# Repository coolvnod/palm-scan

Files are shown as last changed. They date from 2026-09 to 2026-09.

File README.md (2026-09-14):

# palm-scan

**Open palm-vein scanning — hardware, firmware and our own recognition model.** Hold your hand over the sensor; it reads the vein pattern under your skin and identifies you. Access control (a door release) is the first demo application, not the point.

<p align="center">
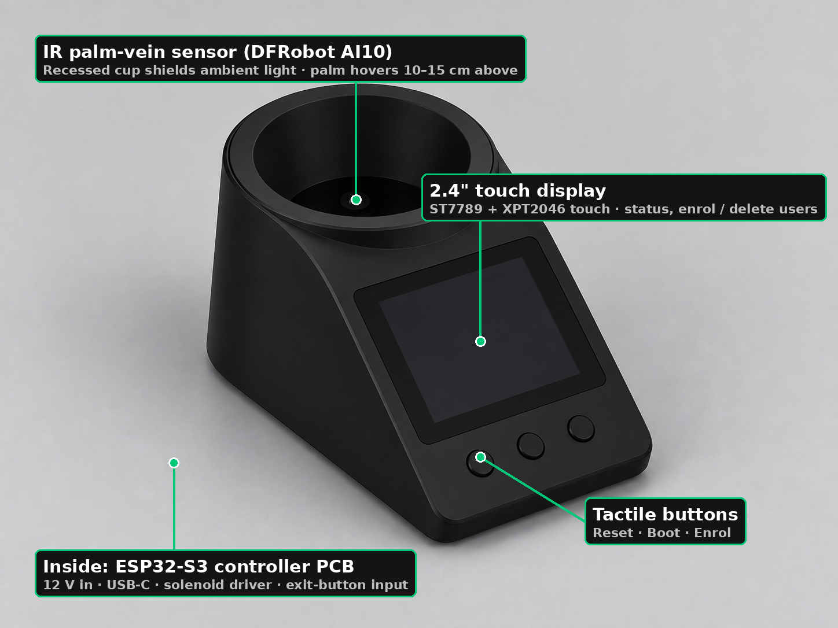
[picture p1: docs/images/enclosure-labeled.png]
palm-scan enclosure concept, labeled
  
</p>

No cards, no PINs, no fingerprints. Veins are *inside* the body — a photo of your hand, a silicone copy, or a lifted print does nothing. And the pattern only shows up when blood is flowing, so the scanner gets liveness detection for free. The goal is to understand and build the whole stack: NIR acquisition → preprocessing → feature extraction → matching — not just wire up a module.

| | |
|---|---|
| **Status** | Schematic **Rev 2.4** — reviewed twice, ERC clean, netlist verified. **PCB layout is next.** |
| **Controller** | ESP32-S3-WROOM-1 (N8R2), custom 2-layer PCB, 46 parts |
| **Sensor** | DFRobot AI10 (SEN0677) binocular palm-vein / face module, UART |
| **UI** | 2.4" 240×320 TFT + resistive touch, 2 panel LEDs, piezo buzzer |
| **Demo output** | 12 V fail-secure solenoid (door-release demo), MOSFET-driven, plus an exit button input |
| **Power** | 12 V 2 A adapter → polyfuse → reverse diode → TVS → 3.3 V + 5 V switching regulators |
| **Roadmap** | Firmware (ESP-IDF) → PCB → bring-up → **own CNN matcher** trained on NIR frames pulled from the sensor |

---

## How palm-vein recognition works

Blood carries haemoglobin. In the near-infrared window (**700–900 nm**) haemoglobin absorbs light much more strongly than the tissue around it. Shine NIR at a palm, and the veins show up as **dark shadows** on a camera that can see NIR — even though they're invisible to your eye. NIR penetrates only ~3.5 mm at 850 nm, which is exactly deep enough to reach the subcutaneous veins and no further.

<p align="center">
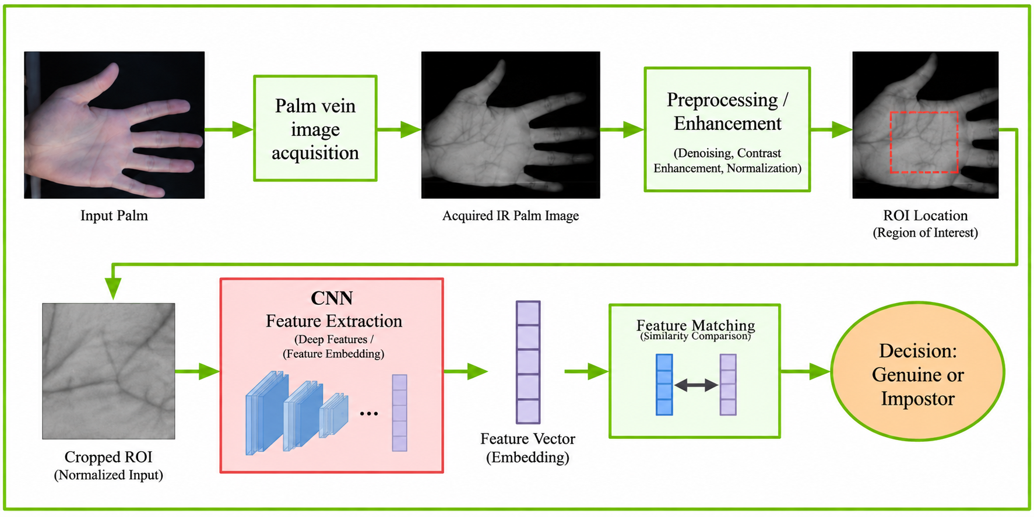
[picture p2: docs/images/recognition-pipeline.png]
Palm-vein recognition pipeline
  
</p>

Every palm-vein system, from a ₹3,000 module to a Fujitsu PalmSecure, runs the same four stages:

| Stage | What happens | In palm-scan |
|---|---|---|
| **1. Acquisition** | NIR LEDs illuminate the palm from the *same side* as the camera (reflection method — transmission needs LEDs bright enough to shine *through* your hand). | AI10 module: NIR LED array + NIR-sensitive camera, 240×320 output. |
| **2. Preprocessing / ROI** | Denoise, normalise contrast, then cut out a fixed **Region of Interest** — usually a square anchored on the finger-web valleys so the same patch of palm is compared every time, regardless of hand position. | Done inside the AI10 today. Our own ROI extraction is part of the CNN phase. |
| **3. Feature extraction** | Turn the ROI into a compact signature. Classical: Gabor filters, LBP, line/curvature detectors. Modern: a **CNN embedding** — a vector of a few hundred numbers. | AI10 built-in matcher now → own CNN embedding later. |
| **4. Matching** | Compare the signature with the enrolled templates. Hamming / cosine distance below a threshold → *genuine*, else *impostor*. Tuned on **EER** (equal error rate — where false accepts = false rejects). | Threshold set inside the AI10; `VERIFY` returns user ID + score. |

Why palm veins are a strong biometric — from Wu et al.'s 2019 review in *IET Biometrics*:

- **Uniqueness:** vein networks differ even between identical twins and between your own two hands.
- **Liveness:** no blood flow, no image. A severed or fake hand fails.
- **Robust:** dirt, cuts, wet or dry skin don't change what's *under* the skin.
- **Contactless:** nothing to touch, nothing to smudge.
- **Open problems** the paper flags — and that this project will run into: cheap acquisition hardware, ROI location without a hand guide, skin changes with age, and the fact that the best published deep-learning results are held back by tiny public datasets (CASIA ≈ 7,200 images, PolyU ≈ 6,000, VERA ≈ 2,200).

---

## System architecture

```mermaid
flowchart LR
    subgraph Field["Outside the box"]
        ADP["12 V 2 A adapter"]
        LOCK["12 V solenoid<br/>(door-release demo)"]
        EXIT["Exit button<br/>(inside room)"]
        PANEL["Panel LEDs<br/>green / red"]
    end

    subgraph PCB["palm-scan PCB (ESP32-S3)"]
        PWR["F1 polyfuse → D1 → D7 TVS<br/>+12V → R-78E 3.3 V / 5 V"]
        MCU["ESP32-S3-WROOM-1<br/>Wi-Fi · BLE · native USB"]
        DRV["Q1 AO3400A + D2 SS54<br/>lock driver + flyback"]
        USB["USB-C<br/>ESD + CC pull-downs"]
    end

    subgraph Modules["Plug-in modules"]
        AI10["AI10 palm-vein sensor<br/>UART 115200"]
        TFT["2.4-inch TFT + touch<br/>SPI"]
    end

    ADP --> PWR --> MCU
    PWR -- "+5V" --> AI10
    PWR -- "+12V" --> DRV --> LOCK
    AI10 <-- "UART1" --> MCU
    TFT <-- "FSPI" --> MCU
    MCU -- "IO4 LOCK_EN" --> DRV
    EXIT --> MCU
    MCU --> PANEL
    USB <--> MCU
```

**New here?** Read the [Wiring & Components Guide (PDF)](docs/palm-scan-wiring-guide.pdf) — every cable and part explained in plain words, with an A3 fold-out wiring diagram.

**Design decisions worth knowing** (full reasoning in [`docs/DESIGN_REVIEW.md`](docs/DESIGN_REVIEW.md)):

- **Solenoid is fed *after* the reverse-protection diode.** Rev 2.0 had it before — plugging the adapter in backwards would have shorted through the MOSFET's body diode. Caught in review.
- **Sensor runs on 5 V, not 12 V.** The AI10 accepts 5–12 V; at 12 V its internal regulator cooks. 5 V keeps it cool and makes the adapter's exact voltage irrelevant.
- **Display's SDO pin is left unconnected.** The ST7789 on these modules doesn't release MISO when deselected, so it fights the touch controller. Well-known trap; days lost by many.
- **Everything near the MCU is 3.3 V.** Display powered from +3V3, sensor UART assumed 3.3 V (measured before connection — see bring-up).
- **Fail-secure + watchdog.** If the demo output drives a door: power cut = locked, so the door must have a mechanical handle inside (fire-safety rule, not a preference). Firmware caps any release at 5 s with a hardware task watchdog — the solenoid is intermittent-duty and will burn if held on.

### GPIO map

| GPIO | Net | Role |
|---|---|---|
| IO4 | `LOCK_EN` | Solenoid driver gate (via 100 Ω, 10 k pull-down) |
| IO5 | `BUZZER` | Passive piezo |
| IO6 | `EXIT_BTN` | Exit button, RC-debounced |
| IO7 | `USB_DET` | VBUS sense, 100k/150k divider |
| IO8–IO14 | SPI + `TOUCH_IRQ` `TOUCH_CS` `TFT_CS` `TFT_DC` | Display and touch on FSPI (IOMUX pins) |
| IO17 / IO18 | `SEN_RX` / `SEN_TX` | UART1 to AI10 |
| IO19 / IO20 | `USB_D-` / `USB_D+` | Native USB |
| IO21 | `TFT_RST` | Display reset |
| IO1 / IO2 | `LED_OK` / `LED_DENY` | Panel LEDs |
| IO43 / IO44 | `TXD0` / `RXD0` | Debug UART header |
| IO0 | `BOOT` | Strapping — button only |
| IO3, IO45, IO46 | — | Strapping — deliberately unconnected |

---

## Repository layout

```
palm-scan/
├── README.md
├── docs/
│   ├── palm-scan-wiring-guide.pdf   Illustrated wiring & components guide (A3 fold-out) — start here
│   ├── wiring-guide/       Source for the guide (Python → SVG → PDF)
│   ├── COMPONENTS.md       BOM in three lists: fab-assembled / hand-soldered / off-board
│   ├── NETLIST.md          Plain-words net table — the source of truth the schematic is checked against
│   ├── POWER_BUDGET.md     Rail currents, derating, fuse/adapter analysis, trace widths
│   ├── DATASHEETS.md       Numbers extracted from every datasheet, with page refs
│   ├── DESIGN_REVIEW.md    Two review rounds (19 findings) and what changed because of each
│   ├── datasheets/         Source PDFs
│   └── images/
├── hardware/
│   └── kicad/              KiCad 9 project — 10 hierarchical sheets, generated from Python
│       ├── gen_schematic.py        Writes all .kicad_sch files from a parts/nets table
│       ├── check_netlist.py        Diffs KiCad's exported netlist against docs/NETLIST.md
│       ├── make_wiring_diagram.py  Off-board cable diagram (SVG/PDF)
│       ├── palm-scan.pdf           Schematic, all sheets
│       └── palm-scan-wiring.pdf    Cable diagram
├── firmware/               ESP-IDF application — not started
└── ml/                     CNN matcher — not started
```

**The schematic is code.** `gen_schematic.py` holds the parts and nets and emits the KiCad files; `check_netlist.py` then proves KiCad's own netlist export matches the human-readable `NETLIST.md` pin-for-pin (153/153). Change the table, rerun both, and the schematic, the docs and the verification stay in sync.

```bash
cd hardware/kicad
python3 gen_schematic.py                                   # regenerate sheets
kicad-cli sch erc  --output erc.txt        palm-scan.kicad_sch
kicad-cli sch export netlist --output palm-scan.net palm-scan.kicad_sch
kicad-cli sch export pdf --output palm-scan.pdf palm-scan.kicad_sch
python3 check_netlist.py                                   # must print "0 problems"
```

Requires KiCad ≥ 9.0 (`kicad-cli` on PATH) and Python 3.10+.

---

## Roadmap

| Phase | Deliverable | State |
|---|---|---|
| 1 | Schematic, BOM, power budget, two design reviews | ✅ Rev 2.4 |
| 2 | Firmware: AI10 UART driver, enrol/verify flow, TFT UI, output state machine + watchdog | ⬜ |
| 3 | PCB layout, DRC, Gerbers, order (JLCPCB assembly for the 32 SMD parts) | ⬜ |
| 4 | Bring-up: rail checks, sensor level check, first recognition on the bench | ⬜ |
| 5 | Enclosure (the render above is the concept; CAD to follow) | ⬜ |
| 6 | **Own CNN matcher** — see below | ⬜ |

Firmware comes before PCB on purpose: the sensor and display can be driven from an ESP32-S3 devkit on a breadboard today, so the protocol and UI get debugged while the board is being made, not after.

### Phase 6 — a CNN of our own

The AI10 does its matching on-chip and we don't get to see how. That's fine for a demo, but the point of this project is to build and understand the recognition itself. The plan:

1. **Harvest images.** The AI10's protocol has `MID_SNAP&UPLOAD_IMAGE` (0x71): it captures and streams a 240×320 JPEG over UART in 1 KB packets. So the sensor doubles as an NIR camera for dataset collection — no extra hardware.
2. **Build a dataset.** Our own small one (multiple sessions, both hands, varied height and angle — the paper's warning about tiny datasets applies), plus a public set (CASIA-MS-Palmprint or PolyU) for pre-training.
3. **ROI extraction.** Finger-valley keypoints → fixed square crop, following the classical method the review describes. This is where most of the real-world failures live.
4. **Train an embedding network.** Small CNN (MobileNet-class) trained with a metric loss (triplet / ArcFace) so genuine pairs land close and impostors far apart. Training runs on Kaggle GPUs, never on the laptop.
5. **Evaluate properly.** ROC curve, EER, FAR at fixed FRR — not "accuracy".
6. **Deploy.** Two options, decided by the numbers: quantised INT8 on the ESP32-S3 via ESP-DL (the S3 has vector instructions for exactly this), or on a small Linux SBC if the model won't fit. The AI10 stays as a reference matcher to benchmark against either way.

---

## Bring-up checklist (before first power-on)

Read [`docs/POWER_BUDGET.md`](docs/POWER_BUDGET.md) §7 first. Non-negotiable items:

- [ ] Adapter is **12 V regulated, ≥ 1.5 A** — 9 V will not run the regulators.
- [ ] Measure the AI10's green TX wire idle level **before** plugging it in — must be ≤ 3.6 V. If it reads 5 V, fit a divider; the ESP32 is not 5 V tolerant.
- [ ] Confirm the display module's pin order against its silkscreen (the manual gives names, not positions).
- [ ] Solenoid: confirm intermittent vs continuous duty on the listing; measure coil current — if > 0.8 A move F1 to a 3 A-hold part.
- [ ] Buzzer must be a **passive piezo**, not a magnetic one — the pin drives it directly.
- [ ] Use **J1 or J8** for power, never both.
- [ ] If wired to a door: it has a handle on the inside.

Tools that matter: a multimeter (not optional), `idf.py monitor`, and `kicad-cli` for regenerating outputs.

---

## References

- W. Wu, S. J. Elliott, S. Lin, S. Sun, Y. Tang, "Review of palm vein recognition," *IET Biometrics*, vol. 9, no. 1, pp. 1–10, 2020. doi:10.1049/iet-bmt.2019.0034
- DFRobot SEN0677 wiki — https://wiki.dfrobot.com/sen0677/ · protocol manual in [`docs/datasheets/`](docs/datasheets/)
- Espressif, *ESP32-S3-WROOM-1 Datasheet* v1.8 · ESP-DL — https://github.com/espressif/esp-dl
- RECOM R-78E series; Alpha & Omega AO3400A; Vishay SS34 — all in [`docs/datasheets/`](docs/datasheets/)

---

## Makers

- [Ashmita K Rao](https://github.com/ashmita1032-prog)
- [Adithya Satish](https://github.com/adithyasathish10)
- [Vinod Kumar](https://github.com/coolvnod)

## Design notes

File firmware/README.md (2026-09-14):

# firmware

ESP-IDF application for the palm-scan controller. Not started.

Planned modules, in build order:
1. `ai10/` — UART driver for the DFRobot AI10: frame codec (`EF AA id len data xor`), `RESET`, `GET_STATUS`, `VERIFY`, `ENROLL`, `DEL_USER`, `SNAP&UPLOAD_IMAGE`. Wait for `NOTE:READY` after power-up before sending anything.
2. `lock/` — solenoid state machine. Hard 5 s cap per unlock, task watchdog, `LOCK_EN` low on any fault or reset.
3. `ui/` — LVGL on the 2.4" TFT (ST7789/ILI9341 autodetect) + XPT2046 touch. Screens: idle, recognised, denied, enrol, user list.
4. `app/` — glue: exit button, panel LEDs, buzzer, USB detect, logging.

Develop on an ESP32-S3 devkit + breadboard first; the custom PCB is not required for any of this.

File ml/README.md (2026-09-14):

# ml

Own palm-vein matcher (CNN embedding). Not started — see README.md → Roadmap → Phase 6.

Planned layout:
- `capture/` — pull 240×320 NIR JPEGs from the AI10 over UART (`0x71`), tag by user/session/hand.
- `roi/` — finger-valley keypoints → normalised square crop.
- `train/` — Kaggle notebooks: MobileNet-class backbone, triplet/ArcFace loss, pre-train on CASIA/PolyU, fine-tune on our set.
- `eval/` — ROC, EER, FAR@FRR.
- `deploy/` — INT8 quantisation, ESP-DL export.

Training runs on Kaggle GPUs only.

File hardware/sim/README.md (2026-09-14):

# Circuit simulations (ngspice — the engine inside KiCad)

| File | What |
|---|---|
| `lock_driver.cir` | Solenoid driver: Q1 AO3400A (VDMOS model fitted to the datasheet) + D2 SS54 flyback + 12 V / 15 Ω / 60 mH coil, driven by a 3.3 V GPIO pulse. Two runs: with D2, and without D2 (Q1 avalanche modelled at 32 V). |
| `run_sim.py` | Runs the netlist through `libngspice` (or the `ngspice` CLI if installed), prints the key numbers, writes `lock_driver.png`. |

```bash
python3 run_sim.py
```

Results, Rev 2.4 values (2026-09-14): gate 3.26 V · coil 0.78 A, L/R 3.8 ms · Rds(on) 40 mΩ, 24 mW in Q1 ·
turn-off with D2 peaks 12.4 V (D2 carries 0.79 A) · without D2, Q1 avalanches at 32 V and absorbs 21 mJ per release.

Coil inductance is an assumption (60 mH); measure the real lock and update `LCOIL`.

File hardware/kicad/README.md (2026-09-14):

# kicad/ — palm-scan Rev 2 schematic

| File | What |
|---|---|
| `palm-scan.kicad_pro` / `.kicad_sch` | Root sheet. Open with `kicad palm-scan.kicad_pro` |
| `power_in`, `power_reg`, `mcu`, `reset_boot`, `usb`, `lock`, `display`, `exit`, `buzzer` `.kicad_sch` | Sub-sheets (pages 2–10), A4 |
| `palmscan.kicad_sym` + `sym-lib-table` | Project symbol library: stock KiCad symbols scaled 1.5× for readability. Footprints are unchanged. |
| `palm-scan.pdf` | Rendered schematic, 10 pages |
| `palm-scan.net` | KiCad's exported netlist |
| `erc.txt` | Last ERC report (0 errors, 0 warnings) |
| `gen_schematic.py` | Generator. The `PARTS` list is the netlist. |
| `check_netlist.py` | Diffs `palm-scan.net` against `../../docs/NETLIST.md` |

## Regenerate after a change

```
python3 gen_schematic.py
kicad-cli sch erc --output erc.txt palm-scan.kicad_sch
kicad-cli sch export netlist --format kicadsexpr --output palm-scan.net palm-scan.kicad_sch
python3 check_netlist.py
kicad-cli sch export pdf --output palm-scan.pdf palm-scan.kicad_sch
```

Nets are **global labels** — the same name on any page is the same wire.
Pages are defined in `PAGES`; a box that does not fit its page fails loudly.

Edit `PARTS` in the generator *and* the table in `../../docs/NETLIST.md` — the checker
exists precisely so the two can't drift apart silently.

## If you edit in the KiCad GUI instead

Fine — but then stop running the generator, it will overwrite your edits.
Move the wires around, keep the net names.

## One-sheet wiring diagram

`palm-scan-wiring.pdf` / `.svg` — every connection drawn as a wire, ESP32 in the middle.
Generated from `palm-scan.net` by `make_wiring_diagram.py` (needs `netlistsvg` from npm and
`cairosvg` from pip; `wiring_skin.svg` is the box/tag style). Not editable in KiCad — it is a
*picture* of the netlist and can never disagree with the schematic. Regenerate after any change:

```
kicad-cli sch export netlist --format kicadsexpr --output palm-scan.net palm-scan.kicad_sch
python3 make_wiring_diagram.py /path/to/node_modules/.bin/netlistsvg
```

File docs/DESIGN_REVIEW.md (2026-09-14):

# DESIGN_REVIEW.md — Rev 2 schematic, senior design review (2026-09-13)

> **Status: all 7 fixes applied → Rev 2.1.** ERC 0/0, netlist 131/131, scripted pass 2 clean. Layout notes below still apply.

Two passes: (1) block-by-block read as a reviewer, (2) scripted checks on KiCad's own
exported netlist (`../hardware/kicad/check_netlist.py` + ad-hoc checks). ERC 0/0. Netlist 125/125.

Severity: 🔴 will break hardware  🟠 will cause a bug you'll chase for days  🟡 should fix  🟢 fine

---

## 🔴 1. Plugging the adapter in backwards destroys Q1 and D2

**What happens.** D1 protects the "+12V" rail. But the lock is fed from `VIN_12V` — *before* D1.
Reverse the adapter and current flows: GND → Q1's body diode → LOCK_SW → D2 → VIN_12V.
That's a dead short across the adapter through two tiny parts. They die in under a second.

**Why it slipped in.** COMPONENTS.md wanted the lock's inrush kept away from C1. Good idea,
wrong place — it moved the lock outside the protection.

**Fix.** Feed the lock from `+12V` (after D1). D1 is rated 3 A; the lock's 2 A inrush is fine.
Change J3 pin 1 and D2 cathode from `VIN_12V` → `+12V`. Zero new parts.

**Also add a fuse.** F1, 2 A resettable polyfuse, in series right after J1. ₹5. Without it, any
short on the board (including this one) relies on the adapter's protection, which cheap adapters don't have.

## 🟠 2. Display and touch fight over MISO

`SPI_MISO` goes to both the ST7789 (J4 pin 9, SDO) and the XPT2046 touch (J4 pin 13, T_DO).
On these red display boards the ST7789's SDO does **not** release the line when its CS is high.
Result: touch reads garbage, or the screen stops updating after the first touch. Very well-known
problem with this exact module; people spend days on it.

**Fix.** Leave J4 pin 9 unconnected. The firmware never reads from the display. Touch keeps MISO.

## 🟠 3. Sensor is at the very top of its voltage range

AI10 spec: 5–12 V. We give it 12 V. Cheap "12 V" adapters give 12.5–13.5 V with light load.
The sensor's internal regulator then runs hot ("chip heating is normal" says the wiki — at 12 V it's hotter).

**Fix, recommended.** Make U3 a `R-78E5.0-1.0` (1 A, same footprint, same pins) and feed the sensor
from `+5V`. CN1 pin 4 → `+5V`. 5 V rail total ≈ 650 mA, inside 1 A. Sensor runs cool, and the
adapter's exact voltage stops mattering.

## 🟠 4. Solenoid can cook itself if firmware hangs with the lock open

Most 12 V solenoid locks are **intermittent duty** — energised for 10 s max, then they overheat.
If the ESP32 crashes with `LOCK_EN` high, the coil stays on until it burns.

**Fix.** Two layers:
- Firmware: hardware task watchdog (built into ESP-IDF) + a hard cap of 5 s on any unlock.
- Buy: a solenoid rated **continuous duty** if you ever need "hold open". Check the listing.

Also **fail-secure means power cut = door locked.** The door MUST be openable from inside by a
handle. That's a fire-safety rule, not a preference. Never fit this on a door without one.

## 🟡 5. No sign of life if the MCU doesn't boot

"The screen replaces the LEDs" — only after the MCU boots. First power-up with a dead 3.3 V rail
shows nothing at all. One LED + resistor on +3V3 (2 parts, ₹2) tells you the regulator works.

**Fix.** Add D4 (green 0603) + R7 (1 kΩ) from +3V3 to GND.

## 🟡 6. Exit-button wire has no surge protection

The exit button wire runs to the other side of the wall. It's an antenna for static and for
whatever the electrician ran next to it. R6/C11 debounce it; nothing limits current into IO6.

**Fix.** R8, 1 kΩ in series between J5 pin 1 and the IO6 net. Costs ₹1, saves the GPIO.

## 🟡 7. C9 is redundant

C9 (100 nF across RESET) is on the same net as C4 (1 µF, EN to GND). C4 already does the job.
**Fix.** Delete C9. −1 part.

## 🟢 Verified correct (both passes)

- D1 orientation, D2 orientation, Q1 low-side wiring, R2 gate pull-down.
- USB-C: CC1/CC2 5.1 kΩ, D+/D− on IO20/IO19, ESD array, VBUS isolated.
- EN: 10 kΩ + 1 µF per Espressif. BOOT on IO0. Strapping pins IO3/45/46 floating.
- UART crossing: ESP TX → sensor RX (yellow), ESP RX → sensor TX (green). 3.3 V logic both sides.
- 3.3 V rail: 110 µF total, under RECOM's 220 µF limit. C3 on the module's 3V3 pin.
- Every net has ≥2 connections; every GPIO net touches exactly one ESP32 pin.
- R-78E input 7–28 V; 12 V adapter fine. Regulators run cool.

## Things that only matter at PCB layout — write these down for Flux

1. **Antenna keep-out.** ESP32-S3-WROOM-1 antenna end must hang off the board edge, or sit over a
   15 mm no-copper zone on *all* layers. Ignore this and WiFi range drops to a metre.
2. **C3 within 5 mm of U1 pin 2.** Not "nearby". 5 mm.
3. **Lock current traces ≥ 1 mm wide** (J1 → F1 → D1 → J3 → Q1 → GND). 2 A inrush.
4. **Q1 source straight to J1 GND**, not through the ESP32's ground area. Lock return current
   through the MCU ground = resets when the lock fires.
5. **D3 within 5 mm of the USB connector**, on the D+/D− traces, before they go anywhere else.
6. **D1 on a big copper pour** — it's the only part that gets warm.
7. **Display ribbon under 10 cm** or drop SPI to 20 MHz. 40 MHz over a long ribbon = garbage pixels.
8. **PicoBlade CN1 near the board edge** the sensor cable comes from — cable is short.
9. **M3 holes in the corners**, 3.2 mm, with 6 mm keep-out.

## How this project can still fail after all the above (honest list)

| Failure | How likely | What stops it |
|---|---|---|
| Wrong adapter (9 V or 19 V laptop brick) | common | 9 V: sensor and regs OK. 19 V: C1 is 25 V, regs 28 V — survives. Label the socket. |
| Adapter dies at 2 am, door locked | certain, eventually | Inside handle. Non-negotiable. |
| Sensor doesn't recognise wet/cold hands | happens | Firmware fallback: exit button, and long-term a keypad. Hardware can't fix it. |
| Someone unplugs the sensor cable while powered | user error | PicoBlade tolerates hot-plug. Firmware must re-init the sensor when it comes back. |
| Water on the board | outdoor install | Enclosure IP rating. Conformal coat is ₹200. |
| Firmware bug opens the lock | code error | Upstream design: `loop()` is the only path that can unlock. Keep that. |
| Flash corrupted, USB boot dead | rare | J6 UART header. That's why it's there. |
| Solenoid rated wrong (AC, or 24 V) | ordering error | Buy 12 V DC, ≤1 A, continuous duty, and read the listing twice. |
| Board ordered before sim/bring-up plan | you | Bring-up order: power only → check rails → add MCU → USB flash → add display → add sensor → add lock last. |

---

## About Flux

Flux imports **KiCad part libraries only** — not schematics, not projects. There is no
"open the KiCad file in Flux". You would redraw all 34 parts in Flux by hand from NETLIST.md.

Options, ranked:
1. **PCB in KiCad.** Schematic is already here, ERC-clean, footprints assigned. One click to PCB.
   Zero rework. Best choice unless you specifically want Flux's autorouter/AI.
2. **Flux, redraw from NETLIST.md.** ~1–2 hours. Then you have two sources of truth and every
   change must be made twice. Only worth it if you want to learn Flux itself.

## Changes to apply, in one go

| # | Change | Parts |
|---|---|---|
| 1 | Lock + D2 cathode fed from `+12V` instead of `VIN_12V` | 0 |
| 1 | F1 2 A polyfuse after J1 | +1 |
| 2 | J4 pin 9 (display SDO) → no-connect | 0 |
| 3 | U3 → R-78E5.0-1.0; CN1 pin 4 → `+5V` | 0 |
| 5 | D4 LED + R7 1 kΩ on +3V3 | +2 |
| 6 | R8 1 kΩ series on exit button | +1 |
| 7 | Delete C9 | −1 |

Net: 34 → 37 parts.

---

## Appendix — checklist verification (2026-09-13, Rev 2.1)

| Item | Result | Evidence |
|---|---|---|
| D1 polarity | ✅ | KiCad netlist: D1 pin 1 (K) = `+12V`, pin 2 (A) = `VIN_FUSED`. Current flows adapter → F1 → A → K → board. |
| 2 A polyfuse vs solenoid | ✅ with a spec | Steady load ≈ 1.35 A (lock 1 A + regulators 0.35 A); inrush ≈ 2.4 A for < 100 ms. A 2 A-hold / 4 A-trip 1812 polyfuse (e.g. Littelfuse 1812L200/16) needs seconds at 2× to trip. Buy one rated ≥ 16 V. If the solenoid measures > 0.8 A, go to 3 A hold. |
| BOOT cap / pull-up | ✅ | IO0: S2 to GND + C10 100 nF; pull-up is the chip's internal strap pull-up (Espressif devkit does the same). EN RC (10 ms) is longer than IO0's RC (~4.5 ms), so IO0 is high before the strap is sampled. |
| ST7789 voltage | ✅ (module not in hand) | VCC = 5 V → module's on-board LDO → 3.3 V logic. ESP32 3.3 V SPI matches. Manual specifies 5 V VCC. **Physically confirm the LDO on the board before power-up**; if absent, VCC must move to +3V3. |
| Buzzer type & driver | ✅ after change | Must be a **passive piezo element** (capacitive load). R5 changed 100 Ω → 220 Ω: edge current 15 mA vs IOH 40 mA. A magnetic buzzer (coil) would need a transistor — don't buy one. |
| GPIO conflicts | ✅ | 18 GPIOs used, none twice. USB on IO19/20 only. FSPI on IO10–13 (IOMUX, fastest). Strapping IO0 = BOOT only; IO3/45/46 floating. JTAG IO39–42 free. UART0 IO43/44 only on J6. No ADC2 use (would conflict with Wi-Fi). N8R2 quad PSRAM uses no GPIO. |
| Power / ground / decoupling | ✅ | +3V3: C2 100 µF, C3 100 nF, C6 10 µF. +5V: C8 10 µF. +12V: C1 470 µF, C5, C7 10 µF. EN: C4 1 µF. U1 GND on pins 1, 40, 41 (EPAD). U2/U3 GND pin 2. VBUS: no cap needed (data-only). |
| MOSFET + flyback ratings | ✅ | AO3400A: 30 V ≥ 12.5 V clamped, 5.7 A ≥ 2 A inrush, VGS(th) max 1.45 V < 3.3 V drive, RDS(on) ≈ 40 mΩ → 40 mW. SS54: 40 V ≥ 12 V, 5 A ≥ 1 A, 150 A surge. R2 10 kΩ keeps gate low through reset. |
| USB-C CC / ESD | ✅ | CC1 → R3 5.1 kΩ → GND, CC2 → R4 5.1 kΩ → GND (sink, both orientations). D+ on A6+B6, D− on A7+B7. USBLC6-2SC6: pins 1/6 = I/O1 on D−, pins 3/4 = I/O2 on D+, pin 2 GND, pin 5 VBUS — matches the KiCad symbol's pin names. |
| **PCB fabrication-ready** | ❌ **No** | There is no PCB. The **schematic** is ready for layout. Fabrication-ready means Gerbers that pass DRC — that's the next project phase. |

---

## Response to the Flux review (2026-09-14) → Rev 2.4

Flux found 12 items. Verdict on each, with evidence:

| # | Flux finding | Verdict | What was done |
|---|---|---|---|
| 1 | AI10 UART level unconfirmed | **Valid — not in the wiki.** Evidence it is 3.3 V: DFRobot's own library lists FireBeetle-ESP32, ESP8266 and M0 (all 3.3 V-only, non-5 V-tolerant) as "works well" wired directly; the techiesms build drives a classic ESP32 directly. Net naming is from the *sensor's* view (SEN_RX = sensor RX ← ESP TX), checked in the netlist. | No change. **Bring-up step added:** before plugging CN1 into the board, power the sensor and measure its TX (green) wire — UART idle is HIGH, must read ≤ 3.6 V. |
| 2 | Display pinout/levels unconfirmed | **Partly valid.** Pin *order* is the standard 2.4" red-board order (manual lists names, not positions) — must be checked against the silkscreen when the module arrives. Level risk: real if any module output ran at 5 V. | **Display moved to 3.3 V** (J4 pins 1 and 8 → +3V3; module is rated 3.3–5 V per Robu). Now nothing near the MCU carries 5 V. Backlight slightly dimmer. 5 V rail is sensor-only. |
| 3 | C2 100 µF/16 V in 0805 unrealistic | **Correct, my mistake.** No such MLCC exists; 100 µF MLCC starts at 1210/6.3 V and halves under bias. | C2 → **100 µF 10 V SMD electrolytic/polymer, 6.3 × 5.4** (same part as C12). Still within RECOM's 220 µF limit (110 µF total). |
| 4 | R-78E 1.0 A footprint vs 0.5 A | **Checked — identical package.** Both datasheets: 11.6 × 8.5 × 10.4 mm, 2.54 mm pitch, 0.51 mm pins. Footprint drill 1.0 mm. | No change. |
| 5 | No VBUS sensing | **Valid for USB compliance**; harmless in practice. | Added **R11 100k / R12 150k divider → IO7 (`USB_DET`, 3.0 V)**. Firmware can show "USB connected" and hold off D+ pull-up when absent. |
| 6 | No gate series resistor | **Valid, cheap.** | Added **R13 100 Ω** IO4 → gate. R2 10k stays gate-to-source. |
| 7 | No TVS on 12 V | **Valid** — lock cable is an antenna, Q1 is only 30 V. | Added **D7 SMAJ15A** across +12V/GND (15 V standoff, ~24 V clamp). |
| 8 | F1 vs 2 A adapter | **Already analysed** in POWER_BUDGET §3: with a 2 A adapter F1 never trips on a short — the adapter self-protects; F1 guards against an oversized adapter. | Documented, no change. |
| 9 | C5/C7 10 µF 50 V in 0805 | **Correct, my mistake.** | C5/C7 → **1210 X7R**. Effective ~6 µF at 12 V bias; RECOM marks these caps optional and C1 470 µF is on the same rail. |
| 10 | J1/J8 paralleled, needs warning | **Valid.** | Text added on the schematic page: "Use J1 OR J8 — never both. Centre pin of J8 is +." Will go on silkscreen too. |
| 11 | USB shield straight to GND | **Acceptable for a prototype**; RC to chassis is an EMC-lab refinement. | Documented decision, no change. |
| 12 | Exit-button cable ESD | **Acceptable** — R8 1k + C11 100 nF + ESP32 internal clamps. | Documented. Layout rule: exit-button cable must not run alongside lock wiring. |

Procurement checks Flux listed (CN1 pitch, J4 pin-1 orientation, J8 footprint vs the bought DC-005, U2/U3 body, C2 exact part, F1 variant, piezo vs magnetic, USB-C MPN) are all already in COMPONENTS.md / POWER_BUDGET §7 as "verify against the physical part before ordering the PCB".

**Rev 2.4 verification:** ERC 0/0 across 10 sheets; NETLIST.md ↔ KiCad netlist 153/153 pins; 27 scripted end-to-end checks pass (see session log / `check_netlist.py`). 46 on-board parts, 38 nets.

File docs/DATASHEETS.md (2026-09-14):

# DATASHEETS.md — reference facts for the palm-scan Rev 2 schematic

Every number here was pulled from the manufacturer document (or the vendor
wiki) on 2026-09-13. Local copies live in `datasheets/`. When something is
from memory or a secondary source it is marked **(unverified)**.

---

## 1. Power parts

### U2 — RECOM R-78E3.3-1.0  (`datasheets/R-78E-1.0.pdf`)
- Input 7–28 V, output 3.3 V @ 1.0 A, efficiency 91 % at full load.
- Pins (SIP-3, 2.54 mm pitch): **1 = +Vin, 2 = GND, 3 = +Vout**. Same as a 7805.
- Quiescent 1.5 mA, switching at 570 kHz. No heat-sink needed.
- Input/output caps are *optional* per RECOM: 10 µF MLCC each. We fit them anyway.
- **Max capacitive load on the output: 220 µF.** Our C2 (100 µF) is inside that.
- Minimum load 2 % — the ESP32 alone is far above that.

### U3 — RECOM R-78E5.0-0.5  (`datasheets/R-78E-0.5.pdf`)
- Input 7–28 V, output 5 V @ 0.5 A, efficiency 92 %.
- Same pinout as U2. Same 10 µF in/out caps. Same 220 µF output limit.

### Q1 — AOS AO3400A, N-channel MOSFET  (`datasheets/AO3400A.pdf`)
- VDS 30 V, ID 5.7 A continuous (25 °C), 30 A pulsed. Package SOT-23.
- **RDS(on) < 48 mΩ at VGS = 2.5 V** → at our 3.3 V gate it is fully on.
- VGS(th) 0.65–1.45 V. Qg 6 nC — tiny, the GPIO can drive it directly.
- Pinout SOT-23: **1 = G, 2 = S, 3 = D** (standard).
- At 1 A lock current: P = 1² × 0.05 = 50 mW. Stays cold. ✅

### D1 — SS34 Schottky, reverse-polarity + reservoir isolation  (`datasheets/SS34.pdf`, Vishay)
- VRRM 40 V, IF 3 A, VF ≈ 0.5 V at 3 A.
- **Package: SMA (DO-214AC)** — the JLCPCB-stocked version (LCSC C8678). Vishay's PDF here is the SMC
  variant; electrical specs are the same, SMA is thermally a bit worse.
- Heat check (Rev 2.3): everything incl. the lock goes through D1 → 1.05 A for ≤ 5 s → 0.53 W bursts, 0.13 W idle.
  SMA ≈ 90 °C/W on a minimal pad → +12 °C idle; bursts are too short to matter. Give it a copper pour anyway.

### D2 — SS54 Schottky, lock flyback  **(secondary source — components101, Newark)**
- VRRM 40 V, IF 5 A, VF ≈ 0.55 V, surge 150 A, package SMC (DO-214AB).
- Any 40 V / ≥3 A Schottky works here. SS34 would also do; SS54 is just more margin.

### C1 / C2 / C3 — generic; only ratings matter
- C1 470 µF 25 V electrolytic on the 12 V input (after D1). Ripple-current rated, low ESR.
- C2 100 µF 16 V on 3.3 V (≤ 220 µF limit above). Ceramic or polymer, not a cheap electrolytic.
- C3 100 nF 0603 X7R at the module's 3V3 pin — Espressif requires this.
- **Added by the datasheets, not in COMPONENTS.md:** 4 × 10 µF MLCC (U2/U3 in+out) and
  1 × 1 µF on EN. See §2.

---

## 2. ESP32-S3-WROOM-1  (`datasheets/esp32-s3-wroom-1.pdf`, v1.8)

- 41 pins (40 + EPAD). 3V3 on pin 2, GND on 1 / 40 / EPAD. EN on pin 3.
- Supply: 3.0–3.6 V, **≥ 500 mA** recommended. Wi-Fi TX peaks ≈ 350–400 mA.
- GPIO drive: IOH 40 mA, IOL 28 mA per pin.
- **EN pin: Espressif requires R = 10 kΩ pull-up + C = 1 µF to GND** (RC delay so
  3V3 is stable before the chip releases reset). COMPONENTS.md had only the resistor. Add C4 = 1 µF.
- Do not leave EN floating. Reset button = EN to GND.

### Strapping pins — keep these free or know what you're doing
| GPIO | Controls | Default | Our use |
|---|---|---|---|
| 0  | boot mode | pull-up (normal boot) | BOOT button to GND (S2) — this is its intended use |
| 3  | JTAG source | — | **leave unconnected** |
| 45 | VDD_SPI voltage | pull-down (3.3 V) | **leave unconnected** — pulling high sets flash to 1.8 V and bricks boot |
| 46 | boot mode + ROM print | pull-down | **leave unconnected** |

### Pins we cannot use
- IO26–IO32 are internal (flash) and not on the module. IO35/36/37 are PSRAM on R8 modules.
- IO19 / IO20 = **USB D− / D+**. Reserved for J2.
- IO43 / IO44 = UART0 TX/RX (boot messages). Keep free for debugging, or reuse for the sensor? → **No**, ROM prints garbage on it at boot and the sensor would see it. Use UART1.

### Module pin numbers we will wire (module pin → GPIO)
- pin 4 IO4, 5 IO5, 6 IO6, 7 IO7, 8 IO15, 9 IO16, 10 IO17, 11 IO18, 12 IO8,
  13 IO19 (USB D−), 14 IO20 (USB D+), 15 IO3, 16 IO46, 17 IO9, 18 IO10, 19 IO11, 20 IO12,
  21 IO13, 22 IO14, 23 IO21, 24 IO47, 25 IO48, 26 IO45, 27 IO0, 28 IO35, 29 IO36, 30 IO37,
  31 IO38, 32 IO39, 33 IO40, 34 IO41, 35 IO42, 36 RXD0/IO44, 37 TXD0/IO43, 38 IO2, 39 IO1.

---

## 3. Display — SmartElex 2.4" ST7789V + XPT2046 resistive touch  (`datasheets/smartelex-2.4-touch.pdf`)

- 240 × 320, RGB565, SPI. Driver ST7789V. Touch controller XPT2046 (also SPI).
- 14-pin 2.54 mm header, in this order (this is the standard "red board" layout):

| Pin | Name | Goes to |
|---|---|---|
| 1 | VCC | 5 V (module has on-board 3.3 V LDO) |
| 2 | GND | GND |
| 3 | CS | ESP32 GPIO (TFT_CS) |
| 4 | RESET | ESP32 GPIO (TFT_RST) |
| 5 | DC | ESP32 GPIO (TFT_DC) |
| 6 | SDI (MOSI) | SPI MOSI |
| 7 | SCK | SPI SCK |
| 8 | LED | backlight, 5 V (or 3.3 V, dimmer) |
| 9 | SDO (MISO) | SPI MISO |
| 10 | T_CLK | SPI SCK (shared) |
| 11 | T_CS | ESP32 GPIO (TOUCH_CS) |
| 12 | T_DIN | SPI MOSI (shared) |
| 13 | T_DO | SPI MISO (shared) |
| 14 | T_IRQ | ESP32 GPIO, optional (manual says "not required") |

- Logic is 3.3 V; the on-board LDO makes 3.3 V from the 5 V VCC. ESP32 SPI drives it directly.
- **Correction to COMPONENTS.md:** the 5 V rail feeds VCC *and* LED, not "only the backlight".
- **Design option (decide in III):** these boards run fine with VCC = 3.3 V and LED = 3.3 V.
  That would delete U3 and its two caps (3 parts) and put ~100 mA more on U2's 1 A rail.
  Backlight is dimmer at 3.3 V. Keeping U3 for now; flagged.
- SPI: ST7789 tolerates 40–80 MHz; XPT2046 must be clocked ≤ 2.5 MHz — the firmware
  switches SPI speed per chip-select, hardware doesn't care.

---

## 4. Palm sensor — DFRobot AI10 (SEN0677)  (wiki.dfrobot.com/sen0677/ + `datasheets/SEN0677_AI10_protocol_manual_V1.0.pdf`)

- The PDF is the **software protocol manual only** (frame format, every command, flowcharts). It has no electrical data. Everything below is from the wiki.
- Supply **5–12 V**. Operating 320–330 mA @ 8 V. Standby 120–130 mA. Rev 2.4 feeds it from **+5V** (U3, 1 A).
- UART, **115200 baud**. Protocol: `EF AA CMD LenH LenL payload XOR`. On power-up the module sends `NOTE:READY` — firmware must wait for it before sending commands.
- UART logic level is **NOT documented anywhere**. Assumed 3.3 V because DFRobot's library lists 3.3 V-only boards (FireBeetle-ESP32/ESP8266/M0) as wired directly. **Bring-up rule: measure the green TX wire idle level before connecting CN1 — must be ≤ 3.6 V.** If it reads 5 V, add a 1k/2k divider on SEN_TX → U1RXD.
- UART connector, 4-pin 1.25 mm (PicoBlade-style), pinout:

| Pin | Colour | Function | Wire to |
|---|---|---|---|
| 1 | Black | GND | GND |
| 2 | Yellow | UART_RX (sensor listens) | ESP32 **TX** (U1TXD) |
| 3 | Green | UART_TX (sensor talks) | ESP32 **RX** (U1RXD) |
| 4 | Red | VCC 5–12 V | +5V (U3 output) |

- Crossed naming is the #1 wiring mistake here — sensor RX ← ESP TX. Label the schematic nets
  `SEN_RX` / `SEN_TX` from the *sensor's* point of view, like the upstream firmware does.
- Has a separate USB port (UVC camera) needing 5 V — we do not wire it. Wiki: "chip heating is normal".
- Recognition distance: palm 15 cm. Dimensions 57.8 × 20 × 10.12 mm.
- **(unverified)** Exact mating header part number. Molex 53047-0410 (PicoBlade 1.25 mm, 4-way,
  vertical THT) is the standard choice. Check the pitch on the physical sensor cable before ordering.

---

## 5. USB-C, ESD, connectors, switches

### J2 — USB-C receptacle, 16-pin USB 2.0 only
- Part: HRO TYPE-C-31-M-12 (JLCPCB C165948) or GCT USB4105-GF-A. **(unverified — confirm stock)**
- Wire: VBUS ×4 → 5 V_USB net; GND ×4 + shell → GND; D+ (A6 and B6 tied) → IO20; D− (A7, B7 tied) → IO19.
- CC1 → R3 5.1 kΩ → GND; CC2 → R4 5.1 kΩ → GND. This advertises "sink, default USB power".
- SBU1/SBU2 unconnected.
- USB VBUS must **not** feed the 3.3 V regulator (its minimum input is 7 V). Desk power over USB
  needs its own path — see design decision in III.

### D3 — ST USBLC6-2SC6, USB ESD array  **(pinout from memory — verify against the KiCad symbol)**
- SOT-23-6. Pin 1 = I/O1, 2 = GND, 3 = I/O2, 4 = I/O2, 5 = VBUS, 6 = I/O1.
- I/O1 pair and I/O2 pair are internally the same node — use one pin of each, or route through.
- Place within 5 mm of the connector, on the D+/D− traces.

### CN1 — Molex PicoBlade 53047-0410  (1.25 mm, 4-way, vertical THT)
- 1 A per contact, plenty for 330 mA. KiCad footprint exists in the standard library.

### J1 / J3 / J5 — screw terminals
- J1 (12 V in) and J3 (lock): **5.08 mm pitch** (KF301 / Phoenix MKDS type) — takes 18 AWG.
- J5 (exit button): 5.08 mm too, so one screwdriver fits all. Two wires, no polarity.

### J4 — 1×14 female header, 2.54 mm
- Standard. Display plugs in perpendicular or via a 14-way ribbon.

### S1 / S2 — tactile 3 × 4 × 2 mm side-actuated SMD
- Any 2-pin SMD tact. Add 100 nF across each for debounce (standard on Espressif devkits).

### BZ1 — passive piezo element
- Capacitive load, few mA at 2–4 kHz. Drives straight from a GPIO through a 100 Ω series R
  to blunt the edge current. Loud enough for a door; not loud enough for a hallway.
  If you want loud, that's a magnetic buzzer + transistor + flyback diode = 3 more parts.

---

## Part-count delta vs COMPONENTS.md

| Added | Why |
|---|---|
| C4 1 µF on EN | Espressif requirement |
| C5–C8 10 µF ×4 | RECOM in/out caps for U2, U3 |
| C9, C10 100 nF ×2 | button debounce |
| R5 100 Ω | buzzer series |

23 → 31 parts. All passives, all 0603/0805. Still one-fifth of the original board.

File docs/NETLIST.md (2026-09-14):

# NETLIST.md — plain-words wiring table, palm-scan Rev 2

Read this before opening the schematic. If the schematic and this table disagree, one of them is wrong.
Net names are exactly what appears on the schematic labels.

## Power rails

| Net | Comes from | Feeds |
|---|---|---|
| `VIN_12V` | J1 pin 1 (+) or J8 centre pin | F1 only |
| `VIN_FUSED` | F1 pin 2 | D1 anode only |
| `+12V` | D1 cathode | C1, U2 in, U3 in, C5, C7, **J3 pin 1 + D2 cathode (lock)** — everything is behind the fuse and D1 |
| `+5V` | U3 out | C8, C12, CN1 pin 4 (sensor VCC) — **sensor only** |
| `+3V3` | U2 out | C2, C3, C6, U1 pin 2 (3V3), R1, R6, R7, J6 pin 1, **J4 pins 1 + 8 (display VCC + backlight)** |
| `VBUS` | J2 VBUS (A4 A9 B4 B9) | D3 pin 5, R11 (VBUS-present divider). Never powers anything. |
| `USB_DET` | R11/R12 divider | IO7 — 3.0 V when a USB host is plugged in |
| `GND` | J1 pin 2 (−) | everything |

## GPIO map (ESP32-S3-WROOM-1, module pin in brackets)

| GPIO | Net | Direction | Why this pin |
|---|---|---|---|
| EN [3] | `EN` | in | R1 10k → +3V3, C4 1µF → GND, S1 → GND |
| IO0 [27] | `BOOT` | in | strapping: S2 → GND, C10 100nF → GND. Internal pull-up. |
| IO4 [4] | `LOCK_EN` | out | R13 100Ω → `LOCK_G` → Q1 gate; R2 10k pulls `LOCK_G` low. Not a strapping pin, high-Z at reset. |
| IO7 [7] | `USB_DET` | in | VBUS ÷ (100k/150k) = 3.0 V when a USB host is present |
| IO5 [5] | `BUZZER` | out | R5 100Ω → BZ1 |
| IO6 [6] | `EXIT_BTN` | in | R6 10k → +3V3, C11 100nF → GND, R8 1k → `EXIT_SW` → J5 → GND |
| IO8 [12] | `TOUCH_IRQ` | in | optional, XPT2046 pen-down |
| IO9 [17] | `TOUCH_CS` | out | |
| IO10 [18] | `TFT_CS` | out | FSPICS0 (IOMUX, fastest) |
| IO11 [19] | `SPI_MOSI` | out | FSPID |
| IO12 [20] | `SPI_SCK` | out | FSPICLK |
| IO13 [21] | `SPI_MISO` | in | FSPIQ |
| IO14 [22] | `TFT_DC` | out | |
| IO17 [10] | `SEN_RX` | out | U1TXD → sensor's RX (CN1 pin 2, yellow) |
| IO18 [11] | `SEN_TX` | in | U1RXD ← sensor's TX (CN1 pin 3, green) |
| IO19 [13] | `USB_D-` | bidir | native USB |
| IO20 [14] | `USB_D+` | bidir | native USB |
| IO21 [23] | `TFT_RST` | out | |
| IO1 [39] | `LED_OK` | out | R9 150Ω → J7 pin 2 → panel green LED: palm recognised |
| IO2 [38] | `LED_DENY` | out | R10 150Ω → J7 pin 3 → panel red LED: not a member |
| IO43 [37] | `TXD0` | out | J6 debug header pin 2 |
| IO44 [36] | `RXD0` | in | J6 debug header pin 3 |
| IO3, IO45, IO46 | — | — | **strapping — left unconnected on purpose** |
| everything else | — | — | unconnected (no-connect flags in schematic) |

## Component-by-component

| Ref | Value | Footprint | Pin → Net |
|---|---|---|---|
| U1 | ESP32-S3-WROOM-1-N8R2 | RF_Module:ESP32-S3-WROOM-1 | 1 GND, 2 +3V3, 3 EN, 4 LOCK_EN, 5 BUZZER, 6 EXIT_BTN, 7 USB_DET, 10 SEN_RX, 11 SEN_TX, 12 TOUCH_IRQ, 13 USB_D-, 14 USB_D+, 17 TOUCH_CS, 18 TFT_CS, 19 SPI_MOSI, 20 SPI_SCK, 21 SPI_MISO, 22 TFT_DC, 23 TFT_RST, 27 BOOT, 36 RXD0, 37 TXD0, 38 LED_DENY, 39 LED_OK, 40 GND, 41 GND |
| U2 | R-78E3.3-1.0 | Converter_DCDC_RECOM_R-78E-0.5_THT | 1 +12V, 2 GND, 3 +3V3 |
| U3 | R-78E5.0-1.0 | Converter_DCDC_RECOM_R-78E-0.5_THT | 1 +12V, 2 GND, 3 +5V |
| F1 | Bourns MF-MSMF200/16 (2 A hold, 16 V) | Fuse_1812_4532Metric | 1 VIN_12V, 2 VIN_FUSED — **not** the MSMF110 (1.1 A), it would trip on every unlock |
| C1 | 470µF 25V | CP_Radial_D8.0mm_P3.50mm | + +12V, − GND |
| C2 | 100µF 10V | CP_Elec_6.3x5.4 (SMD electrolytic or polymer) | +3V3, GND — 100 µF MLCC does not exist in 0805 |
| C3 | 100nF | C_0603 | +3V3, GND — within 5 mm of U1 pin 2 |
| C4 | 1µF | C_0603 | EN, GND |
| C5 | 10µF 50V X7R | C_1210 | +12V, GND — at U2 pin 1. 50 V 10 µF MLCC needs 1210 and still loses ~40 % at 12 V bias |
| C6 | 10µF | C_0805 | +3V3, GND — at U2 pin 3 |
| C7 | 10µF 50V X7R | C_1210 | +12V, GND — at U3 pin 1 |
| C8 | 10µF | C_0805 | +5V, GND — at U3 pin 3 |
| C10 | 100nF | C_0603 | BOOT, GND — across S2 |
| C11 | 100nF | C_0603 | EXIT_BTN, GND — across J5 |
| R1 | 10k | R_0603 | +3V3, EN |
| R2 | 10k | R_0603 | LOCK_G, GND — gate pulldown, **safety** |
| R13 | 100Ω | R_0603 | LOCK_EN, LOCK_G — gate series, damps the switching edge |
| R11 | 100k | R_0603 | VBUS, USB_DET |
| R12 | 150k | R_0603 | USB_DET, GND |
| R3 | 5.1k | R_0603 | CC1, GND |
| R4 | 5.1k | R_0603 | CC2, GND |
| R5 | 220Ω | R_0603 | BUZZER, BZ_DRV — limits piezo edge current to ~15 mA |
| R6 | 10k | R_0603 | +3V3, EXIT_BTN |
| R7 | 1k | R_0603 | +3V3, LED_A |
| R8 | 1k | R_0603 | EXIT_SW, EXIT_BTN — series, protects IO6 from the wall wire |
| R9 | 150Ω | R_0603 | LED_OK, LED_OK_A — ~8 mA into a 5 mm green LED |
| R10 | 150Ω | R_0603 | LED_DENY, LED_DENY_A |
| J7 | PANEL LEDS 1x3 | PinHeader_1x03_P2.54mm_Vertical | 1 GND, 2 LED_OK_A, 3 LED_DENY_A — 5 mm LEDs on wires in the case; long leg (anode) to pin 2/3, short leg to pin 1 |
| C12 | 100µF 10V | CP_Elec_6.3x5.4 | +5V, GND — right at CN1, feeds the sensor's start-up spike |
| Q1 | AO3400A | SOT-23 | 1 G LOCK_G, 2 S GND, 3 D LOCK_SW |
| D1 | SS34 (SMA) | D_SMA | A VIN_FUSED, K +12V |
| D2 | SS54 (SMA) | D_SMA | A LOCK_SW, K +12V — flyback across lock, **safety** |
| D7 | SMAJ15A TVS | D_SMA | +12V, GND — clamps line transients at ~24 V, below Q1's 30 V |
| D4 | YELLOW LED 0603 | LED_0603_1608Metric | K GND, A LED_A — 3.3 V power indicator |

| D3 | USBLC6-2SC6 | SOT-23-6 | 1 USB_D-, 2 GND, 3 USB_D+, 4 USB_D+, 5 VBUS, 6 USB_D- |
| S1 | RESET | SW_Push_1P1T_NO_CK_KMR2 | EN, GND |
| S2 | BOOT | SW_Push_1P1T_NO_CK_KMR2 | BOOT, GND |
| J1 | 12V IN | MKDS-1,5-2-5.08 | 1 VIN_12V, 2 GND |
| J8 | DC JACK 5.5×2.1 | BarrelJack_Horizontal | 1 VIN_12V, 2 GND — pin 1 is the centre (+), pin 2 the sleeve; in parallel with J1, use either |
| J2 | USB-C | USB_C_Receptacle_HRO_TYPE-C-31-M-12 | VBUS×4 VBUS, GND×4+shell GND, D+ ×2 USB_D+, D− ×2 USB_D-, CC1 CC1, CC2 CC2, SBU NC |
| J3 | LOCK | MKDS-1,5-2-5.08 | 1 +12V, 2 LOCK_SW |
| J4 | DISPLAY 1x14 | PinSocket_1x14_P2.54mm_Vertical | 1 +3V3, 2 GND, 3 TFT_CS, 4 TFT_RST, 5 TFT_DC, 6 SPI_MOSI, 7 SPI_SCK, 8 +3V3, 9 NC, 10 SPI_SCK, 11 TOUCH_CS, 12 SPI_MOSI, 13 SPI_MISO, 14 TOUCH_IRQ |
| J5 | EXIT BTN | MKDS-1,5-2-5.08 | 1 EXIT_SW, 2 GND |
| J6 | DEBUG 1x4 | PinHeader_1x04_P2.54mm_Vertical | 1 +3V3, 2 TXD0, 3 RXD0, 4 GND — optional, recovery path if USB boot breaks |
| CN1 | AI10 sensor | Molex_PicoBlade_53047-0410 | 1 GND, 2 SEN_RX, 3 SEN_TX, 4 +5V |
| BZ1 | piezo | Buzzer_12x9.5RM7.6 | 1 BZ_DRV, 2 GND |

Total: 46 on-board parts + 2 panel LEDs.
Rev 2.4 (after Flux review): display moved to 3.3 V (no 5 V logic near the MCU; 5 V rail now feeds the sensor only); C2 → SMD electrolytic; C5/C7 → 1210; +R13 gate series; +D7 TVS on +12V; +R11/R12 VBUS-present divider on IO7.
Rev 2.3: Rev 2.3: status LEDs moved off-board to J7 (5 mm LEDs on wires), R9/R10 150Ω, +C12 100µF at the sensor, F1 = MF-MSMF200/16.
Rev 2.2: +green "recognised" on IO1, +red "denied" on IO2; D4 power LED now yellow.
Rev 2.1 notes: Rev 2.1 (after DESIGN_REVIEW.md): +F1 fuse, +D4/R7 power LED, +R8 exit-button series R, −C9 (redundant);
lock and D2 moved behind D1; sensor moved to 5 V; display SDO left unconnected.

## How the lock circuit works (low-side switch)

```
  +12V  ──┬───────────── J3.1 (lock +)      (after F1 and D1)
          │
        D2 (K)                      lock coil
          │                            │
        D2 (A) ───── LOCK_SW ──────── J3.2 (lock −)
                          │
                       Q1 drain
   IO4 ── LOCK_EN ──R13 100Ω── LOCK_G ── Q1 gate
                                  │        Q1 source ── GND
                                 R2 10k
              │
             GND
```

- Q1 sits on the *ground side* of the lock ("low-side switch"). The gate only needs 3.3 V above
  ground, which the ESP32 gives directly. A high-side switch would need a gate 12 V above ground → extra parts.
- R2 holds the gate at 0 V while the ESP32 is still booting (GPIOs are high-impedance for ~50 ms at reset).
  Without it the gate floats, picks up noise, and the lock can chatter or open at every power-up.
- D2 is reverse-biased in normal operation. When Q1 switches off, the coil's collapsing field tries to
  keep current flowing; D2 gives it a path back into the coil instead of forcing Q1's drain to hundreds of volts.
- The lock is fed from `+12V`, *after* F1 and D1. Rev 2.0 had it before D1 to keep inrush off C1 —
  that put Q1's body diode and D2 straight across a reversed adapter. D1 is rated 3 A; the lock's
  2 A inrush through it is fine, and C1 actually helps supply it.

## What is deliberately NOT here
- No relay, no optocoupler — MOSFET + shared ground does it.
- Nothing on the unprotected side of D1 except the fuse. Reverse the adapter and nothing conducts.
- No USB power path — see DATASHEETS.md §5.
- No pull-ups on IO45/IO46/IO3 — floating is the correct default for strapping pins we don't use.

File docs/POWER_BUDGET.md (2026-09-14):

# POWER_BUDGET.md — palm-scan Rev 2.4

> **Rev 2.4 (2026-09-14, after Flux review):** display moved from +5V to **+3V3** → 3.3 V rail typ 250 mA / peak 620 mA of 1000 (38 % margin at peak);
> 5 V rail now sensor-only, typ 330 / worst 530 mA. D7 SMAJ15A TVS on +12V. C2 is now an SMD electrolytic (100 µF MLCC in 0805 does not exist);
> C5/C7 moved to 1210 (10 µF 50 V MLCC needs it; ~6 µF effective at 12 V bias, RECOM says input caps are optional anyway).
> R13 100 Ω gate series: adds 6 nC × … negligible; Q1 still fully on. R11/R12 VBUS divider draws 20 µA from the host.

> **Update 2026-09-13 (later):** solenoid confirmed from Robu listing — 12 V, **0.8 A**, 9.6 W, **intermittent duty**, 2.45 N (cabinet lock).
> Display confirmed 3.3–5 V input (on-board LDO). F1 specified as Bourns **MF-MSMF200/16** (the MSMF110 = 1.1 A hold is wrong).
> C12 100 µF added at CN1 for sensor inrush. Status LEDs moved to panel header J7, 150 Ω → ~8 mA each.
> Remaining UNKNOWN: sensor start-up inrush (mitigated by C12), display current (estimate), LED Vf (buy 5 mm red/green, ~2 V).

Every number is tagged with where it came from:
- **[DS]** = datasheet in `datasheets/` (or the DFRobot wiki for the sensor)
- **[CALC]** = calculated from [DS] numbers, formula shown
- **[EST]** = engineering estimate; the part has no datasheet number for this
- **UNKNOWN** = no source. Tells you which spec is needed.

Ambient assumed 25–45 °C (indoor wall, Bengaluru). Adapter assumed regulated switch-mode, 12 V ±5 %.

---

## 0. The picture

```
ADAPTER 12 V ──J1──F1(polyfuse)──D1(SS34)──┬── +12V ──┬── U2 R-78E3.3-1.0 ── +3V3 ── ESP32, LEDs, buzzer, pull-ups
                                           │          ├── U3 R-78E5.0-1.0 ── +5V  ── display, AI10 sensor
                                           │          └── J3 ── SOLENOID ── Q1 ── GND     (D2 flyback across solenoid)
                                           └── C1 470 µF
USB-C ── data only. VBUS goes nowhere.
```

---

## 1. Rail summary

| Rail | Source | Normal load | Worst steady | Peak (ms) | Source limit | Margin at worst |
|---|---|---|---|---|---|---|
| **+3V3** | U2, 1.0 A | 150 mA [CALC] | 200 mA | **520 mA** (Wi-Fi TX burst) | 1000 mA [DS] | 48 % at peak ✅ |
| **+5V** | U3, 1.0 A | 430 mA [CALC/EST] | **630 mA** | UNKNOWN (sensor inrush) | 1000 mA [DS] | 37 % steady ✅, inrush ⚠️ |
| **+12V** (electronics) | D1 | 250 mA [CALC] | 460 mA | — | 3 A [DS] | ✅ |
| **+12V** (incl. solenoid, ≤5 s) | D1 | 1.05 A [CALC] | **1.5 A** | 1.5 A | 3 A [DS] | 50 % ✅ |
| **VIN_12V** (through F1) | adapter | 1.05 A | 1.5 A | 1.5 A | 2 A hold [EST] | 25 % ⚠️ see §3 |

---

## 2. Recommended power supply

| | Value | Why |
|---|---|---|
| Voltage | **12 V DC, regulated** | Solenoid is 12 V. U2 needs ≥ 7 V, U3 needs ≥ 8 V [DS] — so 9 V adapters are **out**. |
| Current | **2 A** (1.5 A minimum) | Worst steady 1.5 A, for 5 s. 2 A covers it. (3 A was first recommended so the 4 A-trip polyfuse could act before the adapter — but a 2 A SMPS adapter simply protects itself on a short, which is fine; F1 then guards against an oversized adapter.) A reused router / LED-strip adapter labelled 12 V ≥ 1.5 A works. |
| Wattage | 24 W | 12 V × 2 A. Actual draw: **3 W idle, ~13 W while unlocking** [CALC]. |
| Connector | 5.5 × 2.1 mm barrel → screw terminal J1 | Label the polarity on the enclosure. D1 saves the board if it's wrong, but nothing will work. |
| Tolerance | ±5 % → 11.4–12.6 V | After F1 (−0.1 V) and D1 (−0.5 V): **+12V rail = 10.8–12.0 V.** Solenoid sees this. Check its minimum pull-in voltage — UNKNOWN. |

### Battery backup, if you want it (not on this schematic)
- **3S Li-ion / LiFePO₄** (9.0–12.6 V) or **12 V SLA 7 Ah**. Both stay above U3's 8 V minimum. [DS]
- Drain at idle: ~0.25 A at 12 V = **6 Ah per day** [CALC]. A 7 Ah SLA gives ~1 day; a 3S 5 Ah pack ~20 h.
- Needs its own charger + protection board + a diode-OR with the adapter — that's another 6–8 parts, a separate design.
- Note the lock is fail-secure: with no battery, power cut = door locked, opened by the inside handle. The battery only buys palm access during an outage.

---

## 3. Component-by-component

Columns: V in = voltage the part actually sees · I norm = typical · I peak = worst/inrush · Rating = datasheet maximum · P = dissipation · Verdict.

### Protection and input

| Part | V in | I norm | I peak | Rating | P | Verdict |
|---|---|---|---|---|---|---|
| **J1** screw terminal MKDS 1,5 | 12.6 V | 1.05 A | 1.5 A | ~8 A / 160 V [EST — Phoenix MKDS 1,5 family; confirm exact part] | 0 | ✅ |
| **F1** polyfuse 2 A hold | 12.6 V | 1.05 A | 1.5 A (≤ 5 s) | UNKNOWN — **no part chosen yet** | ~0.1 W [EST, 0.05 Ω] | ⚠️ see below |
| **D1** SS34 | 12.5 V reverse max | 1.05 A | 1.5 A (5 s) / C1 charging spike ≪ 100 A IFSM | 3 A avg, 100 A surge, 40 V [DS] | 0.5 V × 1.05 = **0.53 W** during unlock, ~0.13 W idle [CALC] | ✅ RθJL 17 °C/W [DS] → +9 °C. Needs the copper pour called out in DESIGN_REVIEW.md |
| **C1** 470 µF 25 V | 12.0 V | ripple from lock steps | plug-in surge, limited by adapter | 25 V → 48 % derating [CALC] | negligible | ✅ Buy **105 °C low-ESR** |

**F1 — what to buy and the trap.** Spec: **1812 SMD polyfuse, 2.0 A hold, 4.0 A trip, ≥ 16 V** (e.g. Littelfuse 1812L200/16, Bourns MF-MSMF200/16). Two things the number "2 A" hides:
1. Hold current derates with temperature: ~1.6 A at 50 °C [EST, typical PTC curve]. Worst load 1.5 A only lasts 5 s, so no nuisance trips — **but measure your solenoid**. If it's over 0.9 A, go to 2.5 A hold.
2. Trip needs **4 A**. A 2 A adapter cannot supply 4 A — it sags or hiccups first, and F1 never trips. That's why §2 says 3 A adapter. With a 3 A adapter, a hard short pulls 3 A+, F1 heats and trips in tens of seconds; the adapter's own limit covers the first seconds. Acceptable.

### Regulators

| Part | V in | I out norm | I out peak | Rating | P | Verdict |
|---|---|---|---|---|---|---|
| **U2** R-78E3.3-1.0 | 10.8–12.0 V (needs 7–28) [DS] | 150 mA | 520 mA (Wi-Fi TX) | 1.0 A [DS] | P_out 0.5 W ÷ 0.85 eff [EST at 15 % load] → **0.09 W** loss; at peak 1.7 W ÷ 0.88 → 0.23 W | ✅ 48 % margin. Output cap 110 µF ≤ 220 µF limit [DS] |
| **U3** R-78E5.0-1.0 | 10.8–12.0 V (needs 8–28) [DS] | 430 mA | 630 mA steady, inrush UNKNOWN | 1.0 A, SCP continuous auto-recovery [DS] | 3.15 W ÷ 0.90 [DS 93 % full load] → **0.35 W** loss | ✅ steady. ⚠️ sensor inrush — see AI10 |
| U2 input current at 12 V | — | 50 mA | 165 mA | — | — | [CALC: P_in ÷ 12 V] |
| U3 input current at 12 V | — | 200 mA | 290 mA | — | — | [CALC] |

Both are switching regulators — 570 kHz [DS]. No heatsink, no derating needed under 60 °C ambient [DS].

### Brain

| Part | V in | I norm | I peak | Rating | P | Verdict |
|---|---|---|---|---|---|---|
| **U1** ESP32-S3-WROOM-1-N8R2 | 3.3 V (3.0–3.6 OK, 3.6 abs max) [DS] | 90 mA [DS: 240 MHz dual core, 66–92 mA] + ~15 mA PSRAM [EST] + Wi-Fi RX 95 mA [DS] → **~130 mA** typical when connected | **355 mA** RF TX burst (802.11b @ 20.5 dBm) [DS] on top of CPU → design to **500 mA** [DS Table 6-2 says supply ≥ 0.5 A] | Supply must deliver ≥ 500 mA [DS] | 3.3 V × 0.13 = 0.43 W avg, spread over the module | ✅ U2 gives 1 A |
| Light-sleep (if firmware uses it) | | 240 µA [DS] | | | | not needed for a wall-powered lock |
| GPIO source per pin | | | | 40 mA IOH / 28 mA IOL [DS] | | LEDs 4 mA, buzzer 15 mA peak ✅ |

### Lock driver

| Part | V | I norm | I peak | Rating | P | Verdict |
|---|---|---|---|---|---|---|
| **Solenoid** (J3) | 10.8–12.0 V | **UNKNOWN** — spec says "under 1 A". Used 0.8 A below. | ~1.2× holding for the first 100 ms (cold coil) [EST]. **No 2 A "gulp"** — a DC solenoid's current ramps up L/R to V/R; it doesn't overshoot like a motor. COMPONENTS.md overstated it. | UNKNOWN — duty cycle rating (intermittent vs continuous) | 12 V × 0.8 A = **9.6 W in the coil** while energised | ⚠️ **Measure coil resistance: I = 12 V ÷ R.** Get the datasheet or listing: holding current, duty, min pull-in voltage, inductance. |
| **Q1** AO3400A | VDS 12.6 V max (12 V + D2's 0.55 V clamp) | 0.8 A | 1.0 A | 30 V, 5.7 A cont, 30 A pulsed, VGS ±12 V [DS] | 0.8² × 40 mΩ [DS, interpolated 2.5–4.5 V curve] = **26 mW** | ✅ +3 °C [DS RθJA 125 °C/W]. Gate 3.3 V vs VGS(th) max 1.45 V [DS] — fully on. |
| Q1 body diode (reverse-adapter case) | | 0 | 0 — D1 now blocks | 2 A [DS] | 0 | ✅ Rev 2.0 would have put 12 V across this. Fixed. |
| **D2** SS54 flyback | 12 V reverse | 0 (only conducts at turn-off) | 0.8–1 A decaying, ~ms | 40 V, 5 A, 150 A surge [secondary source — components101/Newark, **not** a manufacturer PDF] | ½·L·I² per unlock; L UNKNOWN (typ 10–50 mH → 3–25 mJ) — shared with coil resistance, diode gets a fraction of a mJ | ✅ 5× margin either way |
| **R2** 10 kΩ pull-down | 3.3 V | 0.33 mA | — | 0.1 W (0603) | 1 mW | ✅ |
| **J3** screw terminal | 12 V | 0.8 A | 1 A | ~8 A [EST] | 0 | ✅ |

### 5 V loads

| Part | V in | I norm | I peak | Rating | P | Verdict |
|---|---|---|---|---|---|---|
| **AI10 sensor** (CN1) | 5.0 V (spec 5–12 V) [DS wiki] | 320–330 mA **@ 8 V** [DS wiki]. At 5 V: if internal reg is linear → same 330 mA; if switching → 330 × 8/5 = **530 mA**. Used 530 (worst). | **UNKNOWN.** Cameras + AI SoCs commonly spike 1–2 A for a few ms at power-on. | UNKNOWN | ~2.6 W inside the sensor (wiki: "chip heating is normal") | ⚠️ **Need: DFRobot AI10 inrush / startup current, or measure with a scope + 0.1 Ω shunt.** Mitigation already possible: add **C12 100 µF on +5V at CN1** to feed the spike (U3's SCP would otherwise hiccup on a > 1 A spike). |
| Standby (auto-detect off) | | 120–130 mA @ 8 V [DS wiki] → ~200 mA at 5 V worst | | | | |
| **CN1** PicoBlade 53047 | 5 V | 530 mA | inrush UNKNOWN | 1.0 A per contact [EST — Molex PicoBlade family; confirm 53047-0410 sheet] | 0 | ✅ steady, ⚠️ inrush |
| **Display** SmartElex 2.4" ST7789 + XPT2046 (J4) | 5.0 V into on-board LDO [DS manual: VCC = 5 V] | **UNKNOWN in the manual.** [EST]: backlight 60–80 mA + ST7789 10 mA + XPT2046 1 mA + LDO 5 mA → **~100 mA** | ~120 mA (backlight cold) [EST] | UNKNOWN | 0.5 W, mostly backlight LEDs | ⚠️ Need: **module current spec, and confirm the on-board LDO exists**. Measure with a USB power meter — 2 minutes. |
| J4 pin 1 (VCC) + pin 8 (LED) | | ~20 mA / ~80 mA | | 3 A per pin (2.54 mm socket) [EST] | | ✅ |

### 3.3 V loads (besides ESP32)

| Part | V | I | Peak | Rating | P | Verdict |
|---|---|---|---|---|---|---|
| **D4** yellow power LED + R7 1 kΩ | 3.3 V | (3.3 − 2.0) ÷ 1k = **1.3 mA** [CALC, Vf UNKNOWN until part chosen — AlGaInP yellow ≈ 2.0 V] | — | 20 mA typ LED | 2.6 mW | ✅ dim but visible indoors |
| **D5** green + R9 330 Ω (IO1) | 3.3 V | (3.3 − 2.1) ÷ 330 = **3.6 mA** — **only if AlGaInP "yellow-green" (Vf ≈ 2.1 V)**. A true-green InGaN LED has Vf ≈ 3.0 V → 0.9 mA, nearly invisible. | — | 40 mA IOH [DS] | 5 mW | ⚠️ Vf UNKNOWN — buy Vf ≤ 2.2 V, or drop R9 to 100 Ω for InGaN |
| **D6** red + R10 330 Ω (IO2) | 3.3 V | (3.3 − 1.8) ÷ 330 = **4.5 mA** [CALC] | — | 40 mA IOH | 8 mW | ✅ |
| **BZ1** passive piezo + R5 220 Ω (IO5) | 3.3 V square wave, 2–4 kHz | avg ≈ 2·C·V·f = 2 × 20 nF × 3.3 × 4 kHz = **0.5 mA** [CALC, C UNKNOWN — typ 10–30 nF] | 3.3 ÷ 220 = **15 mA** at each edge, ns | 40 mA IOH [DS] | ~2 mW in R5 | ✅ **Only if it is a piezo.** Magnetic buzzer (16–42 Ω coil) → 100+ mA → GPIO damage. |
| R1, R6 pull-ups 10 kΩ | 3.3 V | 0.33 mA each, only while pressed | | | | ✅ |
| **J6** debug header | 3.3 V pin | 0 normally; a USB-UART dongle may *draw* ~10 mA if it's powered from J6 pin 1 | | | | ✅ don't power the board from J6 |

### USB

| Part | V | I | Rating | Verdict |
|---|---|---|---|---|
| **J2** USB-C 16-pin | VBUS 5 V present but **unused** | 0 A | 3 A VBUS [EST, HRO TYPE-C-31-M-12 family] | ✅ |
| **R3/R4** 5.1 kΩ CC | ≤ 5 V | source's Rp is 80–330 µA → 0.4–1.7 V on CC | 0.1 W | ✅ tells the host "sink, 5 V, ≤ 500 mA". We draw 0. |
| **D3** USBLC6-2SC6 | 5 V VBUS ref, 3.3 V data | ~µA leakage | 5.25 V working, ±15 kV ESD [from memory — **ST datasheet not fetched**, download timed out] | ✅ but mark as unverified |
| **U1** USB PHY | powered from 3.3 V internally | included in ESP32 figure | | ✅ |

---

## 4. Loss ledger (where the watts go, during an unlock)

| Where | W | Source |
|---|---|---|
| Solenoid coil | 9.6 | 12 V × 0.8 A [CALC] |
| AI10 sensor | 2.6 | 5 V × 0.53 A worst |
| Display | 0.5 | [EST] |
| ESP32 + LEDs + buzzer | 0.5 | 3.3 V × 0.15 A |
| D1 | 0.53 | 0.5 V × 1.05 A |
| U3 loss | 0.35 | 7 % of 3.15 W |
| U2 loss | 0.09 | |
| F1 | 0.1 | I²R, 0.05 Ω [EST] |
| Q1 | 0.03 | |
| **Total from adapter** | **~14 W → 1.2 A at 12 V** | vs 36 W available ✅ |
| Idle (door locked, sensor watching) | **~3 W → 0.25 A** | |

Nothing on the board dissipates more than 0.6 W. Nothing needs a heatsink. The two warm spots are **D1** (0.5 W, 5 s bursts) and **U3** (0.35 W continuous) — both handled by copper pours.

---

## 5. PCB traces and copper (2-layer, 1 oz / 35 µm)

IPC-2221 outer-layer rule of thumb, 10 °C rise [CALC]:

| Net | Current | Minimum width | **Use** |
|---|---|---|---|
| VIN_12V, VIN_FUSED, +12V trunk, J3, LOCK_SW, Q1 source → GND | 1.5 A | 0.7 mm | **1.5 mm**, or a pour |
| +12V to U2/U3 | 0.3 A | 0.2 mm | 0.6 mm |
| +5V trunk to CN1 | 0.63 A (+ inrush) | 0.35 mm | **1.0 mm** |
| +3V3 trunk | 0.52 A pk | 0.3 mm | 0.8 mm |
| GND | all of the above | — | **full bottom-layer pour**, stitched vias every 5 mm near Q1/D1/U2/U3 |
| Signals, LEDs, buzzer | ≤ 15 mA | 0.15 mm | 0.25 mm |
| USB D+/D− | — | — | 0.25 mm, **same length ±1 mm, 90 Ω diff** — or just keep them < 20 mm and parallel; USB 2.0 full-speed forgives a lot |

Vias: 0.3 mm drill / 0.6 mm pad carries ~1 A each. Lock path needs **≥ 2 vias** wherever it changes layer.

---

## 6. What could still burn or fail — ranked

| # | Risk | Likelihood | Consequence | Fix / what's needed |
|---|---|---|---|---|
| 1 | **Sensor inrush > 1 A trips U3's short-circuit protection → sensor reboots in a loop** | medium (unknown) | sensor never comes up, or comes up flaky | **UNKNOWN spec: AI10 startup current.** Measure it. Add C12 100 µF on +5V at CN1 regardless — ₹3. |
| 2 | **Solenoid is continuous-duty rated? min voltage?** | unknown | coil burns if firmware holds it; or won't pull in at 10.8 V | **UNKNOWN spec: solenoid datasheet** (R_coil, duty, pull-in V). Firmware 5 s cap + task watchdog. |
| 3 | 2 A adapter + 2 A polyfuse = fuse never trips on a short | certain | adapter hiccups/shuts down on its own — nothing burns. F1 still catches a wrong (oversized) adapter. | accepted; 2 A adapter is fine |
| 4 | Green LED is InGaN (Vf 3 V) → invisible | common ordering mistake | "green LED doesn't work" | buy Vf ≤ 2.2 V, or R9 = 100 Ω |
| 5 | Buzzer is magnetic, not piezo | common ordering mistake | IO5 damaged | listing must say **piezo, passive** |
| 6 | Display has no on-board LDO on this exact variant | low | 5 V into a 3.3 V controller → dead display | look for the SOT-223 regulator next to the header before power-up |
| 7 | D1 on a thin trace with no pour | layout error | D1 runs ~40 °C hot; survives, degrades | follow §5 |
| 8 | Cheap "12 V" adapter actually 13.5 V unloaded | common | everything still within ratings (C1 25 V, regs 28 V, Q1 30 V) | ✅ design tolerates it |
| 9 | ESP32 Wi-Fi burst while lock fires | normal operation | 0.52 A on 3.3 V + 1 A on 12 V simultaneously | ✅ separate regulators; U2 doesn't see the lock at all |

---

## 7. UNKNOWN list — get these before ordering

| Spec | Why it matters | Where to get it |
|---|---|---|
| **Solenoid**: coil resistance, holding current, duty cycle, min pull-in voltage, inductance | sizes F1, confirms Q1/D1 margins, firmware timing | seller listing / measure with a multimeter (R) |
| **AI10 sensor**: startup inrush, internal regulator type, current at 5 V input | U3 stability, C12 sizing | DFRobot support, or scope + 0.1 Ω shunt |
| **Display module**: total current at 5 V, on-board LDO present | U3 budget, safety of 5 V VCC | USB power meter + look at the board |
| **F1**: exact part | voltage rating, hold/trip, derating | choose 1812L200/16 or MF-MSMF200/16 and read its sheet |
| **LED Vf** (D4, D5, D6) | brightness, resistor values | pick parts on LCSC, read Vf @ 5 mA |
| **Piezo capacitance** | buzzer current (only matters if > 50 nF) | seller listing; usually 10–30 nF |
| **D2 SS54** manufacturer PDF | I used distributor summaries | Vishay/Diodes Inc SS54 PDF — any 40 V 3 A+ Schottky also works |
| **D3 USBLC6-2SC6** manufacturer PDF | pinout verified against the KiCad symbol, not the sheet | st.com (fetch timed out) |
| **CN1, J1/J3/J5, J2** exact current ratings | I used family-typical numbers | Molex 53047, Phoenix MKDS 1,5, HRO TYPE-C-31-M-12 sheets |
| **Adapter** regulation and unloaded voltage | +12V rail range | measure yours — 30 seconds with a multimeter |

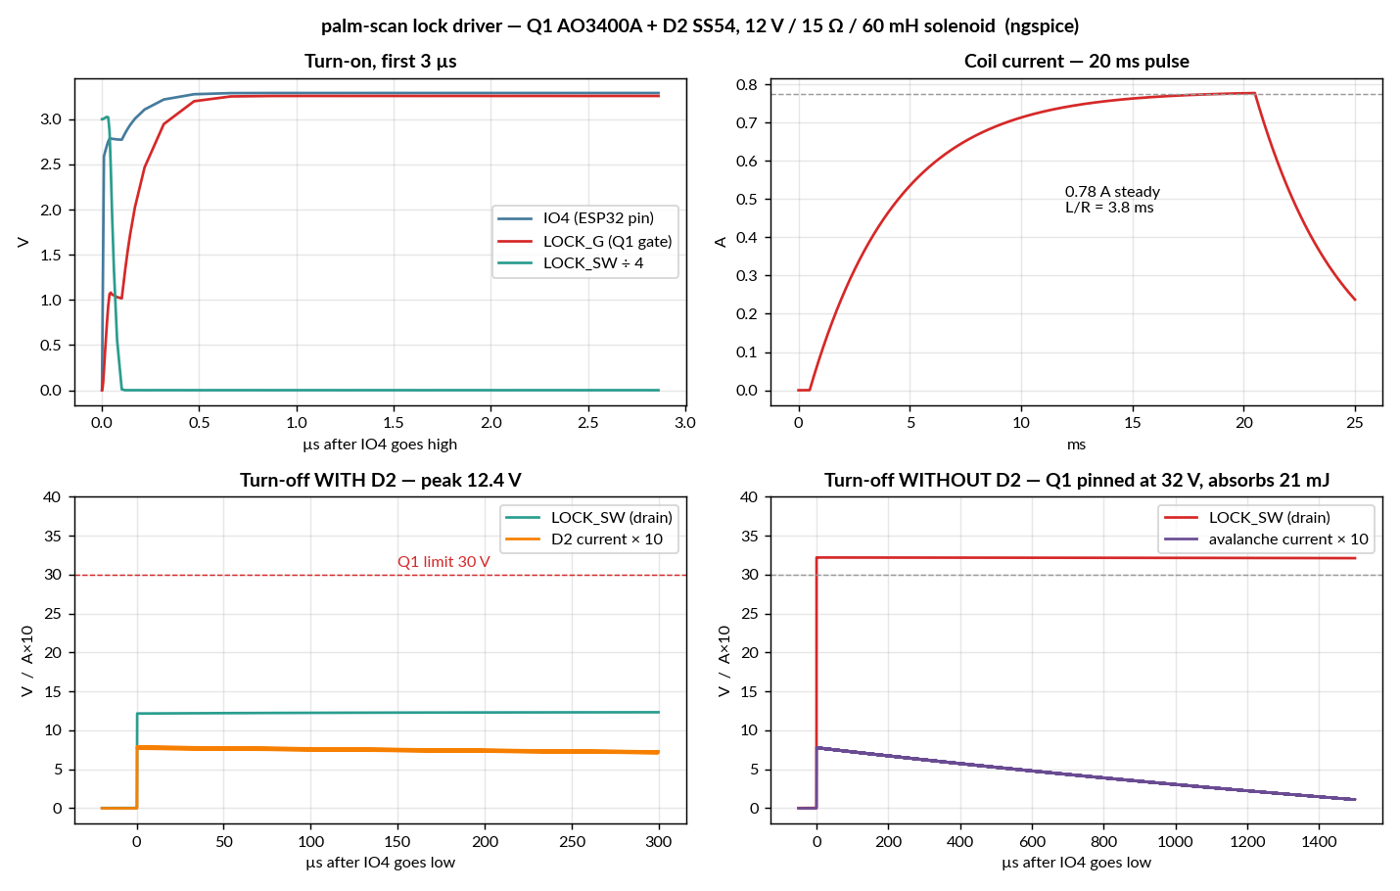
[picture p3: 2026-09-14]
hardware/sim/lock_driver.png

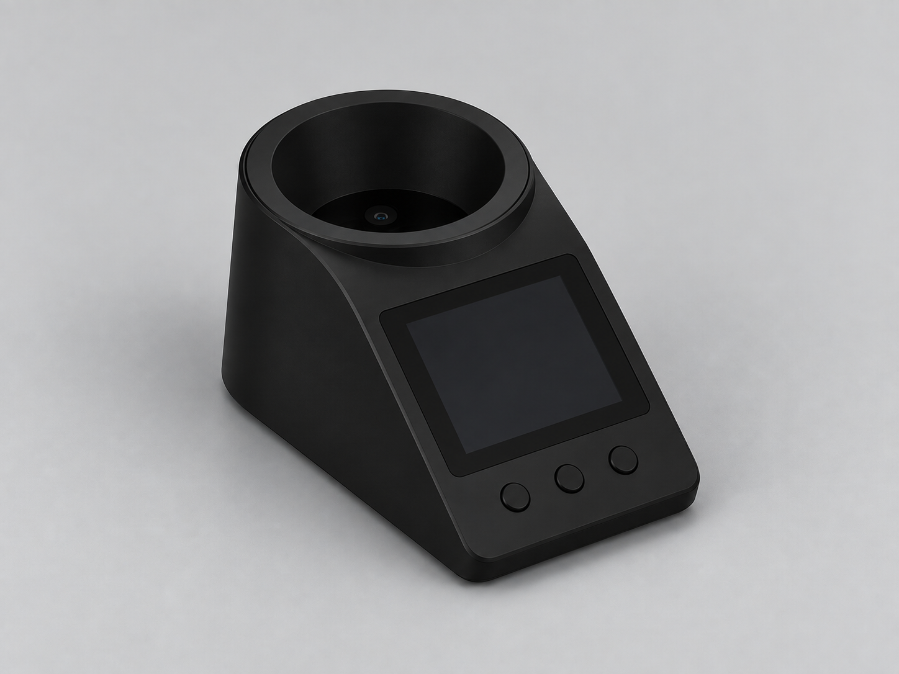
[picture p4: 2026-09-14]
docs/images/enclosure-render.png

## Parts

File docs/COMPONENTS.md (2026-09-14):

# Components — palm-scan Rev 2.4

**What we're building:** a box next to your door. You show your hand, the door opens.

This is the buying list. Wiring is in `NETLIST.md`, currents in `POWER_BUDGET.md`, the schematic in `../hardware/kicad/palm-scan.pdf`.
The old Rev 2 list (23 parts, no fuse, lock before the diode) is gone — it had a real fault, see `DESIGN_REVIEW.md`.

**Three lists:**
- **A — PCB maker assembles.** Small surface-mount parts. JLCPCB solders them for you. You never touch these.
- **B — You solder.** Through-hole parts with big legs. 10 minutes with an iron. (JLCPCB *can* do these too for extra money — see the note at the end.)
- **C — You buy, lives outside the board.** Sensor, screen, lock, adapter, case.

LCSC numbers marked ✅ are ones I'm confident of. Others say *search* — type the part name into jlcpcb.com/parts and pick the one marked "Basic" if there is one (no extra fee).

---

## A — PCB maker assembles (32 parts on the board)

| Ref | What | Value / part | Package | Qty | LCSC | Plain words |
|---|---|---|---|---|---|---|
| U1 | ESP32-S3-WROOM-1-N8R2 | Espressif module | module | 1 | *search "ESP32-S3-WROOM-1-N8R2"* | **The brain.** Wi-Fi and USB built in. |
| Q1 | MOSFET | AO3400A | SOT-23 | 1 | C20917 ✅ | **The strong arm** that switches the lock. |
| D1 | Schottky diode | SS34, 40 V 3 A | SMA | 1 | C8678 ✅ | Blocks a backwards adapter. |
| D2 | Schottky diode | SS54, 40 V 5 A | SMA | 1 | *search "SS54 SMA"* | Absorbs the lock's kick-back. **Safety.** |
| D3 | USB ESD protector | USBLC6-2SC6 | SOT-23-6 | 1 | C7519 ✅ | Takes static shocks from the USB plug. |
| D7 | TVS diode | SMAJ15A | SMA | 1 | *search "SMAJ15A"* | Swallows voltage spikes on the 12 V line (long lock cable). |
| D4 | LED, yellow | 0603 | 0603 | 1 | *search "0603 LED yellow"* | Power-on light (for you, not users). |
| F1 | Resettable fuse | Bourns MF-MSMF200/16 — 2 A hold, 16 V | 1812 | 1 | *search "MF-MSMF200/16"* — **not** MSMF110 | Self-resetting fuse. |
| R1 | Resistor | 10 kΩ | 0603 | 1 | basic | Keeps the brain awake (EN pull-up). |
| R2 | Resistor | 10 kΩ | 0603 | 1 | basic | Holds the lock OFF during boot. **Safety.** |
| R3, R4 | Resistor | 5.1 kΩ | 0603 | 2 | basic | Tells the laptop "I'm a USB device". |
| R5 | Resistor | 220 Ω | 0603 | 1 | basic | Buzzer current limit. |
| R6 | Resistor | 10 kΩ | 0603 | 1 | basic | Exit-button pull-up. |
| R7 | Resistor | 1 kΩ | 0603 | 1 | basic | Power LED current limit. |
| R8 | Resistor | 1 kΩ | 0603 | 1 | basic | Protects the exit-button pin from the wall wire. |
| R9, R10 | Resistor | 150 Ω | 0603 | 2 | basic | Green/red LED current limit. |
| R11 | Resistor | 100 kΩ | 0603 | 1 | basic | USB-plugged-in detector (top). |
| R12 | Resistor | 150 kΩ | 0603 | 1 | basic | USB-plugged-in detector (bottom). |
| R13 | Resistor | 100 Ω | 0603 | 1 | basic | MOSFET gate resistor, softens the switching edge. |
| C2 | Capacitor, electrolytic/polymer | 100 µF 10 V | SMD 6.3 × 5.4 | 1 | *search "100uF 10V SMD electrolytic 6.3x5.4"* (same as C12) | 3.3 V tank for Wi-Fi bursts. |
| C3 | Capacitor | 100 nF | 0603 | 1 | basic | Noise filter at the brain's power pin. |
| C4 | Capacitor | 1 µF | 0603 | 1 | basic | Clean reset at power-up (Espressif requirement). |
| C5, C7 | Capacitor | 10 µF 50 V X7R | **1210** | 2 | *search "10uF 50V 1210 X7R"* | Regulator input caps. 50 V MLCC only exists this big. |
| C6, C8 | Capacitor | 10 µF 16 V | 0805 | 2 | basic | Regulator output caps. |
| C10, C11 | Capacitor | 100 nF | 0603 | 2 | basic | Button debounce. |
| C12 | Capacitor, electrolytic | 100 µF 10 V | SMD 6.3 × 5.4 | 1 | *search "100uF 10V SMD electrolytic 6.3x5.4"* | Feeds the sensor's start-up gulp. |
| S1, S2 | Tactile switch | C&K KMR2 type, side-push | 4.2 × 2.8 SMD | 2 | *search "KMR2"* | RESET and BOOT buttons. |
| J2 | USB-C socket | HRO TYPE-C-31-M-12, 16-pin | SMD | 1 | C165948 ✅ | Plug your laptop in here. |

**Count: 32.** All SMD. Estimated JLCPCB assembly cost for this: setup ~₹700 + parts ~₹600 for 5 boards (the ESP32 module is most of it). Rough numbers — check the quote.

---

## B — You solder (14 parts on the board)

All through-hole, big pins, beginner-friendly. Buy from Robu / LCSC / local.

| Ref | What | Value / part | Qty | Plain words |
|---|---|---|---|---|
| U2 | 3.3 V regulator | RECOM R-78E3.3-1.0 (3 pins) | 1 | 12 V → 3.3 V for the brain. Runs cold. |
| U3 | 5 V regulator | RECOM R-78E5.0-1.0 (3 pins) | 1 | 12 V → 5 V for the sensor only. **Must be the 1.0 A version.** Same body as the 0.5 A part. |
| C1 | Capacitor, electrolytic | 470 µF 25 V, low-ESR 105 °C, 8 mm dia | 1 | **The big water tank** on 12 V. Long leg = +. |
| J1 | Screw terminal | 2-pin, 5.08 mm pitch (KF301 / Phoenix MKDS 1,5) | 1 | 12 V in, bare wires. Alternative to J8. |
| J8 | DC barrel jack | 5.5 × 2.1 mm, through-hole (DC-005) | 1 | 12 V in, the adapter's plug goes straight in. Centre pin = +. |
| J3 | Screw terminal | 2-pin, 5.08 mm | 1 | Lock wires. |
| J5 | Screw terminal | 2-pin, 5.08 mm | 1 | Exit button wires. |
| J4 | Female header | 1 × 14, 2.54 mm | 1 | Screen plugs in. |
| J6 | Male header | 1 × 4, 2.54 mm | 1 | Debug / recovery UART. Optional. |
| J7 | Male header | 1 × 3, 2.54 mm | 1 | Green + red panel LEDs plug in. |
| CN1 | PicoBlade socket | Molex 53047-0410, 4-pin 1.25 mm, vertical | 1 | Sensor cable plugs in. **Check the pitch on your sensor's cable first.** |
| BZ1 | Buzzer | **Passive piezo**, 12 mm, 7.6 mm pin pitch | 1 | Beeps. Must say *passive* and *piezo*. |

**Count: 14** (U2, U3, C1, J1, J3, J4, J5, J6, J7, J8, CN1, BZ1).

Budget alternatives, if the RECOM parts (~₹250 each) hurt: any "78xx-compatible switching regulator module" with the same 3-pin SIP footprint — e.g. **K7803-1000R3** (3.3 V, 1 A) and **K7805-1000R3** (5 V, 1 A), ~₹80 each. Same pins: 1 = in, 2 = GND, 3 = out. Check the input range covers 12 V (they do, 6.5–36 V).

---

## C — You buy, off the board

| Item | What | Have it? | Plain words |
|---|---|---|---|
| Palm sensor | DFRobot AI10 (SEN0677) | ✅ yes | The eye. Comes with its cable. |
| Screen | SmartElex 2.4" TFT 240×320, ST7789/ILI9341, resistive touch, 14-pin | found on Robu | Shows messages, tap to enrol. Runs on 3.3 V from our board. |
| Solenoid lock | Robu "DC 12V Cabinet Door Lock", 0.8 A, intermittent | found on Robu | The bolt. Cabinet-strength — fine for the prototype. |
| Power adapter | 12 V 2 A, 5.5 mm plug, **centre-positive** | found on Robu | Feeds everything. Plugs into J8. Check the label shows ⊕ on the centre. |
| Panel LEDs | 5 mm LED, green ×1, red ×1 | — | Face-of-the-box lights. Wired to J7. |
| Exit button | Any push button (momentary, normally-open) | — | Open from inside. Wired to J5. |
| Wires | Hookup wire, 22 AWG; LED wires can be thinner | — | Adapter, lock, button, LEDs. |
| Enclosure | 3D printed | — | Holes for screen, sensor, 2 LEDs, cable. |
| Standoffs + screws | M3, ×4 each | — | Board sits on 4 corner holes. |
| Iron + solder | — | ✅ presumably | For list B. |
| Multimeter | any ₹300 one | — | Not optional. Checks the adapter, the coil, the rails. |

---

## Totals

| | Count |
|---|---|
| A — assembled by JLCPCB | 32 |
| B — you solder | 14 |
| **On the board** | **46** |
| C — off-board | 11 items |

Rev 2.4 added D7, R11, R12, R13 after the Flux review. Old Rev 2 had 23 on-board parts. The extra 18 are: fuse, 4 regulator caps, EN cap, 2 debounce caps, sensor cap, 3 LED resistors + 1 LED, exit-button resistor, 2 headers, and a 3rd screw terminal. Every one has a reason in `DESIGN_REVIEW.md` or `POWER_BUDGET.md`.

---

## Do not skip these three

- **R2** — stops the door opening by itself when power comes back.
- **D2** — stops the lock killing Q1.
- **F1** — stops a wiring mistake burning the board.

About ₹15 together.

---

## Notes on ordering from JLCPCB

- Order **5 boards** (their minimum). Assemble **2** — that's the minimum assembly quantity, and you get spares.
- Choose **2-layer, 1.6 mm, HASL** — cheapest, fine for this.
- When uploading, they'll ask for three files from KiCad: **Gerbers**, **BOM (CSV)**, **CPL (placement CSV)**. We'll generate these at the end of PCB layout — not yet.
- **THT assembly:** JLCPCB can also solder list B for roughly ₹300–500 extra, but they must stock each part, and RECOM/Molex often aren't. Hand-soldering B is the safer bet the first time.
- **Parts they don't stock** show as "shortfall" in the quote. Anything from list A that's short: move it to list B and buy it yourself. The only awkward one would be the ESP32 module (it's SMD with an exposed pad) — if JLC has no stock, wait for stock rather than hand-soldering it.

---

## Choices we made, and why (unchanged from Rev 2, still true)

| Choice | What we picked | Why |
|---|---|---|
| Mains on the board? | **No** — external 12 V adapter | 230 V next to 3.3 V logic on a hobby board is a shock and fire risk. |
| Relay or MOSFET? | **MOSFET** | Shared ground, no isolation needed. Silent, no contacts to wear. 1 part instead of 8. |
| Which brain? | **ESP32-S3** | USB built in — no USB-serial chip. |
| Sensor voltage? | **5 V** (was 12 V) | 12 V is the very top of its range; cheap adapters overshoot. |
| USB power? | **Data only** | The regulators need ≥ 7 V. Desk work = plug the adapter too. |
| Screen backlight dimming? | No | 4 extra parts for nothing. |
| Status lights? | **Screen + 2 panel LEDs** | LEDs are readable from across the room; the screen isn't. |

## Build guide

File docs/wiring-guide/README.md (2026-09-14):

# Wiring & Components Guide — source

Generates `docs/palm-scan-wiring-guide.pdf`: an illustrated, plain-language guide to every
connection and every part on the Rev 2.4 board, with an A3 fold-out wiring diagram.

| File | What |
|---|---|
| `parts.py` | SVG drawing primitives + component illustrations (adapter, sensor, screen, solenoid, connectors, …) |
| `master.py` | The A3 fold-out master wiring diagram |
| `cards.py` | Per-connection illustrations, power tree, scan timeline, part icons |
| `build.py` | Writes the HTML (CSS + prose + inline SVG) and prints it to PDF, two passes for page numbers |

```bash
python3 build.py        # → ../palm-scan-wiring-guide.pdf
```

Needs Python 3.10+, poppler-utils (`pdfinfo`, `pdftotext`) and a Chromium binary — it looks in
`~/.cache/ms-playwright/chromium-*/` by default; set `CHROME=/path/to/chrome` otherwise.
Fonts used if installed: Lato (headings, diagrams), P052 (body), Ubuntu Mono (pin names).

Pin numbers, net names and part values come from `docs/NETLIST.md`; if the schematic changes,
update the tables in `cards.py` / `build.py` and rebuild. Board component *positions* in the
fold-out are illustrative until the PCB layout exists.

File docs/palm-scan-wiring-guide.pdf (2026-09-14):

P A L M - V E I N R E C O G N I T I O N · H A R D W A R E D O C U M E N TAT I O N

# palm-scan

# Wiring & Components Guide — every connection, explained for everyone

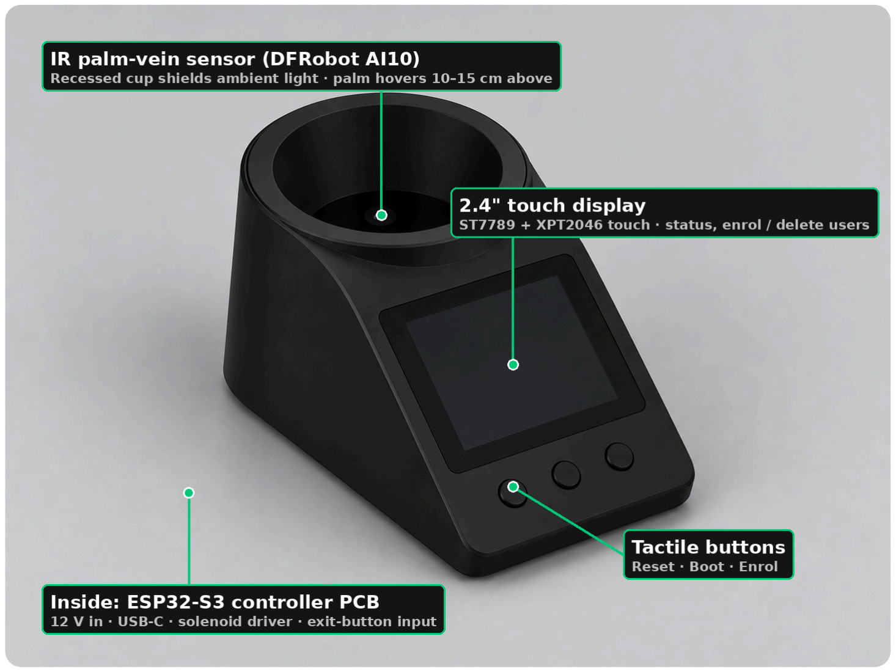
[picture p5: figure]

APPLIES TO
Controller board Rev 2.4 (schematic verified 14 Sep 2026)
DFRobot AI10 palm-vein sensor · 2.4″ TFT touch display
- 12 V solenoid

MAKERS
Ashmita K Rao · Adithya Satish · Vinod Kumar github.com/coolvnod/palm-scan

palm-scan · Wiring & Components Guide | Rev 2.4

# Contents

1 How to read this guide | 3
2 The system at a glance | 5
3 The complete wiring diagram (A3 fold-out) | 6
4 Connection by connection | 7
4.1 Power in — the wall adapter | 7
4.2 The palm-vein sensor | 8
4.3 The touch screen | 9
4.4 The solenoid bolt | 11
4.5 The exit button | 12
4.6 The front-panel lights | 13
4.7 USB-C — programming and logs | 14
4.8 The debug header (normally empty) | 15
5 Inside the board — the parts and what they do | 16
6 Where the power goes | 18
7 What happens during a scan | 19
8 Before you power it on | 20
A Appendix — pin tables | 21
B Appendix — glossary | 23

Section 3 is an A3 fold-out. If you print on A4, print that page at “fit to page” — or read it on a screen, where you can zoom.

# 1 How to read this guide

## This guide shows every wire and every part of the palm-scan controller, and says what each one is for — in ordinary words first, and in engineering terms for those who want

them.

You do not need to know electronics. Three things are enough: a wire carries either power or information; power has a + side and a − side; and every connector has numbered pins. Everything else is explained where it comes up.

The guide has three layers, marked like this:

IN PLAIN WORDS
Ordinary-language explanation. If you only read these, you can still wire the unit correctly.

FOR THE ENGINEER
Precise engineering detail — part numbers, voltages, currents, and the reasoning behind a choice. Skip freely.

BEFORE YOU CONNECT IT
Something to check or avoid before plugging in. These are the paragraphs that save hardware.

## Wire colours used in the drawings

Colours in this guide follow what you will actually see: the sensor cable comes with its wires already coloured by the maker, and the rest follow the usual convention of red for +, black for −.

Colour | Meaning | Where you will see it
red | 12 V power, the positive (+) side | adapter → board, board → lock
orange | 5 V power | regulator → sensor (inside the board)
yellow-gold | 3.3 V power | board → screen, debug header
black | ground — the shared return path, the “−” side | every cable has one
yellow | data: the board talking to the sensor | sensor cable
green | data: the sensor talking to the board | sensor cable
white | a switched line — the board turns it on or off | lock, exit button
purple | USB | laptop cable
grey | a sheath with several wires inside | sensor cable

## Ten words

Word | What it means here
Voltage (V) | How hard electricity is being pushed — like water pressure. 12 V pushes harder than 3.3 V. Every part has a voltage it expects; too much breaks it.
Current (A) | How much electricity is flowing — like litres per minute. The adapter can supply 2 A; the board never needs more than about 1.2 A.
Ground (GND, −) | The common “zero level” every voltage is measured against, and the path electricity takes back. Every cable carries one ground wire.
Rail | A shared supply line at one voltage. The board has three: +12 V, +5 V and +3.3 V.
Signal | A wire that carries information instead of power. Tiny currents, but the timing matters.
Pin | One metal contact in a connector. Pins are numbered; pin 1 is usually marked with a square, a dot or an arrow.
Polarity | Which way round. Power and LEDs have a + and a −; a button and the solenoid don’t care.
UART | A two-wire conversation: one wire for each direction, at an agreed speed. The sensor talks to the board this way.
SPI | A faster, four-wire conversation with a shared clock — used for the screen.
GPIO | A pin on the brain that the software can switch on or off, or read. The lock, buzzer, LEDs and button all sit on GPIOs.

# 2 The system at a glance

One small board is the brain. Eight things connect to it. That is the whole system.

The board is built around an ESP32-S3 — a microcontroller with Wi-Fi, Bluetooth and a USB port on a thumbnail-sized module. It does not do the palm recognition itself: the AI10 sensor is a small computer of its own that photographs the palm in near-infrared light and answers the question “who is this?”. The board asks that question, reads the answer, and then does the ordinary things: lights, a beep, a message on the screen, and — if the answer is a known person — power to the bolt for a few seconds.

Everything that plugs into the board is listed below with the number used for it throughout this guide. The numbers appear on the fold-out diagram in Section 3 and as the sub-section numbers in Section 4.

What | What it does | Where it connects
1 Wall adapter | Supplies all the power: 12 V, up to 2 A. | J8 (round plug) or J1 (bare wires)

2 Palm-vein sensor The eye. Shines near-infrared light, photographs the veins,

| decides who it is. | CN1 — 4-wire cable, supplied with the sensor
3 Touch screen | Shows what is happening; used to add or remove people. | J4 — plugs straight onto the board,

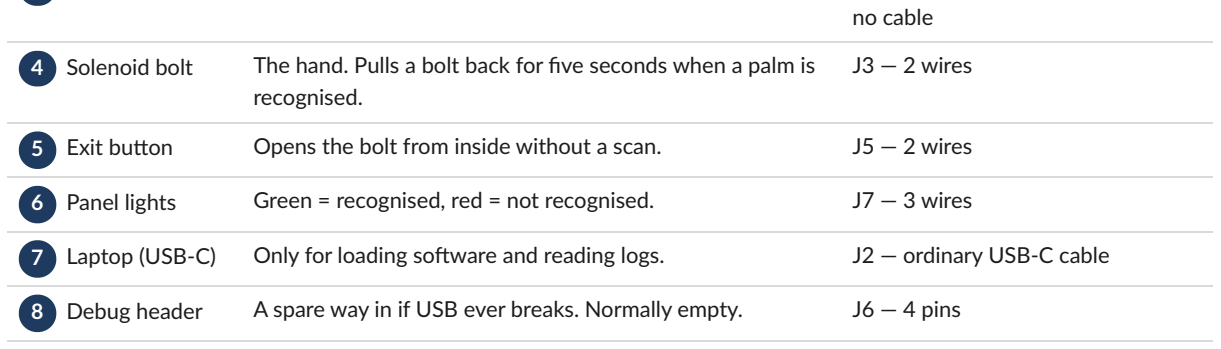
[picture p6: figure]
no cable; recognised.; J3 — 2 wires

4 Solenoid bolt | The hand. Pulls a bolt back for five seconds when a palm is
5 Exit button | Opens the bolt from inside without a scan. | J5 — 2 wires
6 Panel lights | Green = recognised, red = not recognised. | J7 — 3 wires
7 Laptop (USB-C) | Only for loading software and reading logs. | J2 — ordinary USB-C cable
8 Debug header | A spare way in if USB ever breaks. Normally empty. | J6 — 4 pins

Think of it as a small office: the brain (ESP32-S3) sits at the desk. The eye (sensor) reports who is at the door. The screen, lights and beeper talk to the person. The bolt is the only thing that moves. The adapter keeps the lights on. The USB port is the back door for the person who maintains it.

FOR THE ENGINEER
Recognition runs entirely inside the AI10 (DFRobot SEN0677): NIR illumination, binocular camera, on-module matching, template storage. The ESP32-S3 drives it over UART at 115 200 baud with a simple framed protocol ( EF AA · id · length · payload · XOR ). The board itself has 46 parts on 38 nets; its jobs are power conditioning (12 V in → 3.3 V and 5 V), a protected low-side MOSFET driver for the solenoid, an SPI display, USB for programming, and I/O for a button, two LEDs and a piezo. Full design record: docs/DESIGN_REVIEW.md .

# palm-scan

2

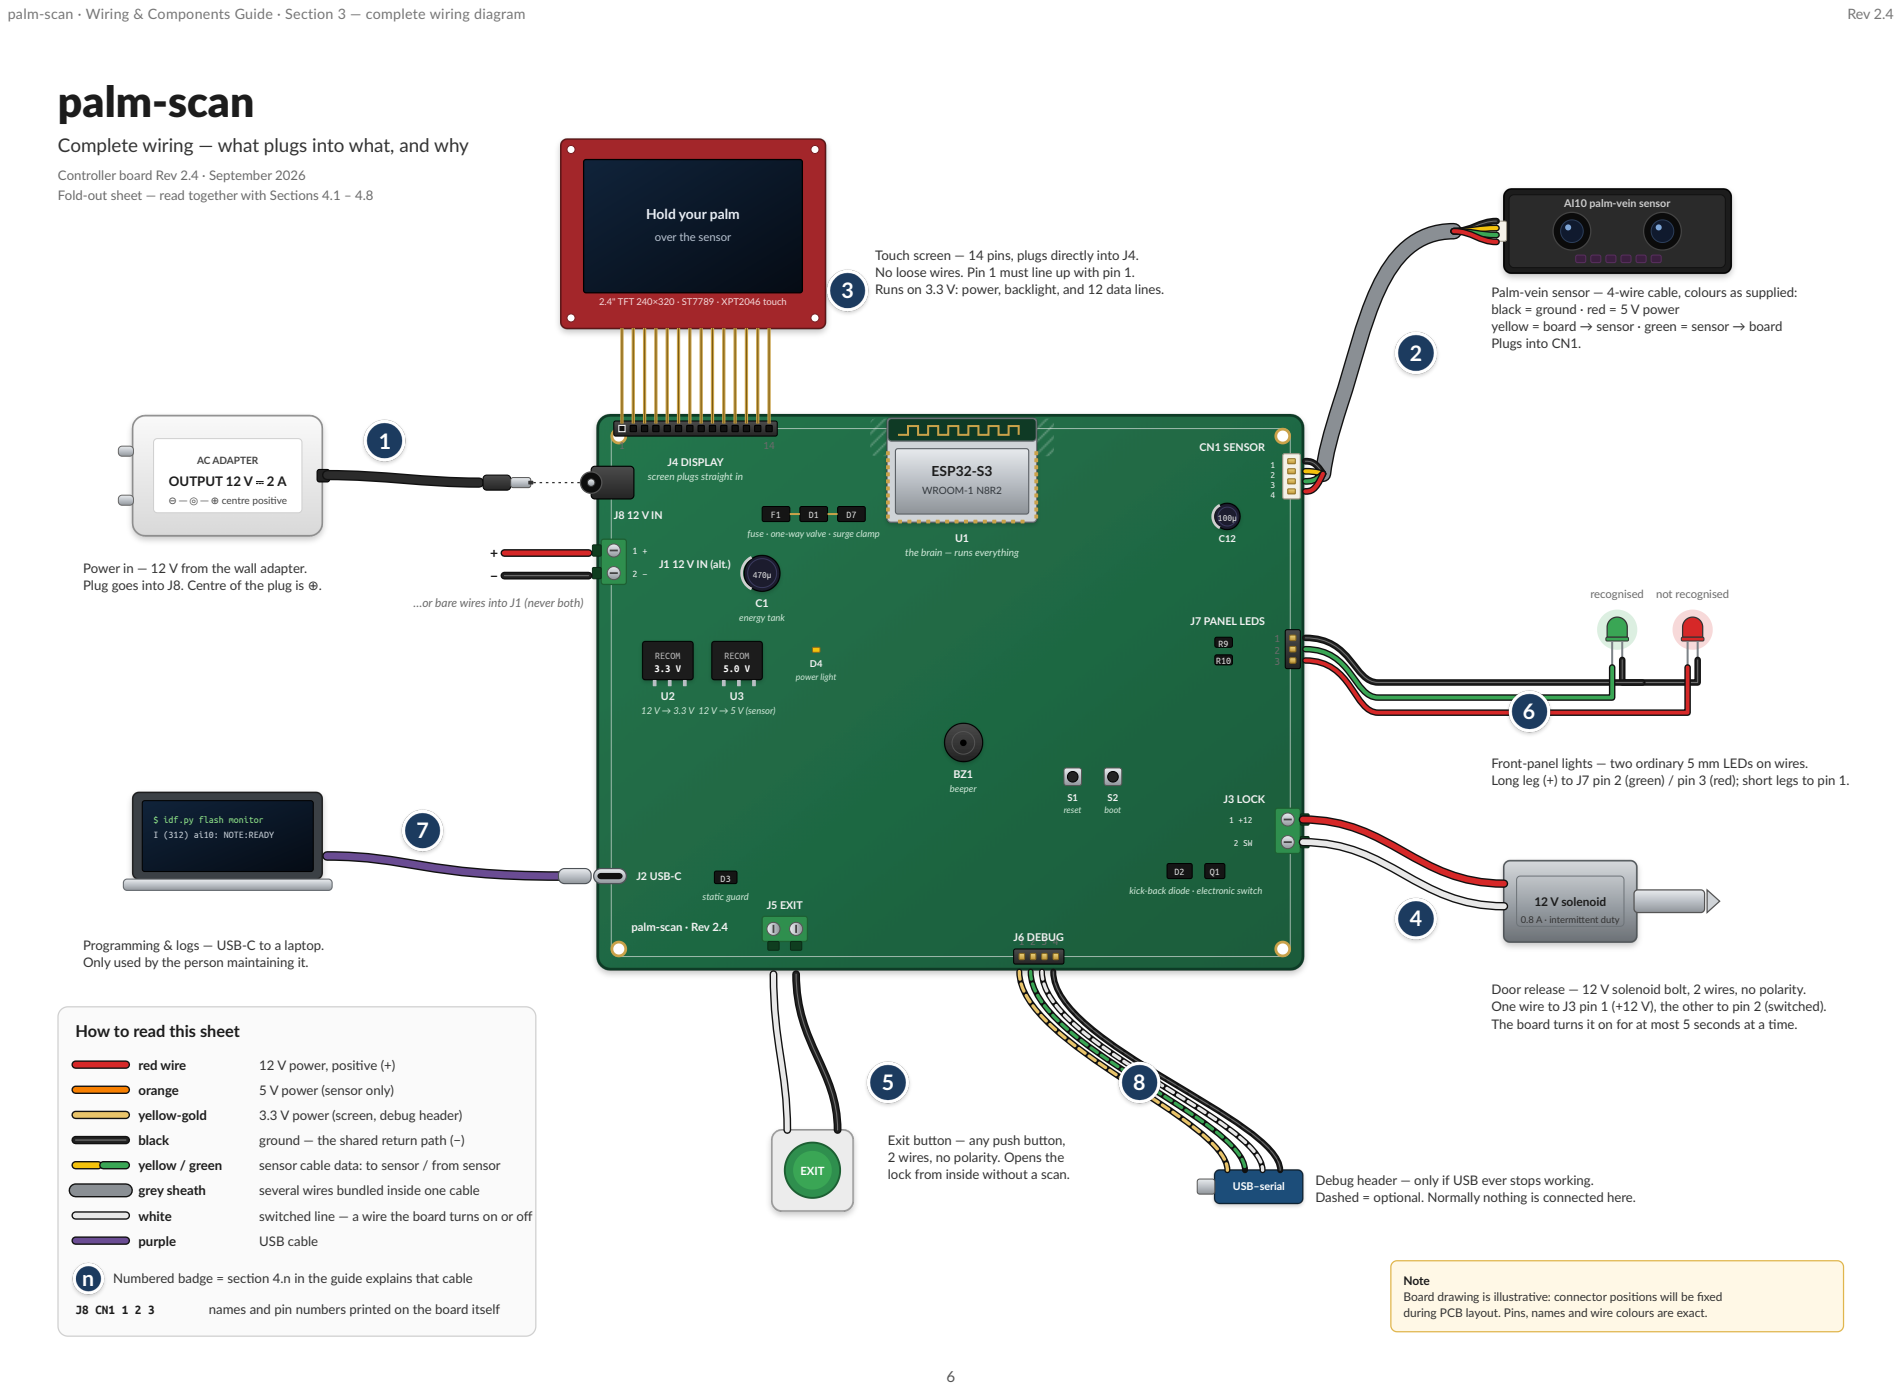
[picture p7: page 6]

Complete wiring — what plugs into what, and why

Controller board Rev 2.4 · September 2026
Fold-out sheet — read together with Sections 4.1 – 4.8

Touch screen — 14 pins, plugs directly into J4.
No loose wires. Pin 1 must line up with pin 1.
Runs on 3.3 V: power, backlight, and 12 data lines.

Palm-vein sensor — 4-wire cable, colours as supplied:
black = ground · red = 5 V power
yellow = board → sensor · green = sensor → board
Plugs into CN1.

J4 DISPLAY
screen plugs straight in

fuse · one-way valve · surge clamp

the brain — runs everything

Power in — 12 V from the wall adapter.
Plug goes into J8. Centre of the plug is ⊕.

…or bare wires into J1 (never both)

Front-panel lights — two ordinary 5 mm LEDs on wires.
Long leg (+) to J7 pin 2 (green) / pin 3 (red); short legs to pin 1.

$ idf.py flash monitor

kick-back diode · electronic switch

Programming & logs — USB-C to a laptop.
Only used by the person maintaining it.

Door release — 12 V solenoid bolt, 2 wires, no polarity.
One wire to J3 pin 1 (+12 V), the other to pin 2 (switched).
The board turns it on for at most 5 seconds at a time.

How to read this sheet

Exit button — any push button,
2 wires, no polarity. Opens the
lock from inside without a scan.

Debug header — only if USB ever stops working.
Dashed = optional. Normally nothing is connected here.

n Numbered badge = section 4.n in the guide explains that cable

Note
Board drawing is illustrative: connector positions will be fixed
during PCB layout. Pins, names and wire colours are exact.

# 4 Connection by connection

Each of the eight connections, one at a time: a drawing, the pin table, why it is wired that way, and what goes wrong if it isn’t. Net names ( this typeface ) are the schematic’s labels.

## 4.1 Power in — the wall adapter

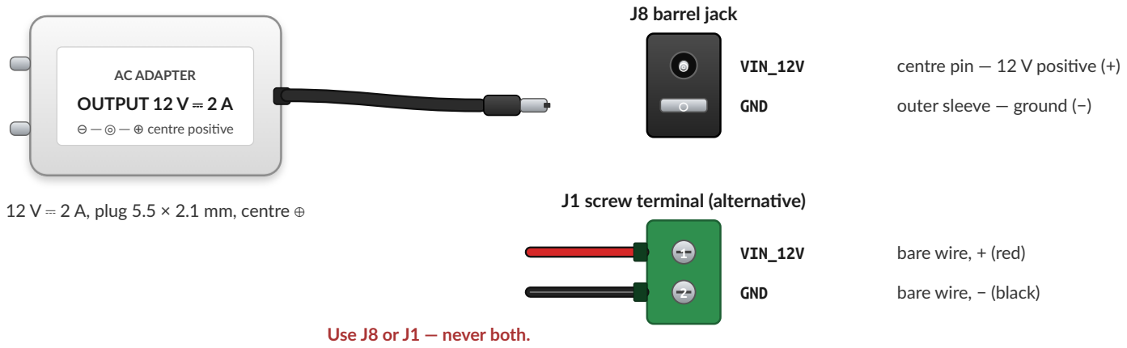
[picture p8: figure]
AC ADAPTER; OUTPUT 12 V ⎓ 2 A; ⊖ ─ ◎ ─ ⊕ centre positive; 12 V ⎓ 2 A, plug 5.5 × 2.1 mm, centre ⊕; J8 barrel jack; GND; outer sleeve — ground (−); J1 screw terminal (alternative); VIN_12V; bare wire, + (red); bare wire, − (black); Use J8 or J1 — never both.

◎ | VIN_12V | centre pin — 12 V positive (+)

Figure 4.1 — The adapter’s round plug goes into J8. The screw terminal J1 is an alternative for an adapter with bare wire ends, or a bench supply. They are wired in parallel on the board: use one or the other, never both.

Connector | Pin | Net | Plain words
J8 barrel jack | centre VIN_12V | 12 V, positive (+). The adapter must be centre-positive (⊕ symbol on its label).
J8 barrel jack | sleeve GND | ground (−)
J1 screw terminal | 1 | VIN_12V | 12 V, positive (+) — red wire

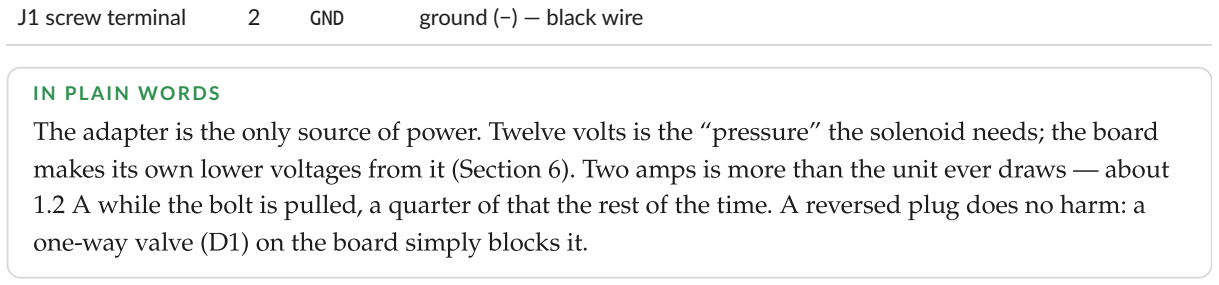
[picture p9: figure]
J1 screw terminal; GND; ground (−) — black wire; IN PLAIN WORDS

The adapter is the only source of power. Twelve volts is the “pressure” the solenoid needs; the board makes its own lower voltages from it (Section 6). Two amps is more than the unit ever draws — about 1.2 A while the bolt is pulled, a quarter of that the rest of the time. A reversed plug does no harm: a one-way valve (D1) on the board simply blocks it.

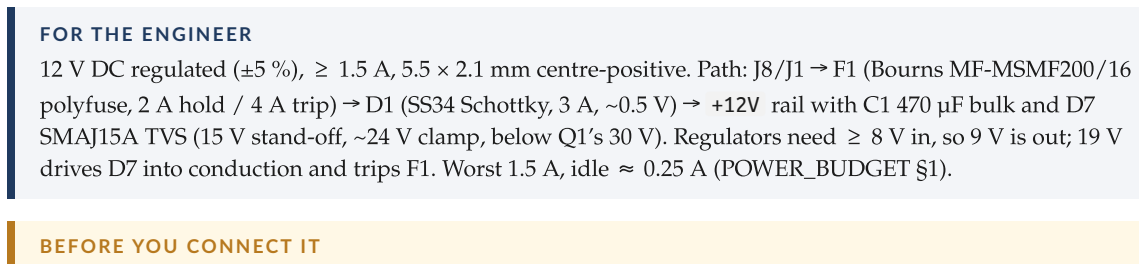
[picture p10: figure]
FOR THE ENGINEER; BEFORE YOU CONNECT IT

12 V DC regulated (±5 %), ≥ 1.5 A, 5.5 × 2.1 mm centre-positive. Path: J8/J1 → F1 (Bourns MF-MSMF200/16 polyfuse, 2 A hold / 4 A trip) → D1 (SS34 Schottky, 3 A, ~0.5 V) → +12V rail with C1 470 µF bulk and D7 SMAJ15A TVS (15 V stand-off, ~24 V clamp, below Q1’s 30 V). Regulators need ≥ 8 V in, so 9 V is out; 19 V drives D7 into conduction and trips F1. Worst 1.5 A, idle ≈ 0.25 A (POWER_BUDGET §1).

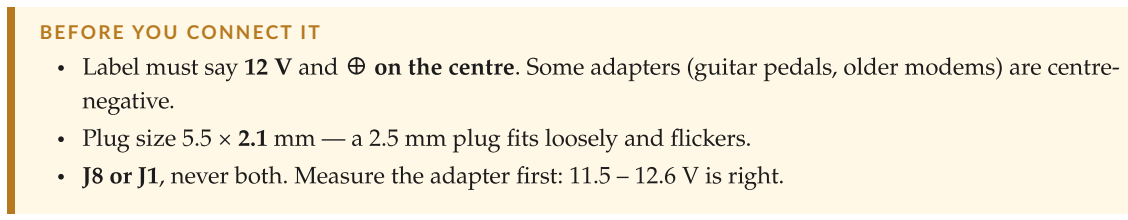
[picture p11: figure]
negative.

Label must say 12 V and ⊕ on the centre. Some adapters (guitar pedals, older modems) are centre-

Plug size 5.5 × 2.1 mm — a 2.5 mm plug fits loosely and flickers.
J8 or J1, never both. Measure the adapter first: 11.5 – 12.6 V is right.

## 4.2 The palm-vein sensor

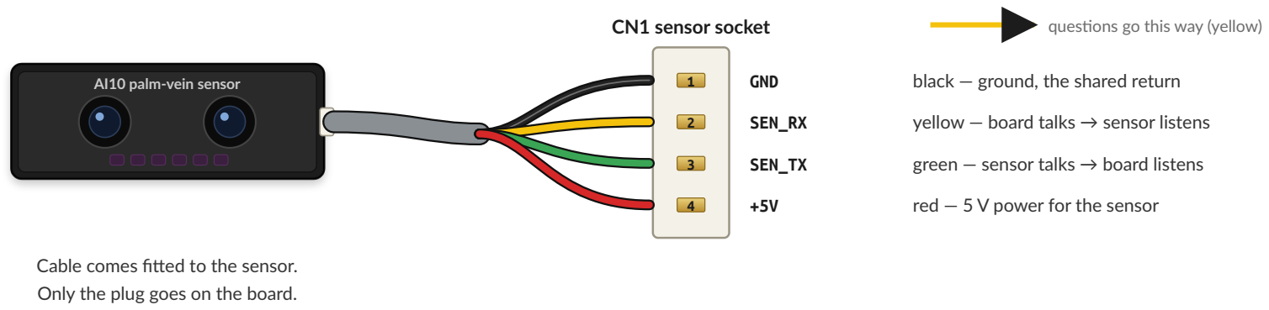
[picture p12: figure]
AI10 palm-vein sensor; CN1 sensor socket; GND; black — ground, the shared return; red — 5 V power for the sensor; questions go this way (yellow); Cable comes fitted to the sensor.; Only the plug goes on the board.

2 | SEN_RX | yellow — board talks → sensor listens
3 | SEN_TX | green — sensor talks → board listens

Figure 4.2 — The AI10 comes with its 4-wire cable already fitted. Only the small plug at the free end goes onto the board, into CN1. Yellow and green are the two directions of the conversation; red and black are power.

Pin

Wire
| colour | Net | Plain words
1 | black | GND | ground — the return path for both power and data

2
| yellow

SEN_RX the sensor’s listening wire: the board’s questions travel along it (“reset”, “who is this?”, “add
| | | this person”)
3 | green SEN_TX the sensor’s talking wire: its answers come back along it (“ready”, “user 3, score 92”, “nobody”)
4 | red | +5V | 5 V power for the sensor, made on the board

IN PLAIN WORDS
The sensor and the board talk the way two people talk on a phone: one wire carries each direction, and both must agree on a speed (here 115 200 “bits per second”, roughly eleven thousand letters a second). The maker names the wires from the sensor’s point of view — its RX (receive) wire is where the board’s messages arrive — so the yellow wire is SEN_RX even though it carries what the board sends. The cable does the crossing-over for you; you only plug it in.

FOR THE ENGINEER
UART1 on the ESP32-S3: IO17 (U1TXD) → CN1 pin 2, IO18 (U1RXD) ← CN1 pin 3. 115 200 8N1, fixed. The sensor is powered from the dedicated +5V rail (U3, R-78E5.0-1.0, 1 A) rather than 12 V: the AI10 accepts 5–12 V, but at 12 V its internal regulator runs hot. Measured draw 320–330 mA at 8 V; budgeted 530 mA worst case at 5 V. C12 (100 µF) sits right at CN1 to feed the unknown start-up spike. After power-up the module sends NOTE:READY ; firmware must wait for it before sending any command. Protocol reference: docs/datasheets/SEN0677_AI10_protocol_manual_V1.0.pdf .

BEFORE YOU CONNECT IT
The sensor’s data voltage is not documented. Before the plug ever touches the board: power the sensor on its own (red = 5 V, black = ground) and measure the green wire with a multimeter. Idle, it must read 3.3 V or less (never above 3.6 V). If it reads 5 V, stop — the board needs a small divider added on that wire.
Check the plug pitch: CN1 is a 1.25 mm PicoBlade socket. If the sensor’s plug is 1.5 mm or 2.0 mm, the socket on the board must be changed before ordering the PCB.
Pin 1 (black) is marked on the board. The plug only fits one way.

## 4.3 The touch screen

Hold your palm

over the sensor

2.4" TFT 240×320 · ST7789 · XPT2046 touch

J4 14-pin socket (screen’s pins go straight in)

1 | +3V3 | power for the screen
2 | GND | ground
3 | TFT_CS | “I’m talking to the screen”
4 | TFT_RST | reset the screen
5 | TFT_DC | command or picture data?
6 | SPI_MOSI | picture data → screen
7 | SPI_SCK | the clock (metronome)
8 | +3V3 | backlight power
9 | — | not connected (on purpose)
10 | SPI_SCK | the same clock, for touch
11 | TOUCH_CS | “I’m talking to the touch”
12 | SPI_MOSI | touch commands → touch chip
13 | SPI_MISO | touch position → board
14 | TOUCH_IRQ | “someone touched me”

Pin 1 on the screen must meet pin 1 on the board. The board’s pin 1 has a square pad.

Figure 4.3 — The screen module has a row of 14 pins that pushes straight into the socket J4 on the board’s top edge. Nothing to solder, no cable. Seven pins drive the picture; six drive the touch layer; pin 9 is deliberately left empty.

Pin | Screen label | Net | Plain words
1 | VCC | +3V3 | power for the screen
2 | GND | GND | ground
3 | CS | TFT_CS | “I’m talking to you, screen” — the board pulls this low to address the display
4 | RESET | TFT_RST | restarts the screen chip at power-up
5 | DC | TFT_DC | tells the screen whether the next byte is a command or picture data
6 | SDI (MOSI) | SPI_MOSI | picture data, board → screen
7 | SCK | SPI_SCK | the clock — a steady tick that keeps sender and receiver in step
8 | LED | +3V3 | backlight power
9 | SDO (MISO) | — | not connected, on purpose (see engineer’s note)
10 | T_CLK | SPI_SCK | the same clock, shared with the touch chip
11 | T_CS | TOUCH_CS | “I’m talking to you, touch chip”
12 | T_DIN | SPI_MOSI | commands, board → touch chip
13 | T_DO | SPI_MISO | the touch position, touch chip → board
14 | T_IRQ | TOUCH_IRQ | “someone is touching me” — lets the board react instantly

IN PLAIN WORDS
Where the sensor uses two wires, the screen uses a faster arrangement called SPI: a clock wire ticks, and on every tick one bit moves along the data wire. Two chips live on the screen module — one that draws pixels and one that senses your finger — and they share the clock and data wires like two people sharing one phone line. The two CS (“chip select”) wires are how the board says which of them it is addressing. Because the board only ever sends to the picture chip, that chip’s reply wire (pin 9) is left unconnected.

FOR THE ENGINEER
FSPI on IOMUX pins for full speed: IO12 SCK, IO11 MOSI, IO13 MISO, IO10 TFT_CS (FSPICS0), IO9
TOUCH_CS, IO14 DC, IO21 RST, IO8 TOUCH_IRQ. The whole module runs from +3V3 (VCC and LED) so no module output can exceed the ESP32’s 3.3 V I/O — Rev 2.4 moved it off 5 V for exactly that reason; the backlight is marginally dimmer. Pin 9 is unconnected because the ST7789’s SDO does not tri-state when CS is high on these red 2.4″ boards, so it would fight the XPT2046 on MISO — a well-known failure (touch reads garbage, or the display freezes after the first touch). The Robu listing says “ILI9341/ST7789”: firmware must probe and support both. TOUCH_IRQ is optional; polling works.

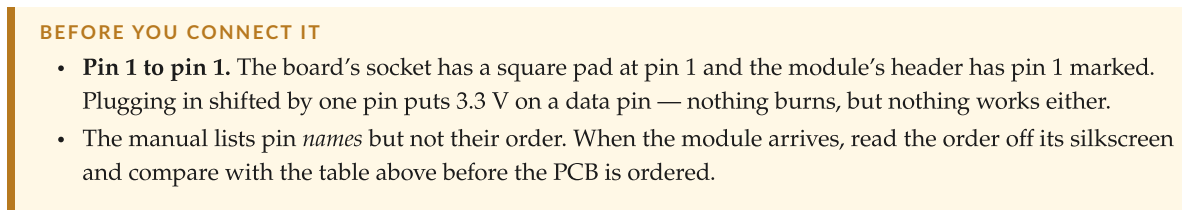
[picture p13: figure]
BEFORE YOU CONNECT IT

Pin 1 to pin 1. The board’s socket has a square pad at pin 1 and the module’s header has pin 1 marked. Plugging in shifted by one pin puts 3.3 V on a data pin — nothing burns, but nothing works either.
The manual lists pin names but not their order. When the module arrives, read the order off its silkscreen and compare with the table above before the PCB is ordered.

## 4.4 The solenoid bolt

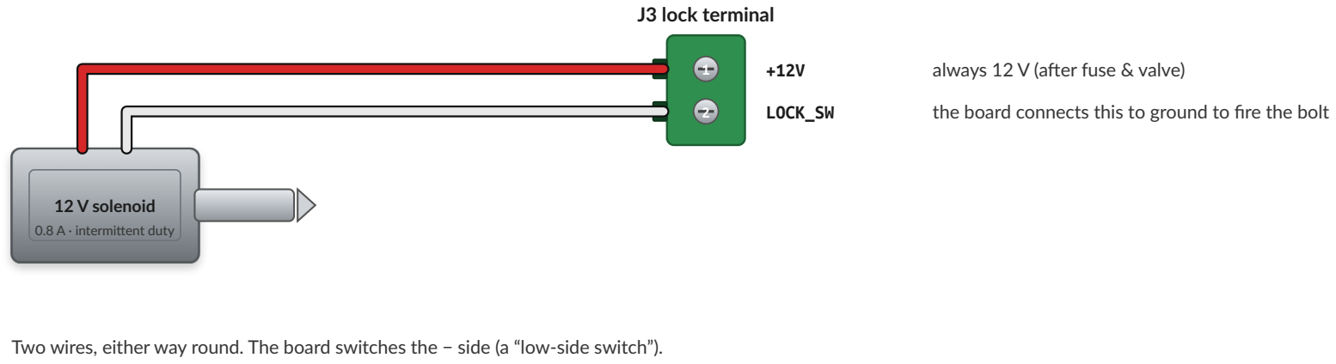
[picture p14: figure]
12 V solenoid; 0.8 A · intermittent duty; J3 lock terminal; always 12 V (after fuse & valve)

2 | LOCK_SW | the board connects this to ground to fire the bolt

Two wires, either way round. The board switches the − side (a “low-side switch”).

Figure 4.4 — Two wires from the solenoid into the screw terminal J3. There is no right or wrong way round for the solenoid itself: it is a coil, and the board switches its − side.

Pin | Net | Plain words
1 | +12V | always at 12 V — one end of the coil sits here permanently
2 | LOCK_SW | the switched end. The board connects it to ground for up to 5 s; current flows; the bolt pulls back

IN PLAIN WORDS
A solenoid is an electromagnet with a spring-loaded bolt inside. Give it 12 V and the magnet pulls the bolt in; take the power away and the spring pushes it out. The board does the “give it 12 V” with an electronic switch (a MOSFET, Q1) on the ground side of the coil, so the wiring is just two wires and a screw terminal. The board also makes sure the bolt is never held in for more than five seconds at a time — these cabinet solenoids overheat if left on.

FOR THE ENGINEER
Low-side switch: Q1 AO3400A (30 V, 5.7 A, RDS(on) ≈ 40 mΩ) gated from IO4 via R13 100 Ω, with R2 10 kΩ gate-to-source holding it off while the ESP32 boots (GPIOs float for ~50 ms at reset). D2 SS54 across the coil catches the inductive kick when Q1 opens. The coil is fed from +12V after F1 and D1 — Rev 2.0 fed it before D1, which put Q1’s body diode straight across a reversed adapter. Rated load: Robu 12 V cabinet lock, ~0.8 A, intermittent duty (max 10 s on). Firmware: hard 5 s cap per release plus the ESP-IDF task watchdog. Fail-secure: loss of power = bolt out = locked.

BEFORE YOU CONNECT IT
Buy a solenoid marked 12 V. Measure its current once with the multimeter: if it is above 0.8 A, tell whoever orders the PCB — the fuse must move up one size.
If this bolt ever secures a real door, the door must open from inside with a handle regardless of the electronics. That is a fire-safety rule, not a preference.
Keep this cable away from the exit-button cable and the sensor cable — the coil’s switching can upset them.

## 4.5 The exit button

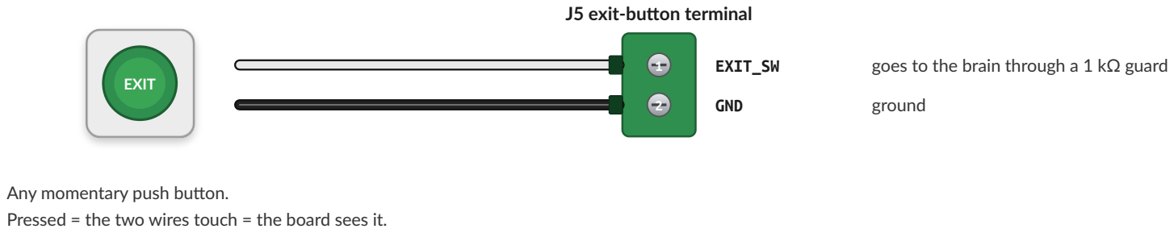
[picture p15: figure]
EXIT; J5 exit-button terminal; GND; ground; Any momentary push button.

1 | EXIT_SW | goes to the brain through a 1 kΩ guard

Pressed = the two wires touch = the board sees it.

Figure 4.5 — Any ordinary push button, two wires, into J5. Either way round.

Pin | Net | Plain words
1 | EXIT_SW | the sensing wire — normally held at 3.3 V by the board
2 | GND | ground

IN PLAIN WORDS
A button is the simplest input there is: two wires that touch when you press. The board keeps the sensing wire gently pulled up to 3.3 V; pressing the button connects it to ground, the voltage drops to zero, and the software sees “pressed”. Real buttons bounce — the contacts chatter for a few thousandths of a second — so the board smooths the wire with a small capacitor and the software double-checks before acting.

FOR THE ENGINEER
IO6 with R6 10 kΩ pull-up to +3V3 , C11 100 nF to ground (RC ≈ 1 ms debounce), and R8 1 kΩ in series between IO6 and the terminal to limit current from static or induced transients on a long wall wire; the ESP32’s internal clamp diodes do the rest. Normally-open momentary switch. Cable length is not critical (tens of metres is fine); route it away from the solenoid cable. On press the firmware runs the same 5 s release sequence as a recognised palm, without touching the sensor.

BEFORE YOU CONNECT IT
Use a momentary (push-and-release) button, not a latching one. A latching switch left “on” would hold the release request — the 5 s cap still protects the solenoid, but the door would re-release every time the software re-armed.

## 4.6 The front-panel lights

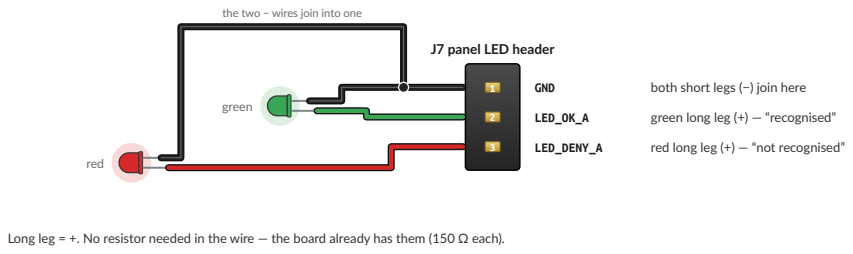
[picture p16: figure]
J7 panel LED header; GND; both short legs (−) join here; green; red; the two − wires join into one

2 | LED_OK_A | green long leg (+) — “recognised”
3 | LED_DENY_A | red long leg (+) — “not recognised”

Long leg = +. No resistor needed in the wire — the board already has them (150 Ω each).

Figure 4.6 — Two ordinary 5 mm LEDs on wires, into the 3-pin header J7. Both short legs share the ground pin; each long leg has its own pin.

Pin | Net | Plain words
1 | GND | ground — both LEDs’ short legs join here
2 | LED_OK_A | green LED’s long leg: lights when a palm is recognised
3 | LED_DENY_A | red LED’s long leg: lights when it isn’t

An LED only works one way round: the longer leg is the + side. The board already contains the small resistor each LED needs to limit its current, so the wires are just wires — no extra parts. The screen shows the same information in words; the lights exist so the result can be seen from across the room.

FOR THE ENGINEER
IO1 → R9 150 Ω → J7.2 (green), IO2 → R10 150 Ω → J7.3 (red); ~8 mA each with a 2 V LED from 3.3 V. Any 5 mm LED with Vf ≤ 2.4 V works; a blue or white LED (Vf ≈ 3 V) would be dim. Header is a plain 1×3 2.54 mm pin header; use a 3-way Dupont housing so it cannot be plugged in reversed. Pin 1 is square. The yellow LED D4 on the board itself is a separate 3.3 V “power present” indicator (R7 1 kΩ).

BEFORE YOU CONNECT IT
Long leg to pin 2 or 3, short leg to pin 1. Reversed, the LED simply stays dark — nothing is damaged, so if a light never comes on, this is the first thing to check.

## 4.7 USB-C — programming and logs

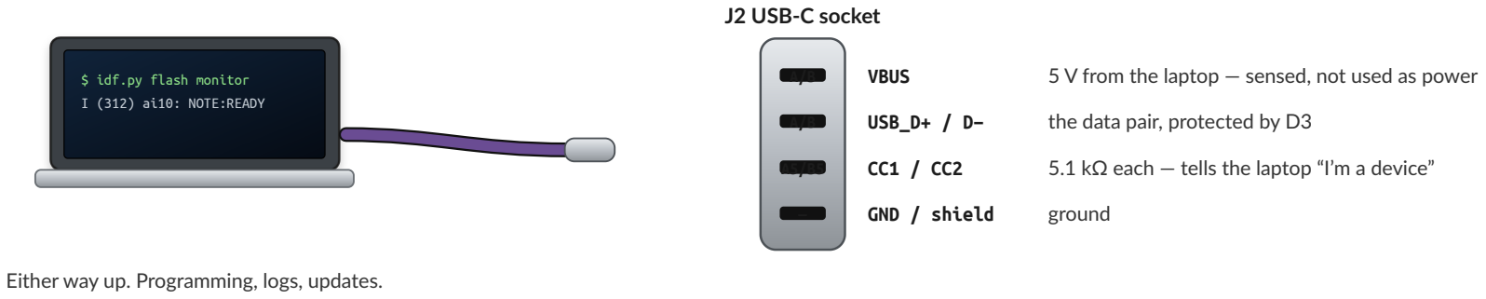
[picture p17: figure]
$ idf.py flash monitor I (312) ai10: NOTE:READY; J2 USB-C socket; GND / shield; ground

A/B | VBUS | 5 V from the laptop — sensed, not used as power
A/B | USB_D+ / D− | the data pair, protected by D3
A5/B5 | CC1 / CC2 | 5.1 kΩ each — tells the laptop “I’m a device”

Either way up. Programming, logs, updates.

Figure 4.7 — A standard USB-C cable to a laptop, into J2. Either way up. Used only by whoever maintains the unit.

USB-C pins | Net | Plain words
A4 A9 B4 B9 | VBUS | the laptop’s 5 V. The board only looks at it to know a cable is present; it never runs on it
A6 B6 / A7 B7 | USB_D+ / USB_D− the data pair, protected against static by D3
A5 / B5 | CC1 / CC2 | two small resistors that tell the laptop “I am a device, not a charger”

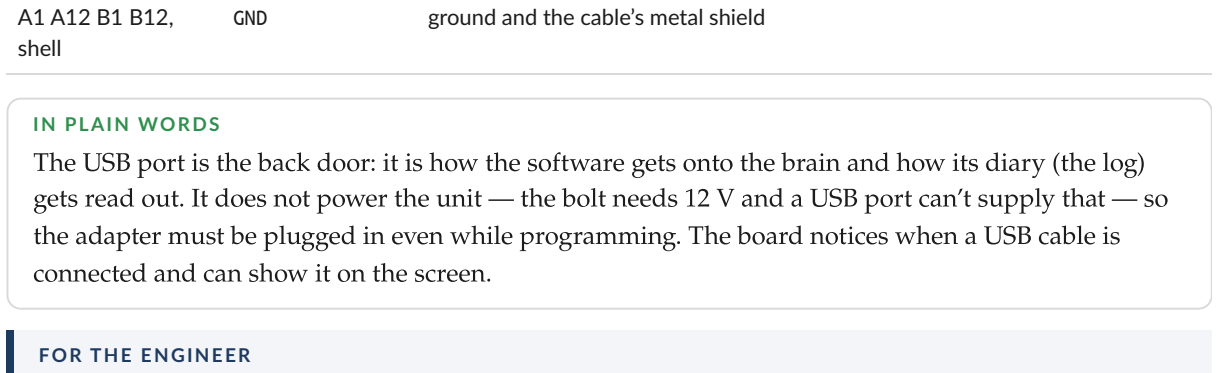
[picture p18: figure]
A1 A12 B1 B12, shell; GND; ground and the cable’s metal shield; IN PLAIN WORDS; FOR THE ENGINEER

The USB port is the back door: it is how the software gets onto the brain and how its diary (the log) gets read out. It does not power the unit — the bolt needs 12 V and a USB port can’t supply that — so the adapter must be plugged in even while programming. The board notices when a USB cable is connected and can show it on the screen.

ESP32-S3 native USB on IO19 (D−) / IO20 (D+) — no bridge chip; the S3 enumerates as a CDC serial port and supports DFU. D3 USBLC6-2SC6 ESD array across D+/D− with VBUS reference. R3/R4 5.1 kΩ CC pull-downs (UFP/sink) so the host applies VBUS in either orientation. No VBUS power path by design (no diode-OR, no 5 V → 3.3 V regulator from USB): 12 V is required for U2/U3 anyway. R11 100 kΩ / R12 150 kΩ divide VBUS to 3.0 V on IO7 ( USB_DET ) so firmware can hold off the D+ pull-up until a host is present. Shield is tied straight to GND (prototype-appropriate; an RC to chassis is an EMC refinement). Recovery if USB enumeration ever breaks: hold BOOT (S2), tap RESET (S1), or use J6.

BEFORE YOU CONNECT IT
Plug the 12 V adapter in first, then USB. With only USB connected nothing lights up — that is expected, not a fault.

## 4.8 The debug header (normally empty)

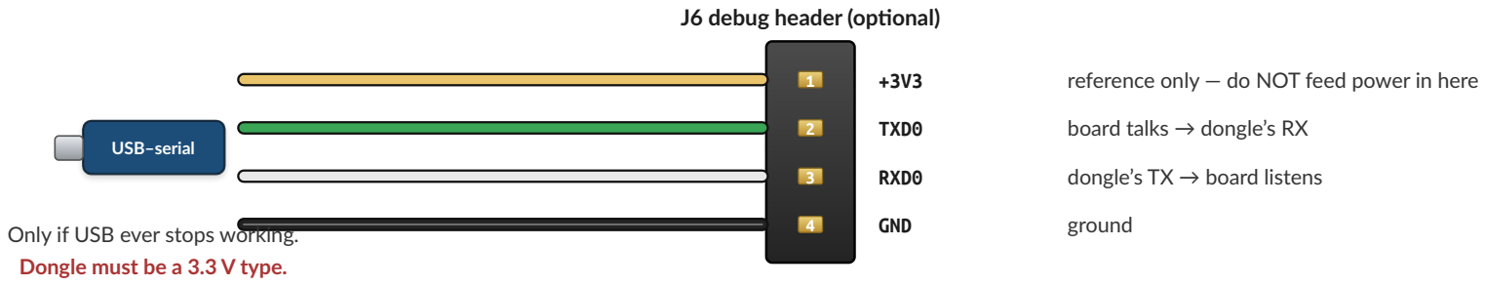
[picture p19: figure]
USB–serial; J6 debug header (optional); TXD0; board talks → dongle’s RX; RXD0; dongle’s TX → board listens; Dongle must be a 3.3 V type.

1 | +3V3 | reference only — do NOT feed power in here
4 | GND | ground Only if USB ever stops working.

Figure 4.8 — Four pins for a USB-to-serial dongle. A recovery path only; in normal life nothing is connected here.

Pin | Net | Plain words
1 | +3V3 | 3.3 V out of the board — a reference for the dongle, never a way to power the board
2 | TXD0 | board talks → connect to the dongle’s RX
3 | RXD0 | board listens ← connect to the dongle’s TX
4 | GND | ground

IN PLAIN WORDS
This is the same kind of two-wire conversation as the sensor cable, but between the brain and a laptop. It exists for one reason: if a software mistake ever leaves the USB port not responding, this header still works, because it is wired to the brain’s original console. Notice the crossing: the board’s “talk” pin goes to the dongle’s “listen” pin and vice-versa — the most common mistake in the world of serial cables.

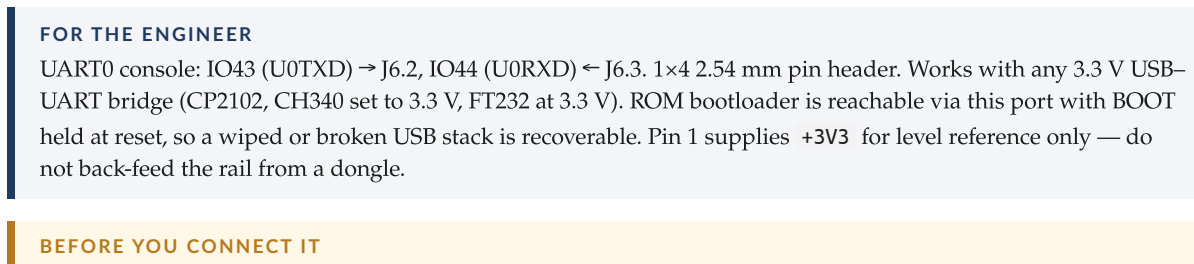
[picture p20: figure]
FOR THE ENGINEER; not back-feed the rail from a dongle.; BEFORE YOU CONNECT IT

UART0 console: IO43 (U0TXD) → J6.2, IO44 (U0RXD) ← J6.3. 1×4 2.54 mm pin header. Works with any 3.3 V USB– UART bridge (CP2102, CH340 set to 3.3 V, FT232 at 3.3 V). ROM bootloader is reachable via this port with BOOT held at reset, so a wiped or broken USB stack is recoverable. Pin 1 supplies +3V3 for level reference only — do

The dongle must be a 3.3 V type. A 5 V one can damage the brain’s pins. And never connect the dongle’s 5 V or 3.3 V output to pin 1 — pin 1 is an output.

# 5 Inside the board — the parts and what they do

## Forty-six parts sit on the board. Most of them exist to protect something, store a little energy, or keep a signal clean. Here is each one in ordinary words, with the engineering

detail beside it.

Parts are named as printed on the board: U chips and modules, D diodes and LEDs, C capacitors, R resistors, Q transistors, F fuses, J / CN connectors, S switches, BZ buzzer.

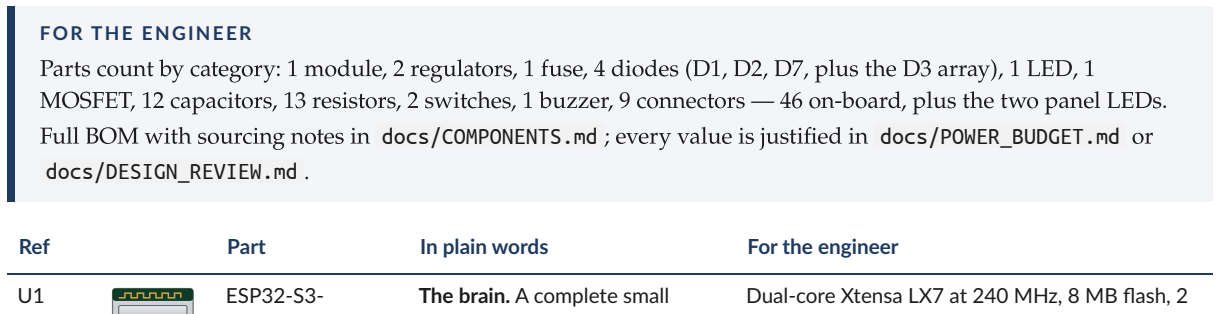
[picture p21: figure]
FOR THE ENGINEER; docs/DESIGN_REVIEW.md .; Ref; Part; In plain words; For the engineer; ESP32-S3-; The brain. A complete small

Parts count by category: 1 module, 2 regulators, 1 fuse, 4 diodes (D1, D2, D7, plus the D3 array), 1 LED, 1 MOSFET, 12 capacitors, 13 resistors, 2 switches, 1 buzzer, 9 connectors — 46 on-board, plus the two panel LEDs. Full BOM with sourcing notes in docs/COMPONENTS.md ; every value is justified in docs/POWER_BUDGET.md or

WROOM-1
(N8R2)

computer on one module, with Wi-Fi, Bluetooth and USB built in, plus its own antenna printed on the top edge.

Dual-core Xtensa LX7 at 240 MHz, 8 MB flash, 2 MB PSRAM, native USB. Antenna keep-out on the board edge; 3 GND pads incl. thermal pad. Strapping pins IO0/IO3/IO45/IO46 left free except IO0 (BOOT).

U2 | R-78E

RECOM R-78E3.3-
1.0

Pressure reducer, 12 → 3.3 V. Makes the gentle voltage the brain, screen and lights run on. Runs cool.

Switching regulator, 1 A, ~93 % efficient, 3-pin SIP, needs ≥ 7 V in. Loss ≈ 0.09 W. Drop-in alternative K7803-1000R3.

U3 | R-78E RECOM R-78E5.0-
| 1.0

Pressure reducer, 12 → 5 V. Feeds only the sensor.

Switching regulator, 1 A. Must be the 1.0 A part (same body as 0.5 A). ≈ 0.35 W loss at worst load; copper pour suffices.

F1 | Polyfuse 2 A hold / 16 V

Automatic circuit breaker. If something shorts, it goes high-resistance and cuts the current; when it cools, it resets itself.

Bourns MF-MSMF200/16, 1812. 4 A trip. Guards against an oversized adapter; with a 2 A SMPS adapter the adapter’s own limit acts first.

D1 | SS34 Schottky diode

One-way valve. Lets power in only if the adapter is the right way round. Backwards, nothing flows and nothing breaks.

3 A, 40 V, ~0.5 V forward drop (≈ 0.5 W during a 5 s release). Everything on the board sits behind it.

D7 | SMAJ15A TVS | Surge clamp. Swallows short voltage spikes — from the lock cable acting as an antenna, or a noisy adapter — before they reach anything delicate.

15 V stand-off, ~24 V clamp, 400 W peak. Protects Q1 (30 V) and the regulators.

C1

470µ

470 µF 25 V
electrolytic

The big tank. Stores a little energy so that when the bolt suddenly draws current, the voltage doesn’t sag.

Low-ESR 105 °C, 8 mm radial. Also absorbs the switching ripple from U2/U3. C5/C7 10 µF at the regulator inputs.

C2,
C12

100µ

100 µF 10 V, ×2 Smaller tanks at the 3.3 V output and right at the sensor socket, for the sensor’s start-up gulp.

SMD electrolytic/polymer 6.3 × 5.4 mm (a 100 µF MLCC in 0805 does not exist). Within RECOM’s 220 µF output-capacitance limit.

Ref | Part | In plain words | For the engineer
C3, C6, C8, C4, C10, C11 | 100 nF … 10 µF ceramics | Tiny tanks placed right next to each chip’s power pin, so fast demands are met locally. | C3 100 nF at U1 pin 2 (≤ 5 mm), C6/C8 10 µF at regulator outputs, C4 1 µF on EN (10 ms reset RC with R1), C10/C11 100 nF button debounce.
Q1 | AO3400A N- MOSFET

Electronic switch for the bolt — like a relay with no moving parts. The brain nudges it with 3.3 V; it switches the full 12 V current.

SOT-23, 30 V, 5.7 A, RDS(on) ≈ 40 mΩ, VGS(th) ≤ 1.45 V. Low-side. R13 100 Ω gate series, R2 10 kΩ gate pull-down.

D2 | SS54 Schottky diode

Kick-back catcher. When the switch opens, the coil tries to keep current flowing; this diode gives it a safe path instead of a damaging spike.

5 A, 40 V, across J3 (cathode to +12V). Flyback / freewheeling diode.

R2

103

10 kΩ | Safety resistor that holds the switch firmly off while the brain is waking up, so the bolt can never twitch at power-on.

Gate-to-source pull-down; GPIOs are high-impedance for ~50 ms after reset.

D3 | USBLC6-2SC6 | Static guard on the USB data wires. Your finger on the plug can carry thousands of volts of static;

Ultra-low-capacitance ESD array, SOT-23-6, on D+/D− with VBUS reference.

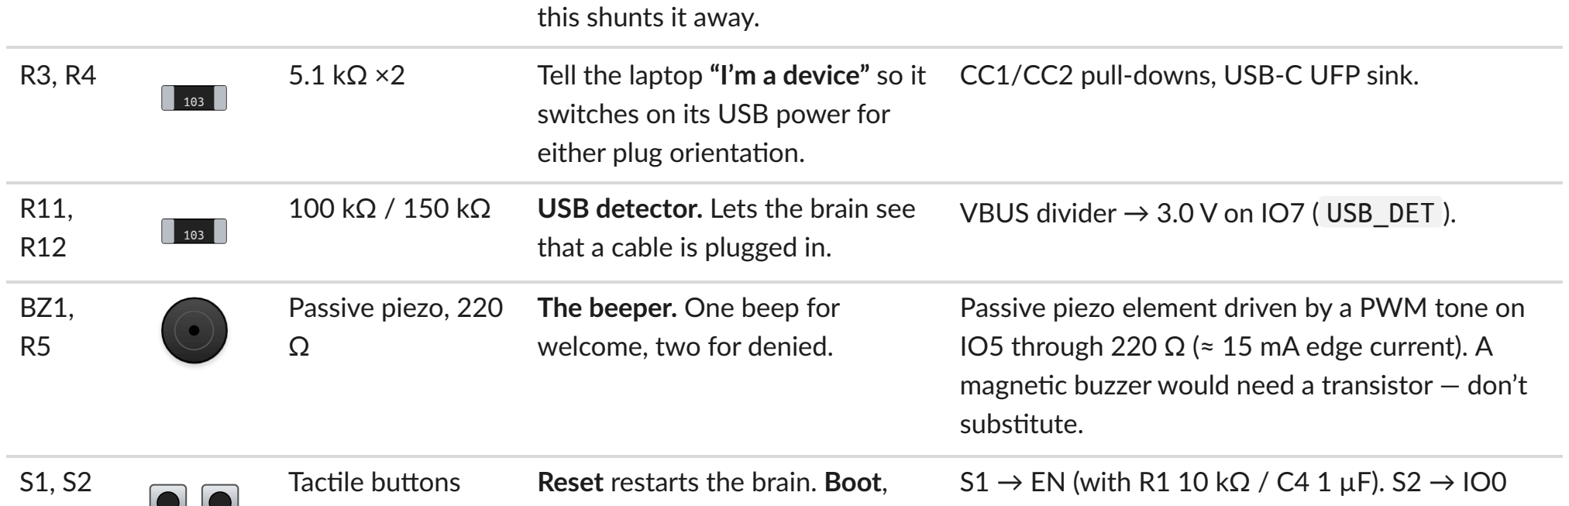
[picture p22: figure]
this shunts it away.; switches on its USB power for either plug orientation.; CC1/CC2 pull-downs, USB-C UFP sink.; that a cable is plugged in.; Passive piezo, 220 Ω; The beeper. One beep for welcome, two for denied.; substitute.; Tactile buttons; Reset restarts the brain. Boot,

5.1 kΩ ×2 | Tell the laptop “I’m a device” so it
100 kΩ / 150 kΩ | USB detector. Lets the brain see
VBUS divider → 3.0 V on IO7 ( USB_DET ).

Passive piezo element driven by a PWM tone on IO5 through 220 Ω (≈ 15 mA edge current). A magnetic buzzer would need a transistor — don’t

held while pressing Reset, puts it into programming mode. Both only for the maintainer.

S1 → EN (with R1 10 kΩ / C4 1 µF). S2 → IO0 strapping with C10 100 nF; internal pull-up.

D4, R7 | Yellow LED, 1 kΩ | Power light on the board itself: proves the 3.3 V supply is alive even before the screen wakes up.
0603 LED on +3V3 , ~1.3 mA.

R6, R8,
C11

103

10 kΩ, 1 kΩ, 100
nF

Make the exit button read cleanly and protect the brain from the long wire.

Pull-up, series guard, RC debounce on IO6 (Section 4.5).

R9,
R10

103

150 Ω ×2 | Current limiters for the two panel lights.

~8 mA each from 3.3 V GPIOs (Section 4.6).

# 6 Where the power goes

One 12 V supply comes in. Three voltages come out of it. Each part gets the voltage it was built for.

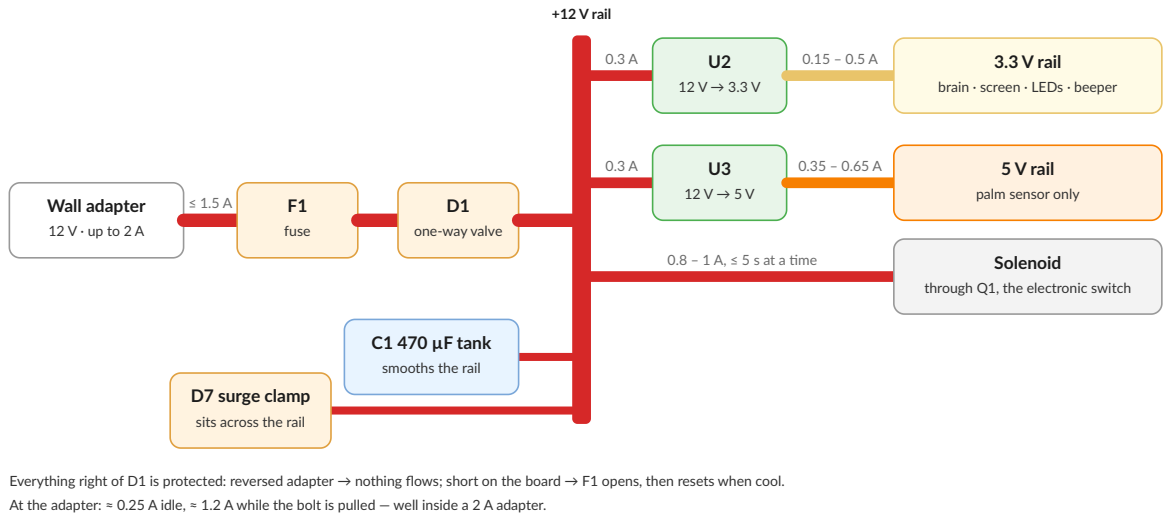
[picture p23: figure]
Wall adapter; fuse; one-way valve; +12 V rail; C1 470 µF tank; smooths the rail; D7 surge clamp; sits across the rail; 3.3 V rail; brain · screen · LEDs · beeper; 5 V rail; palm sensor only; 0.8 – 1 A, ≤ 5 s at a time; Solenoid; through Q1, the electronic switch

Everything right of D1 is protected: reversed adapter → nothing flows; short on the board → F1 opens, then resets when cool.

At the adapter: ≈ 0.25 A idle, ≈ 1.2 A while the bolt is pulled — well inside a 2 A adapter.
Figure 6.1 — The power tree. Left to right: adapter, fuse, one-way valve, then the +12 V rail. Two regulators step it down; the solenoid takes it straight. Widths are roughly proportional to current.

IN PLAIN WORDS
Think of the 12 V rail as the mains water pipe in a house. The fuse is a stopcock that shuts itself if a pipe bursts; the one-way valve stops water flowing back into the street. The big tank (C1) keeps the pressure steady when a tap opens suddenly — that tap is the solenoid, the thirstiest thing in the box. Two pressure reducers (U2, U3) feed the delicate things: the brain and screen at 3.3 V, the sensor at 5 V.
Rail | Made by | Feeds | Typical | Worst

+12V adapter via F1,
| D1 | U2, U3, solenoid (via Q1), C1, D7 | 0.25 A idle | 1.5 A for ≤ 5 s
+5V | U3 (1 A) | sensor only | 0.35 – 0.43 A
0.63 A + start-up
spike
+3V3 U2 (1 A) | brain, screen + backlight, panel LEDs, buzzer, pull-ups,
| | debug header
0.15 A | 0.52 A (Wi-Fi burst)
VBUS laptop | nothing — sensed only (R11/R12 → IO7) | 0 | 0

FOR THE ENGINEER
Worst-case dissipation: D1 0.53 W (5 s bursts), U3 0.35 W, U2 0.09 W, F1 0.1 W, Q1 0.03 W — copper pours suffice, no heatsinks. Trace widths (POWER_BUDGET §6): +12V trunk to J3 and +5V trunk to CN1 ≥ 1.0 mm at 1 oz, +12V to U2/U3 0.6 mm, signals 0.2–0.25 mm. A 3 A adapter is acceptable and lets F1 (4 A trip) act on a hard short before the adapter does. Unknowns: AI10 inrush (mitigated by C12), display current (est. 100 mA).

# 7 What happens during a scan

## From switching on to a door opening, in seven steps — and which wire each step travels

on.

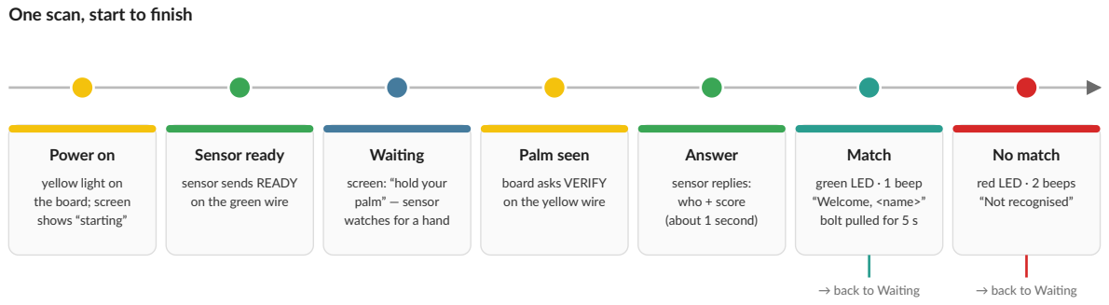
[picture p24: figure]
Power on; yellow light on the board; screen shows “starting”; Sensor ready; sensor sends READY on the green wire; Waiting; screen: “hold your palm” — sensor watches for a hand; Palm seen; board asks VERIFY on the yellow wire; Answer; sensor replies: who + score (about 1 second); Match; green LED · 1 beep “Welcome, <name>” bolt pulled for 5 s; No match; red LED · 2 beeps “Not recognised”; → back to Waiting; One scan, start to finish

Figure 7.1 — One scan. Yellow steps are messages from the board to the sensor (yellow wire); green steps are the sensor’s replies (green wire).

1. Power on. The adapter is plugged in. The yellow light on the board comes on within a fraction of a second (the 3.3 V rail is alive). The brain boots and shows “starting” on the screen. The sensor, on its own 5 V, boots too.
2. Sensor ready. A few seconds later the sensor sends a “ready” message down the green wire. Until it does, the board sends nothing — asking too early is ignored or answered with an error.
3. Waiting. The screen says “hold your palm over the sensor”. The sensor watches for a hand at the right distance; the board listens.
4. Palm seen. The board sends the “verify” command on the yellow wire. The sensor lights its infrared LEDs, photographs the veins, and compares the pattern with the people it has stored.
5. Answer. About a second later the reply arrives on the green wire: either a person number and a confidence score, or “nobody”.
6. Match. The board switches the green light on (J7 pin 2), beeps once (BZ1), shows “Welcome” on the screen, and switches Q1 on so 12 V flows through the bolt for five seconds. Then Q1 opens, D2 catches the coil’s kick, the spring pushes the bolt out, and everything returns to Waiting.
7. No match. Red light (J7 pin 3), two low beeps, “Not recognised”. Back to Waiting.

The exit button skips steps 3–5 entirely: pressing it produces the same five-second release. Adding a person is the same conversation with a different question — the screen guides the maintainer through it, and the sensor stores the new pattern in its own memory, not on the board.

FOR THE ENGINEER
Firmware skeleton: UART1 task (framing, XOR check, NOTE:READY gate) → event queue → application state machine (IDLE → VERIFY_PENDING → RELEASE(5 s) → IDLE) → outputs. The release timer is a hardware timer, and the ESP-IDF task watchdog is armed on the application task; a hung task resets the chip, and R2 guarantees Q1 is off through the reset. VERIFY (0x12) carries a timeout byte; NOTE messages report face/palm position while the module is searching, so the screen can say “a little higher”. Score threshold and template management stay inside the AI10.

# 8 Before you power it on

Ten minutes with a multimeter, in this order. Each line prevents a specific way of breaking something.

### BENCH, BEFORE ANYTHING IS PLUGGED INTO THE BOARD

### BOARD, EMPTY (NO MODULES, NO ADAPTER)

### FIRST POWER

### ALWAYS

IF SOMETHING IS WRONG
If anything smells hot, gets hot to the touch, or the yellow light flickers: unplug the adapter first, think second. The fuse resets itself once it cools, so a flickering light usually means a short somewhere downstream.

Adapter measures 11.5 – 12.6 V with nothing connected, and its label shows ⊕ on the centre pin. Sensor, powered on its own: the green wire idles at ≤ 3.6 V. If it reads 5 V, stop and ask for the divider.
Solenoid coil resistance is roughly 10 – 20 Ω (≈ 0.6 – 1.2 A at 12 V). An open circuit or under 5 Ω means a faulty unit.
Screen module’s pin order matches the table in Section 4.3, read off its silkscreen.
Buzzer says passive and piezo on the listing.

Resistance from +12V to GND is not a short (should climb as C1 charges through the meter).

No solder bridges across Q1, D3, or the regulator pins.

Adapter only — nothing else plugged in. The yellow light comes on. Measure: +12V ≈ 11.5 V (12 V minus D1), +5V = 4.9 – 5.1 V, +3V3 = 3.2 – 3.4 V.

Power off. Plug in the screen (pin 1 to pin 1). Power on: backlight lights.
Power off. Plug in the sensor. Power on: the sensor’s IR LEDs may glow faintly on a phone camera; the board reports “ready” in the log.
Power off. Connect the solenoid. Power on, press the exit button: bolt pulls for 5 s and releases.

One power source into the board at a time (J8 or J1).
USB is never the power source. 12 V first, USB second. A door secured by this bolt opens from inside by hand.

# A Appendix — pin tables

The complete reference for every connector, in one place. Net names are the schematic labels. Pin 1 is marked on the board.

J8 · DC jack 5.5 × 2.1 | Net
centre | VIN_12V
sleeve | GND
J1 · 12 V screw terminal | Net
1 | VIN_12V
2 | GND
J3 · lock terminal | Net
1 | +12V
2 | LOCK_SW
J5 · exit button | Net
1 | EXIT_SW
2 | GND
J7 · panel LEDs | Net
1 | GND
2 | LED_OK_A
3 | LED_DENY_A
| | J6 · debug UART | Net
| | 1 | +3V3
| | 2 | TXD0
| | 3 | RXD0
| | 4 | GND
CN1 · sensor (PicoBlade 1.25 mm) | Net
1 black | GND
2 yellow | SEN_RX
3 green | SEN_TX
4 red | +5V
J2 · USB-C | Net
A1 B1 A12 B12 | GND
A4 A9 B4 B9 | VBUS
A5 | CC1
B5 | CC2
A6 B6 | USB_D+
A7 B7 | USB_D−
| | A8 B8 | SBU — not connected
S1 (shell) | GND
J4 · display, 14-pin | Net | J4 · display, 14-pin | Net
1 VCC | +3V3 | 8 LED | +3V3
2 GND | GND | 9 SDO | — (NC)
3 CS | TFT_CS | 10 T_CLK | SPI_SCK
4 RESET | TFT_RST | 11 T_CS | TOUCH_CS
5 DC | TFT_DC | 12 T_DIN | SPI_MOSI
6 SDI | SPI_MOSI | 13 T_DO | SPI_MISO
7 SCK | SPI_SCK | 14 T_IRQ | TOUCH_IRQ

## ESP32-S3 pin use

GPIO | Net | Goes to
EN | EN | reset (S1, R1, C4)
IO0 | BOOT | boot strap (S2, C10)
IO1 | LED_OK | green panel LED → R9 → J7.2
IO2 | LED_DENY | red panel LED → R10 → J7.3
IO4 | LOCK_EN | solenoid switch → R13 → Q1 gate
IO5 | BUZZER | piezo → R5 → BZ1
IO6 | EXIT_BTN | exit button (R6, R8, C11) ← J5.1
IO7 | USB_DET | VBUS present (R11/R12)
IO8 | TOUCH_IRQ | J4.14
IO9 | TOUCH_CS | J4.11
IO10 | TFT_CS | J4.3
IO11 | SPI_MOSI | J4.6, J4.12
IO12 | SPI_SCK | J4.7, J4.10
IO13 | SPI_MISO | J4.13
IO14 | TFT_DC | J4.5
IO17 | SEN_RX | U1TXD → CN1.2 (yellow)
IO18 | SEN_TX | U1RXD ← CN1.3 (green)
IO19 | USB_D− | J2
IO20 | USB_D+ | J2
IO21 | TFT_RST | J4.4
IO43 | TXD0 | J6.2
IO44 | RXD0 | J6.3
IO3, IO45, IO46 | — | strapping pins, deliberately unconnected

# B Appendix — glossary

Term | Meaning
Capacitor | A tiny rechargeable tank for electricity. Big ones smooth the supply; small ones sit next to chips to answer sudden demands.
Debounce | Smoothing the chatter of a mechanical button so one press is read as one press.
Diode | A one-way valve for current. A Schottky diode is a low-loss kind; a TVS diode is one built to swallow spikes; an LED is one that lights up.
ESD | Electrostatic discharge — the spark from a finger. Thousands of volts, harmless to you, fatal to a chip.
Fail-secure | When power is lost, the lock stays locked. (The opposite, fail-safe, unlocks.)
Flyback diode | The diode across a coil that gives its stored energy somewhere safe to go when the coil is switched off.
Fuse (polyfuse) | A self-resetting fuse: it becomes a high resistance when too much current flows, then recovers when it cools.
MOSFET | An electronic switch. A small voltage on its gate lets a large current flow between its other two pins.
NIR | Near-infrared light, 700–900 nm — just beyond what the eye can see. Blood absorbs it; skin lets it through; that is why veins show up dark.
Pull-up / pull- down | A resistor that gives a wire a definite resting level (high or low) so it doesn’t float and pick up noise.
Regulator | A circuit that turns one voltage into another, steadily. Switching regulators do it efficiently and run cool.
Strapping pin | A pin the ESP32 reads at the instant of reset to decide how to start. Left alone unless you mean it.
Watchdog | A timer the software must keep resetting. If the software hangs, the timer expires and restarts the chip.

## References

palm-scan design documents: docs/NETLIST.md , docs/COMPONENTS.md , docs/POWER_BUDGET.md , docs/DATASHEETS.md , docs/DESIGN_REVIEW.md ; schematic hardware/kicad/palm-scan.pdf .

DFRobot, SEN0677 AI10 wiki and User Software Development Manual V1.0 (2025).
Espressif, ESP32-S3-WROOM-1 Datasheet v1.8.
RECOM, R-78E series datasheet; Alpha & Omega, AO3400A; Vishay, SS34; ST, USBLC6-2SC6.
W. Wu et al., “Review of palm vein recognition,” IET Biometrics 9(1), 2020.

Generated from the Rev 2.4 netlist by docs/wiring-guide/build.py . The board drawing in Section 3 is illustrative; connector positions are fixed during PCB layout. Makers: Ashmita K Rao, Adithya Satish, Vinod Kumar.

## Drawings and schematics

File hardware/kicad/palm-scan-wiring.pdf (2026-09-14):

# palm-scan Rev 2.4 - full wiring diagram

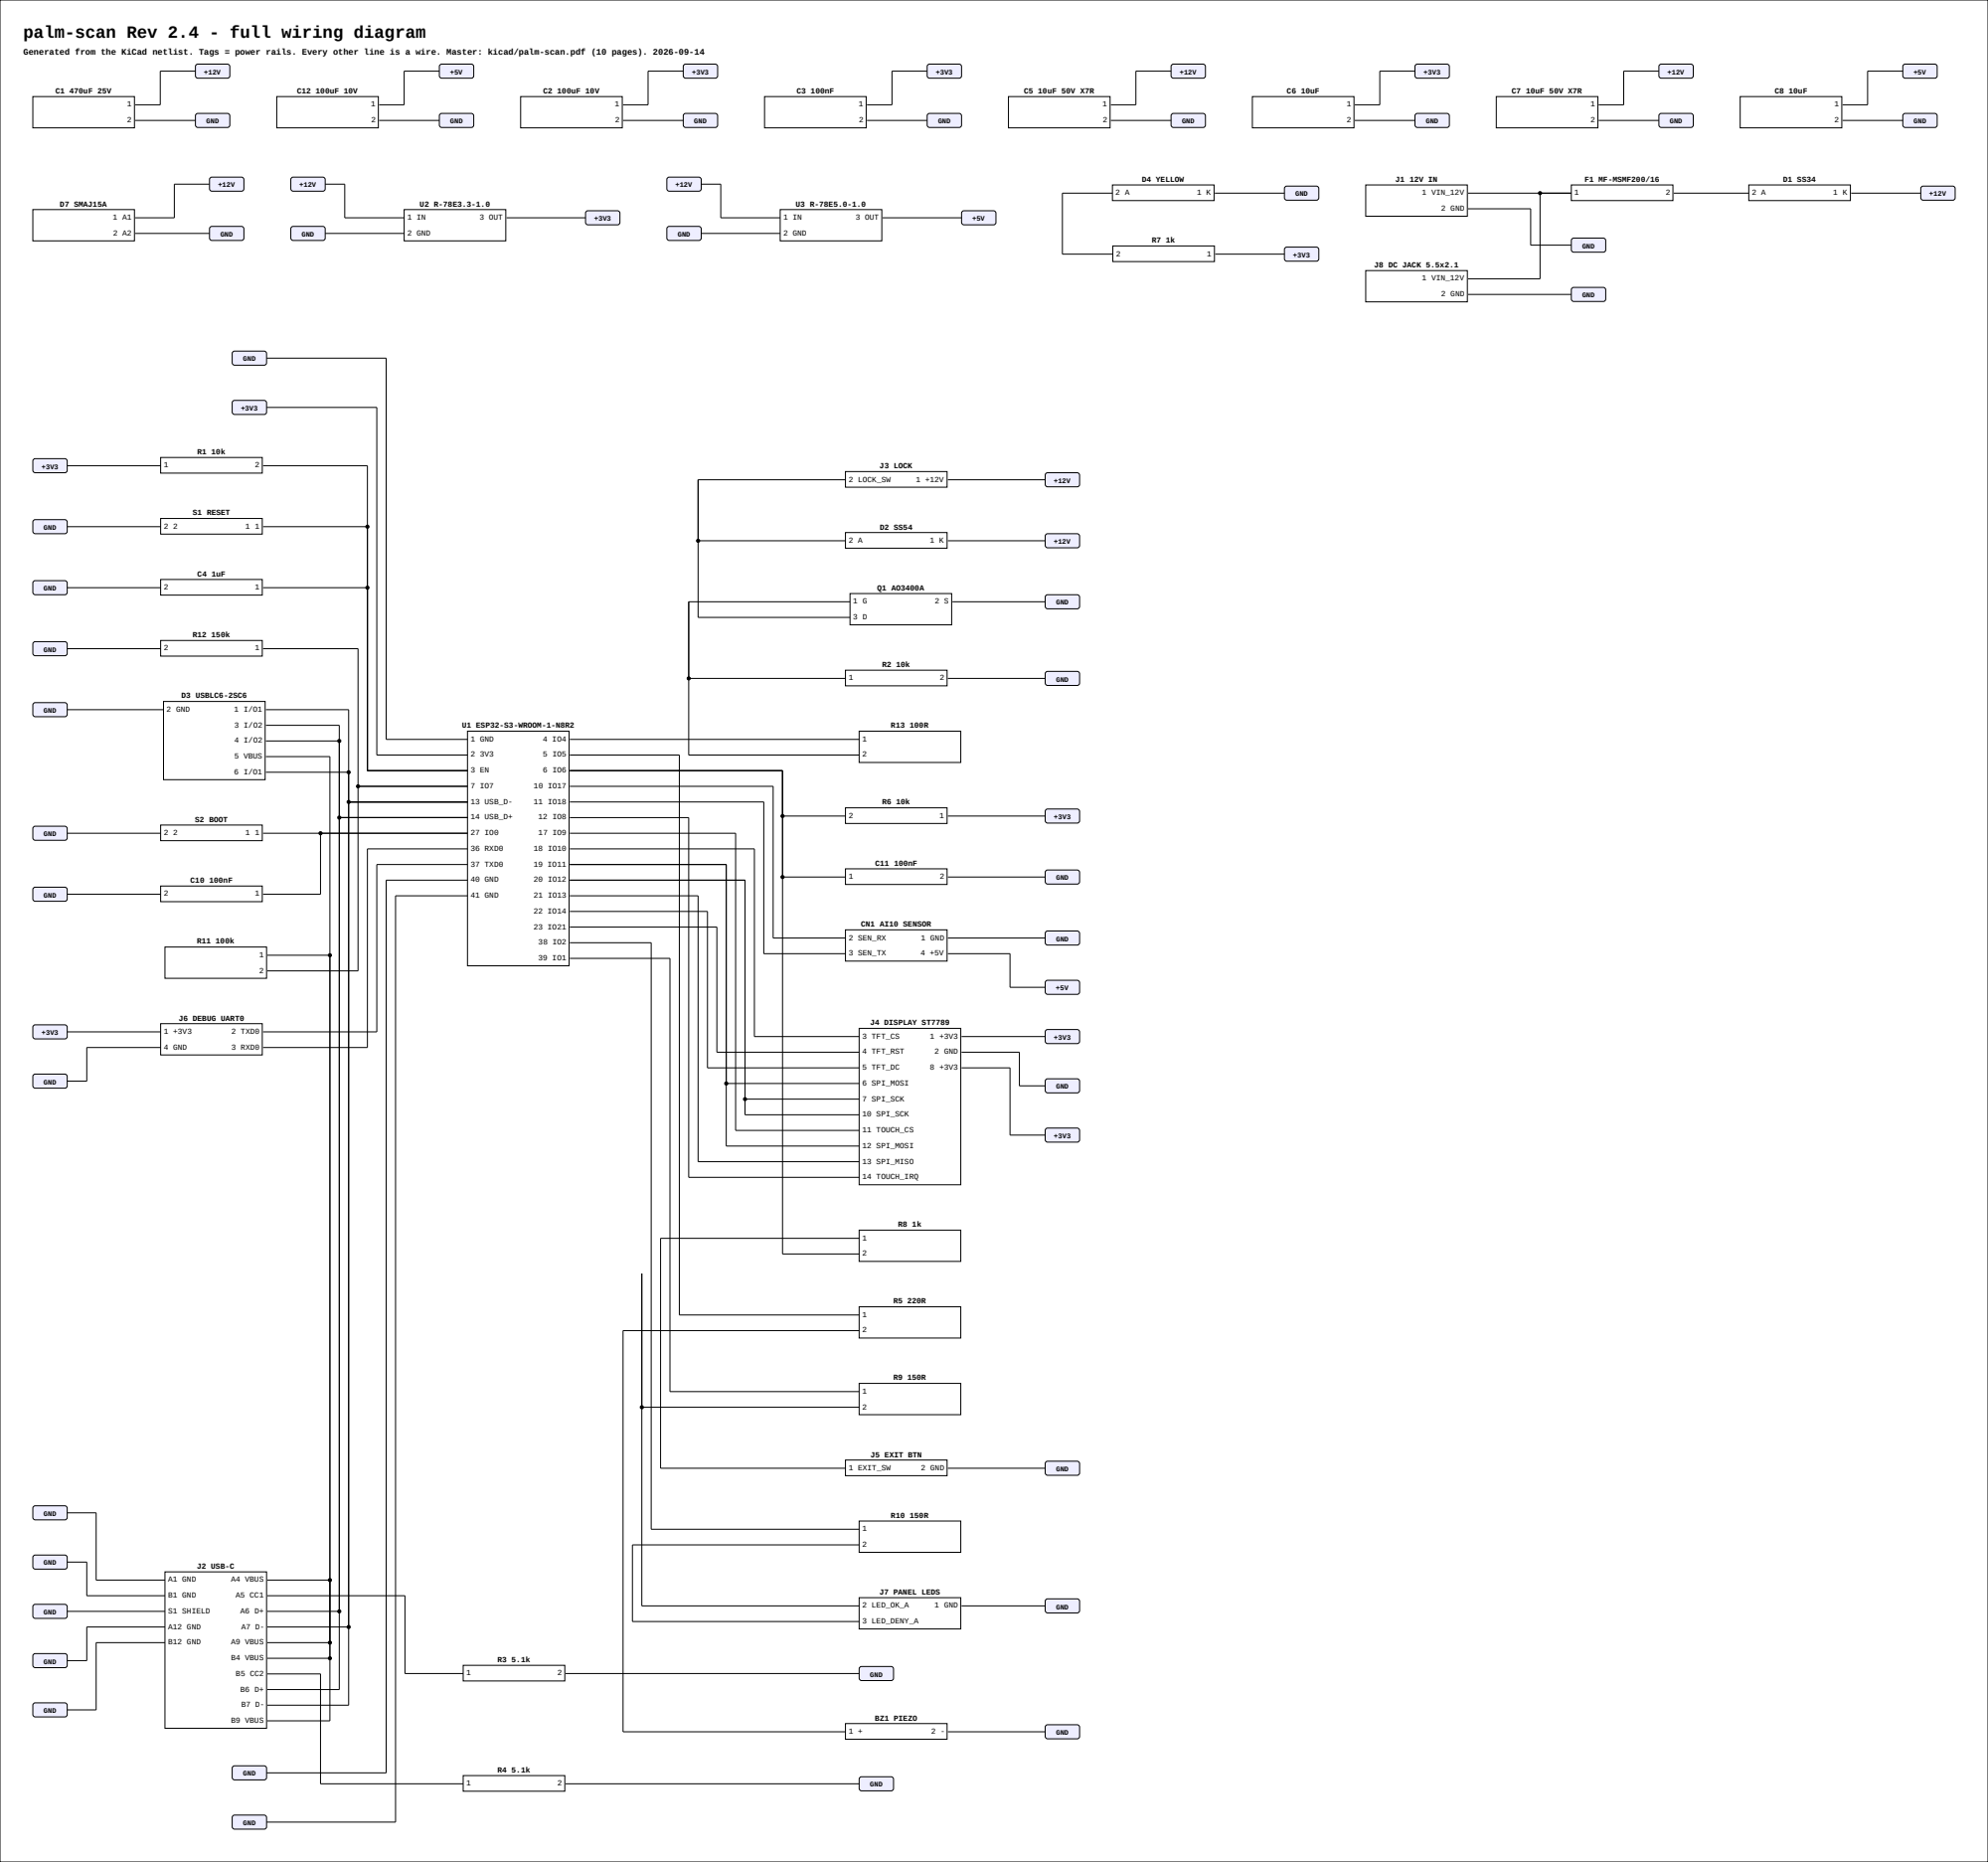
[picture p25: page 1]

Generated from the KiCad netlist. Tags = power rails. Every other line is a wire. Master: kicad/palm-scan.pdf (10 pages). 2026-09-14

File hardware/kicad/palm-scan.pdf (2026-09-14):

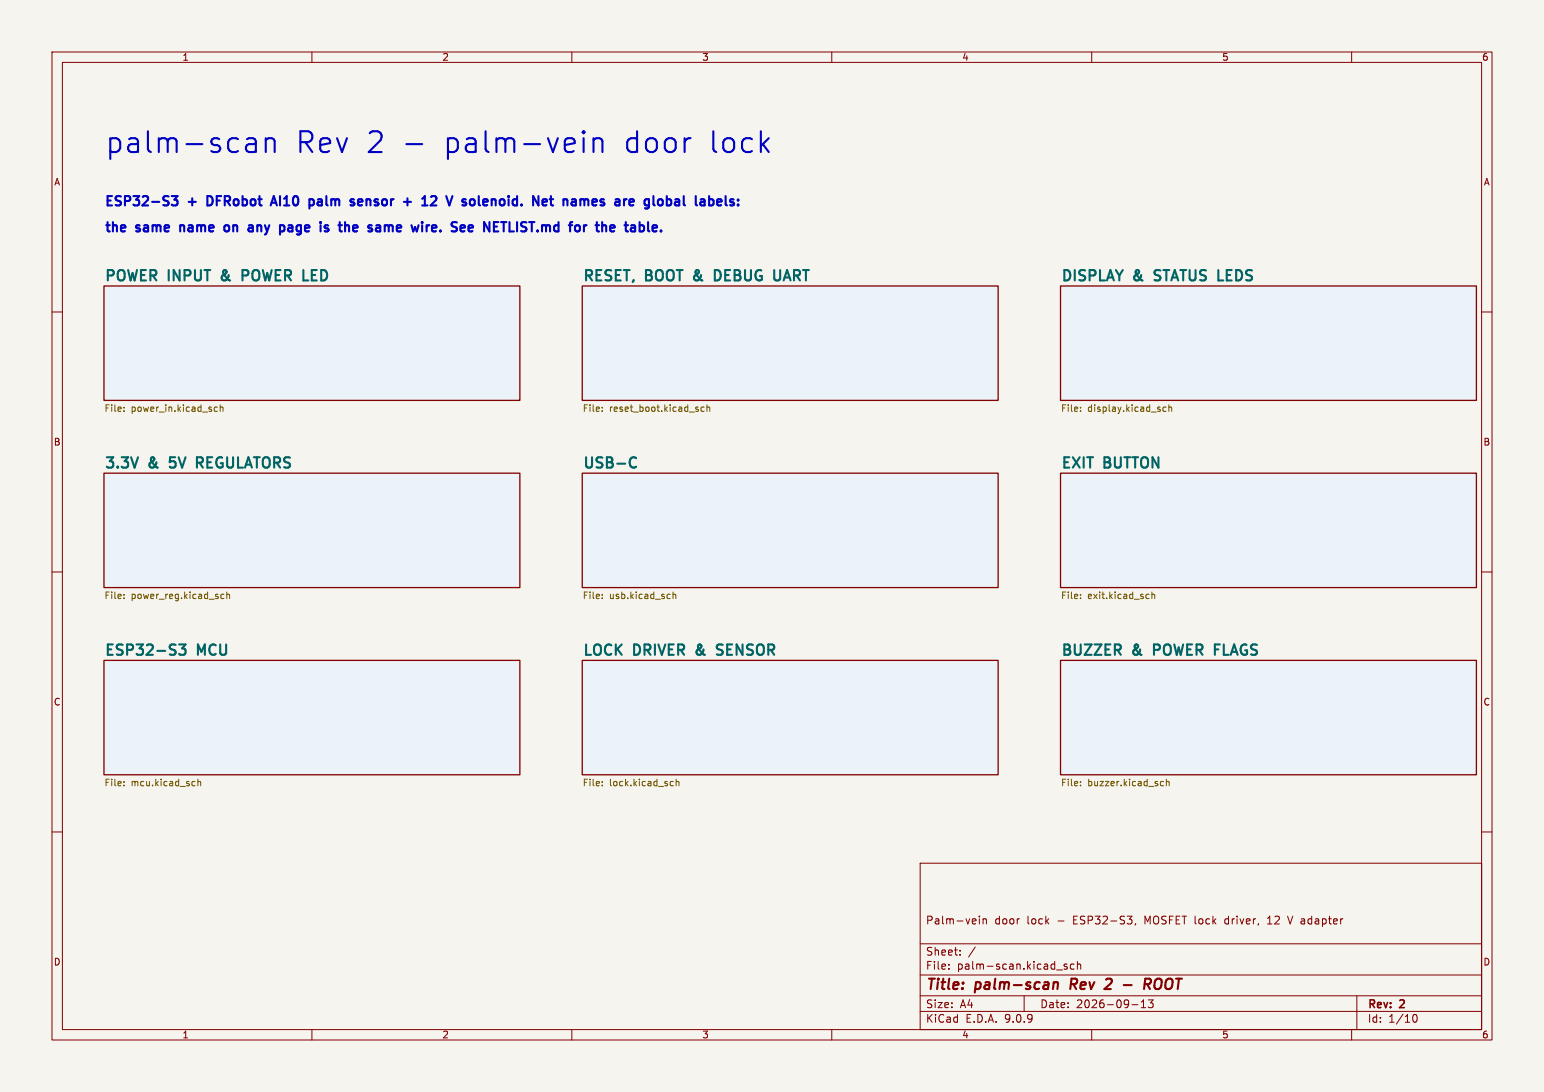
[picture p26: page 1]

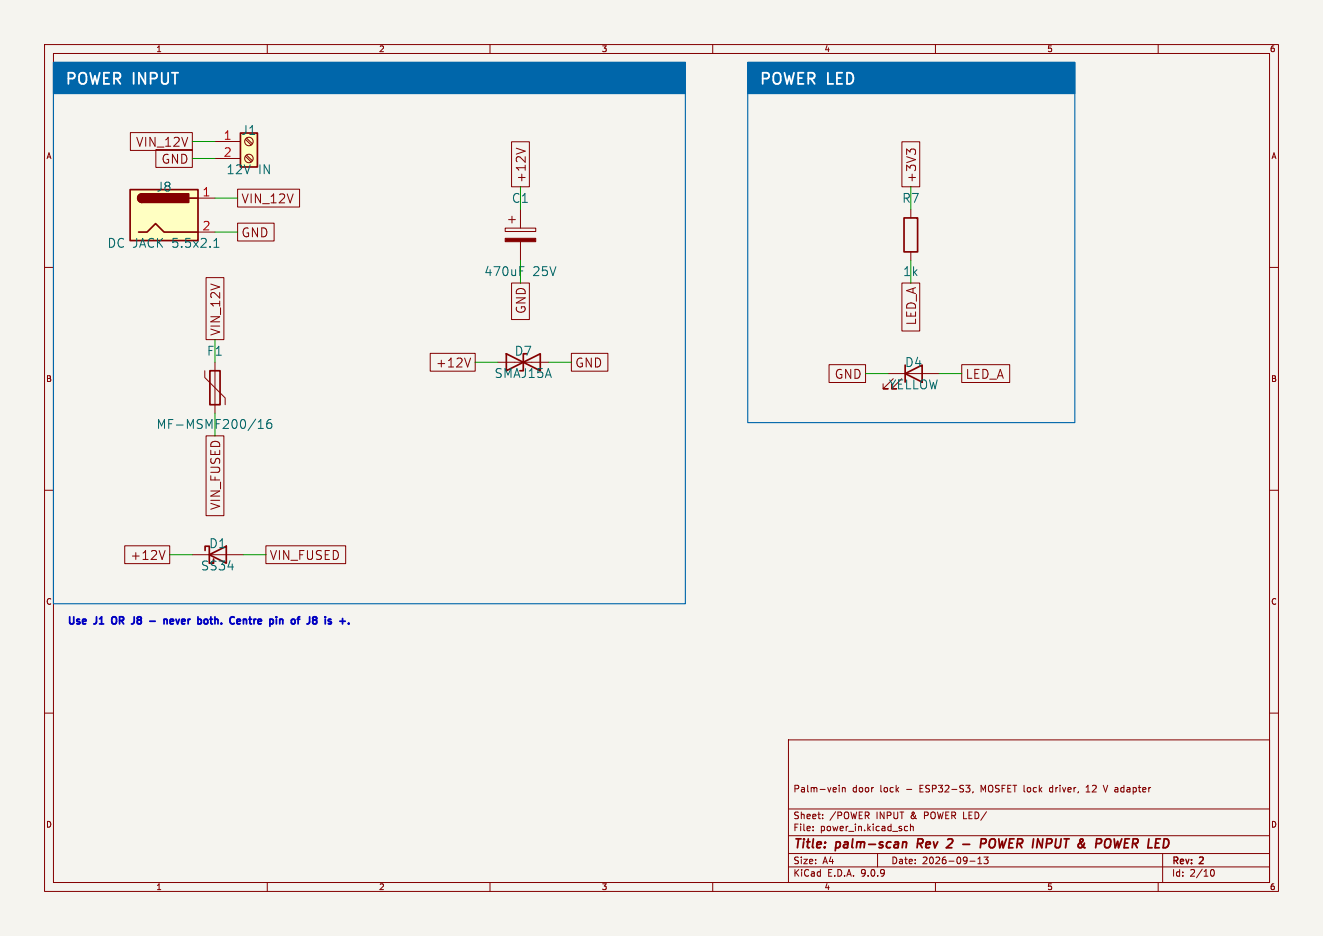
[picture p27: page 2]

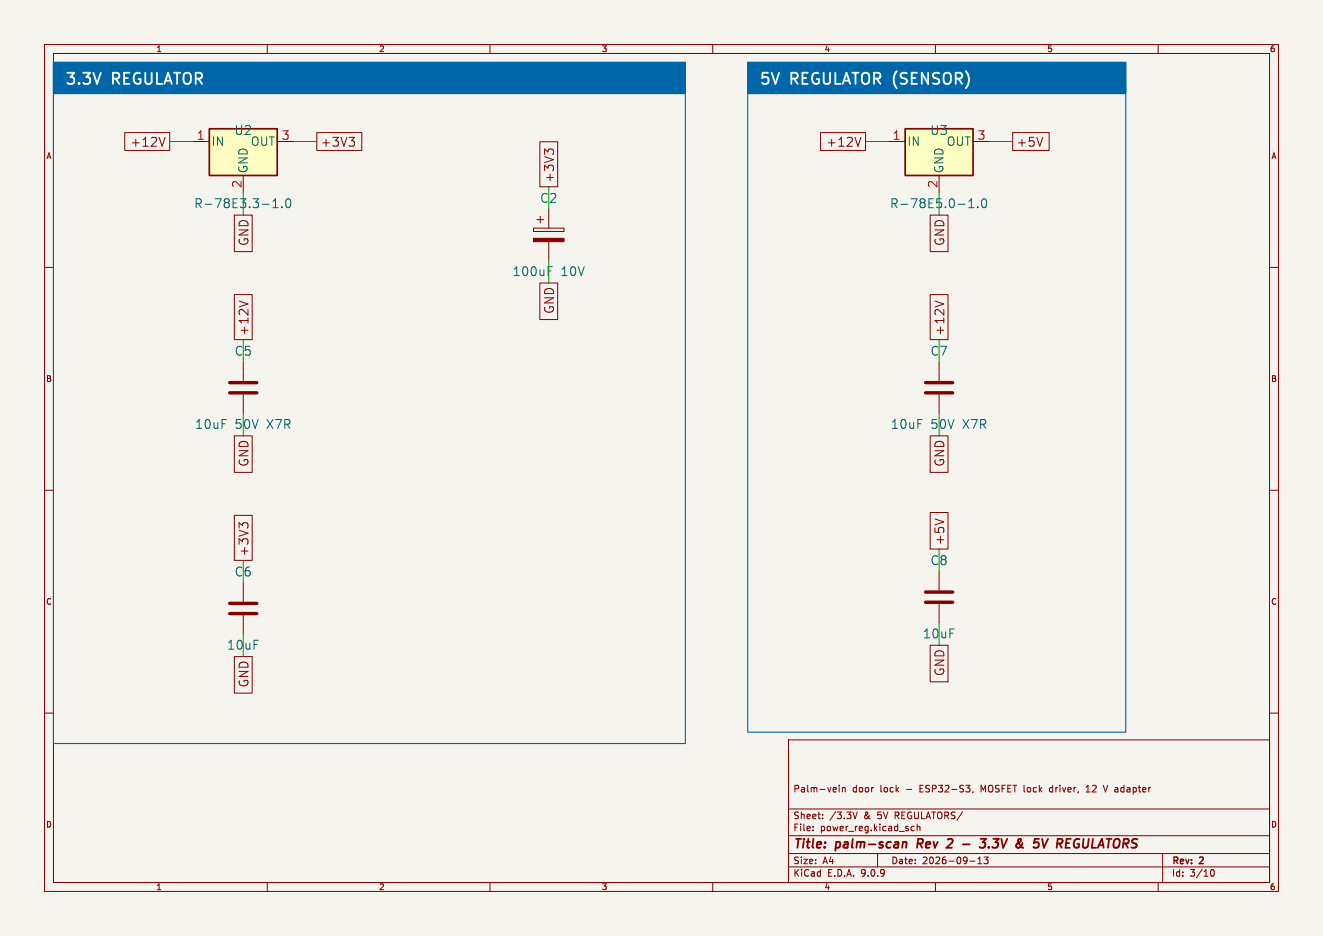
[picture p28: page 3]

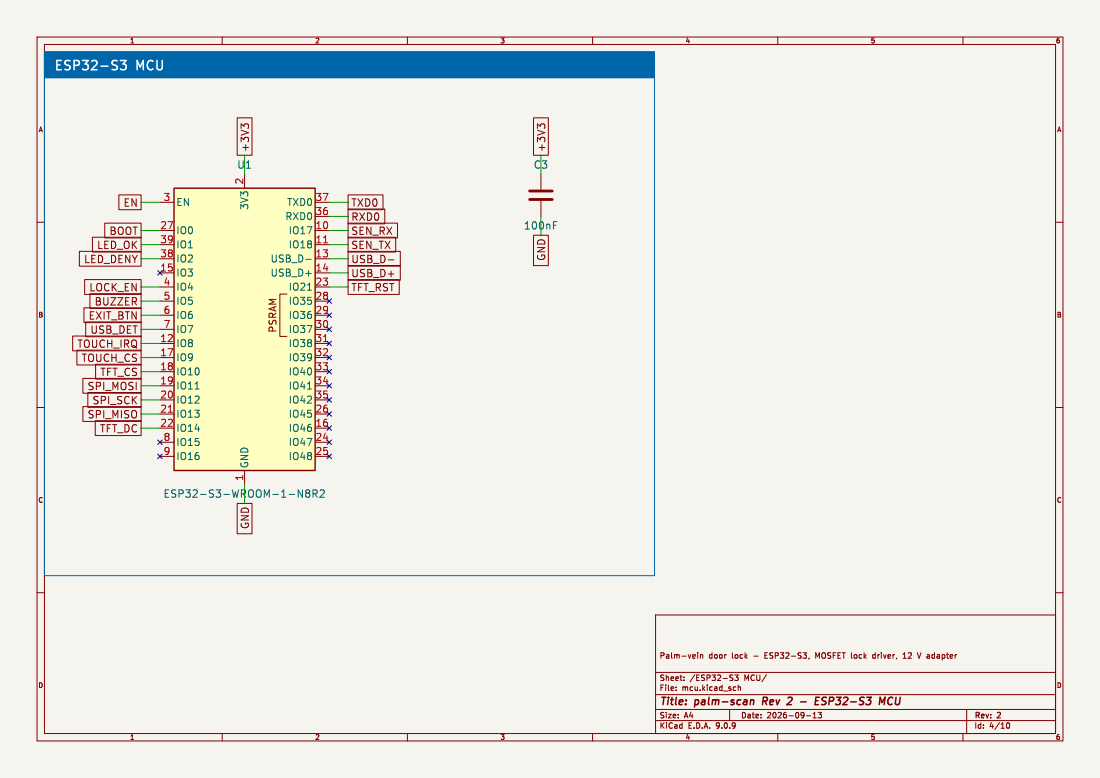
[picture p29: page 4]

TXD0
RXD0

LOCK_EN
BUZZER
EXIT_BTN
USB_DET

TOUCH_CS
TFT_CS
SPI_MOSI
SPI_SCK

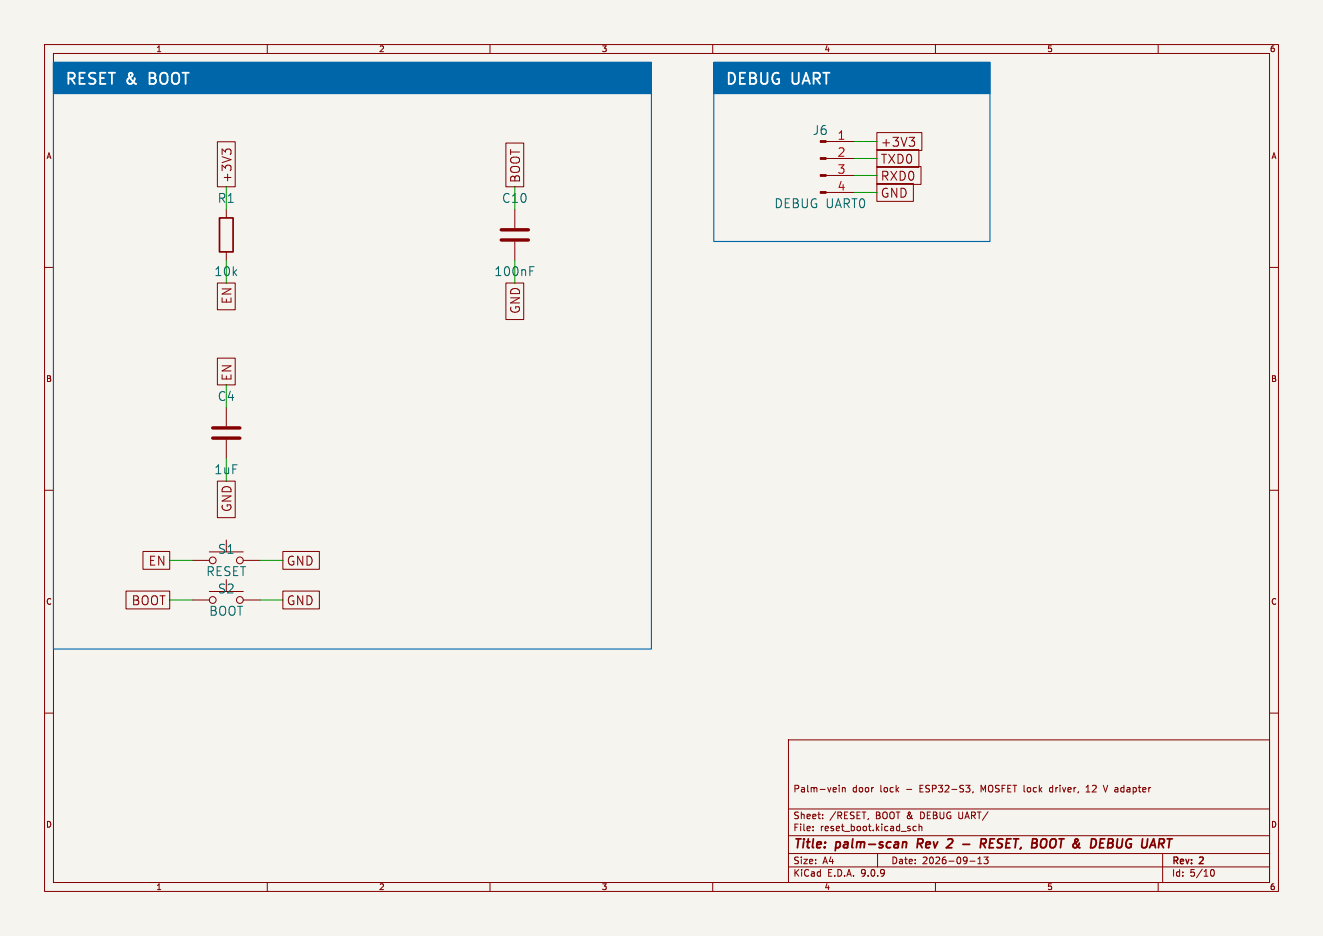
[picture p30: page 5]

+3V3
TXD0
RXD0

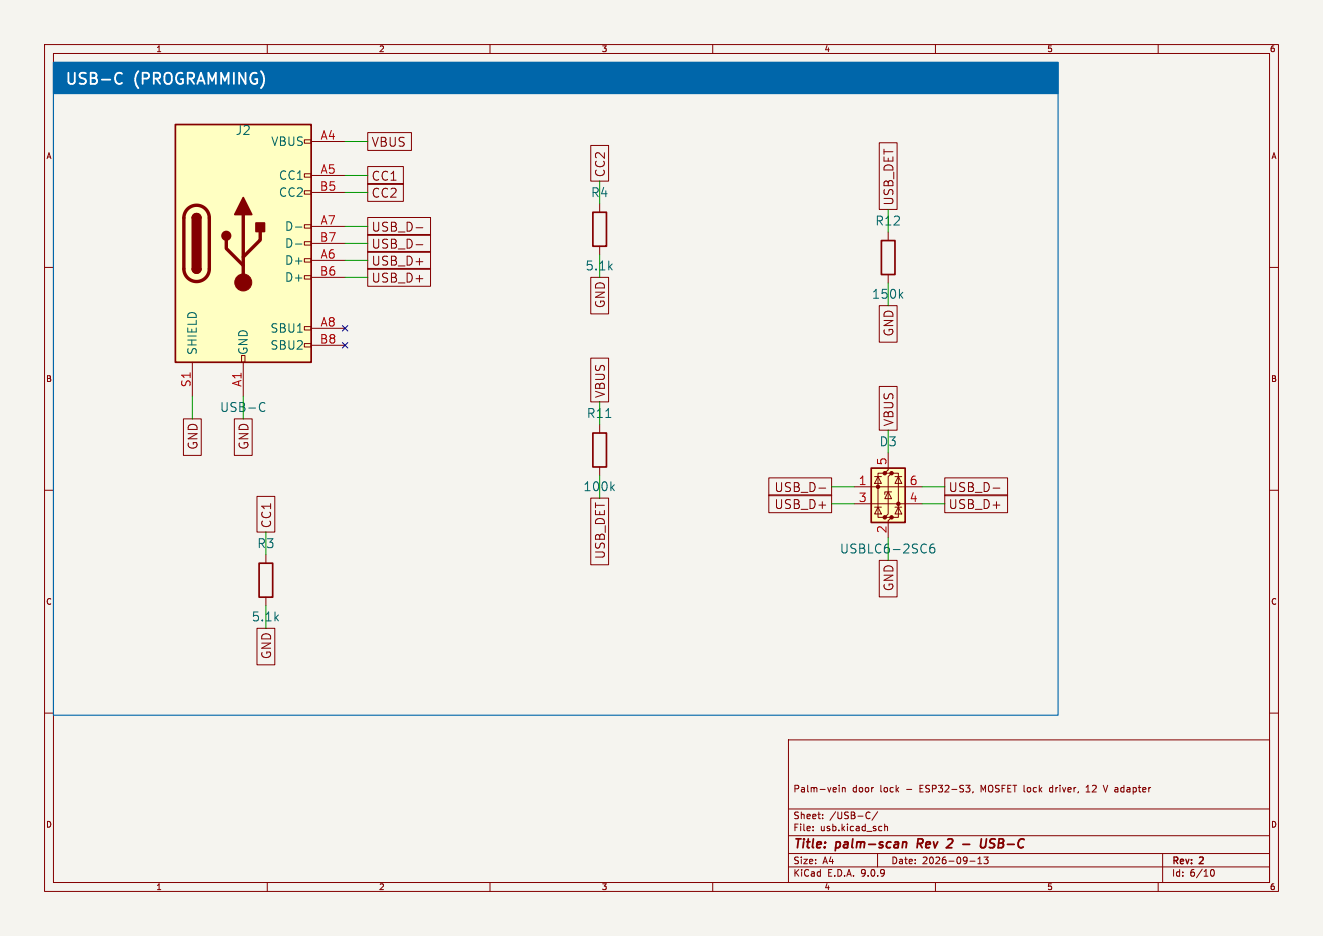
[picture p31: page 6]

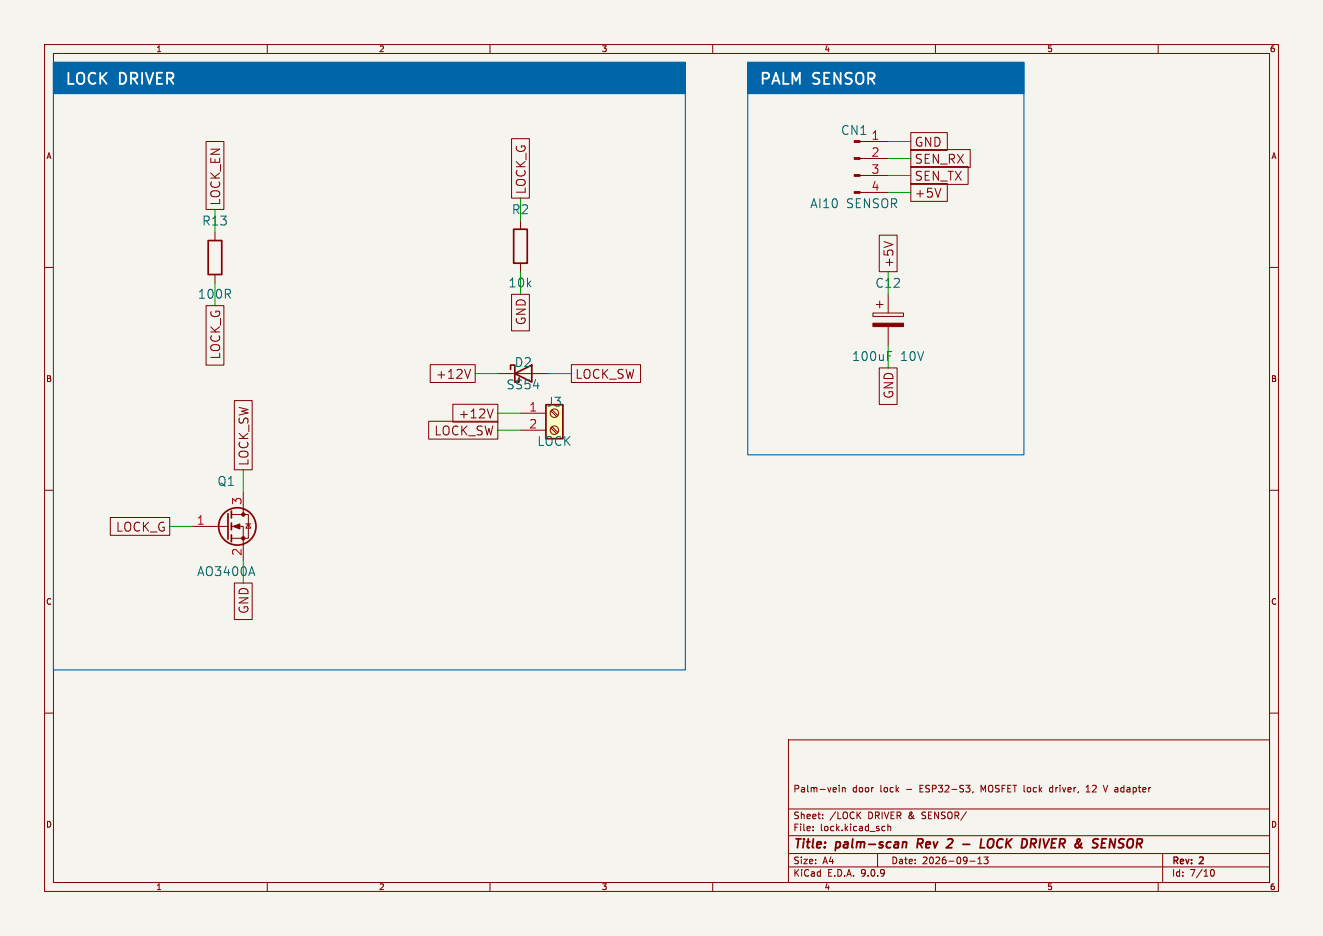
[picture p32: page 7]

GND
SEN_RX

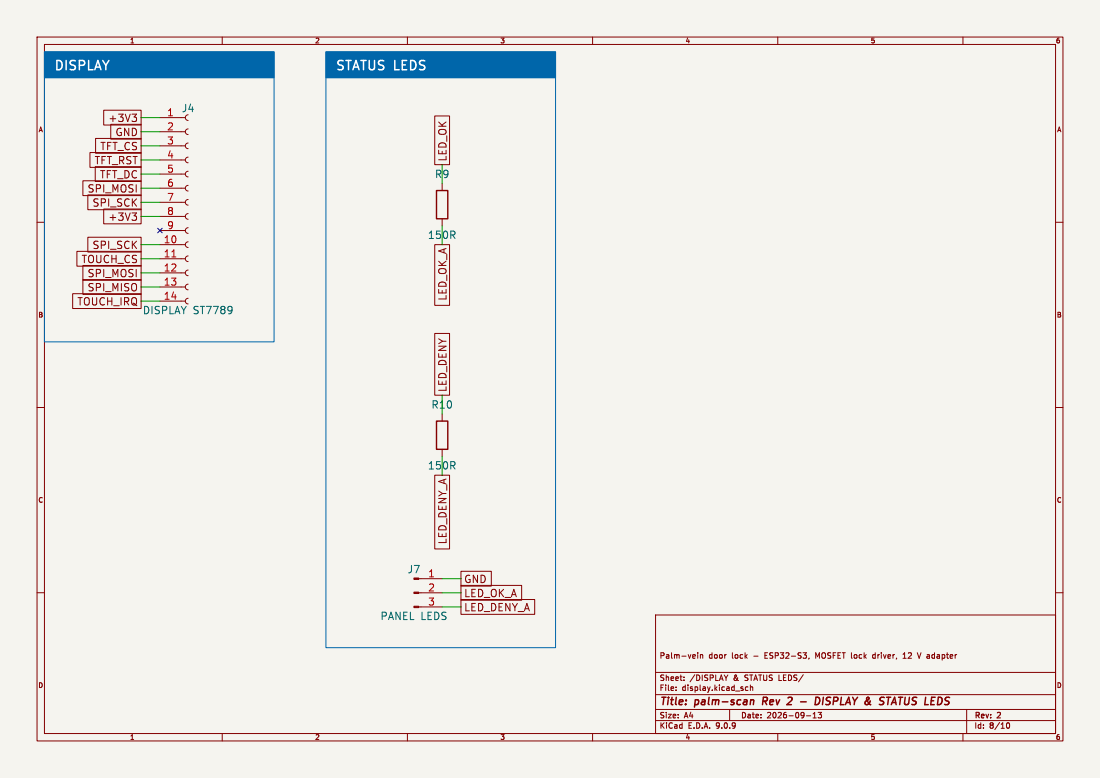
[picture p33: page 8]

+3V3
GND

TFT_RST
TFT_DC

SPI_MOSI
SPI_MISO
TOUCH_IRQ

LED_OK_A
LED_DENY_A

File: display.kicad_sch Sheet: /DISPLAY & STATUS door lock | - | ESP32-S3, | LEDS/ Palm-vein | MOSFET lock | driver, | 12 V adapter

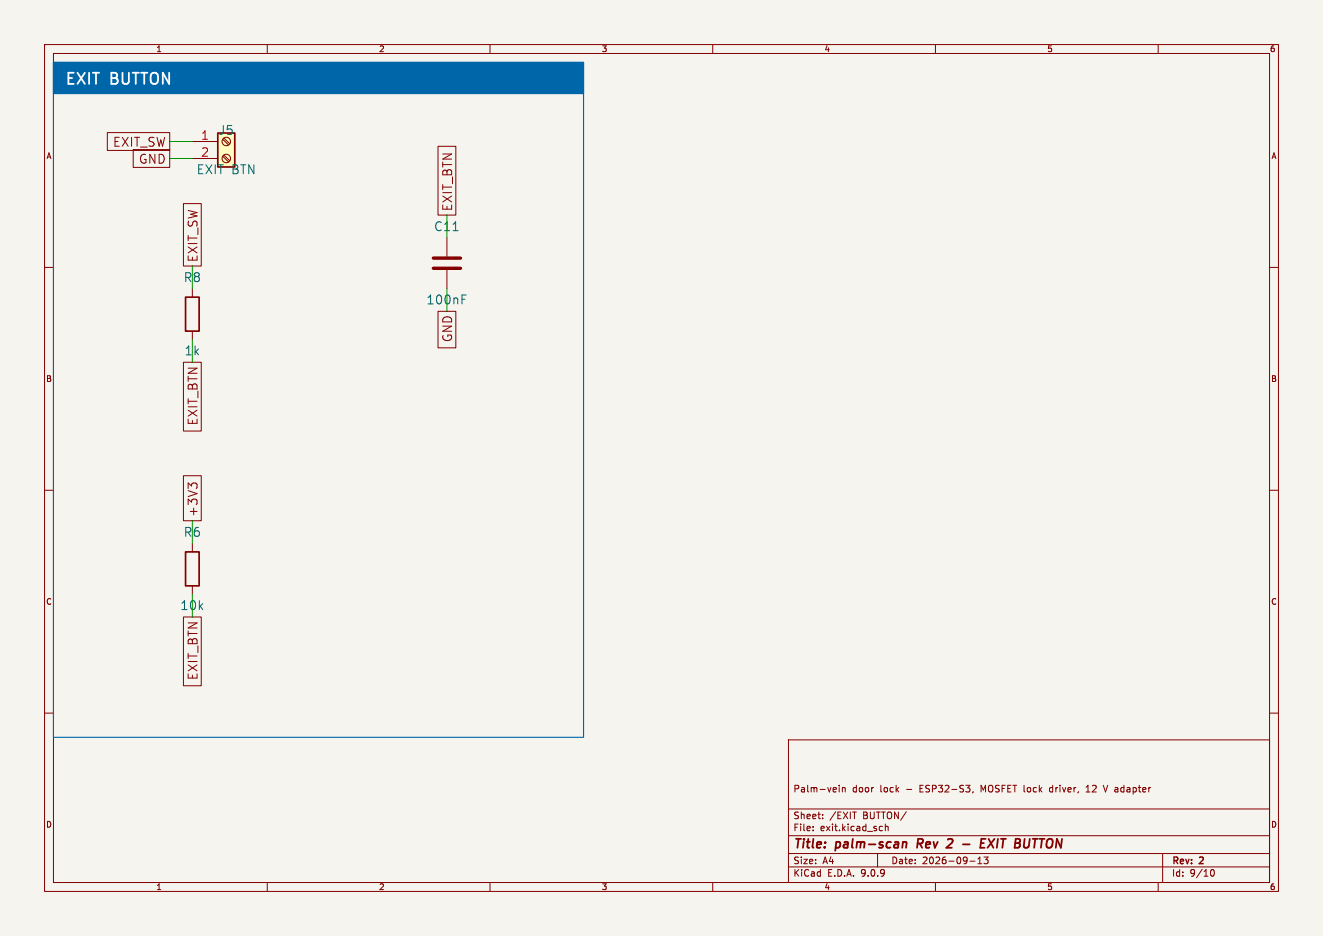
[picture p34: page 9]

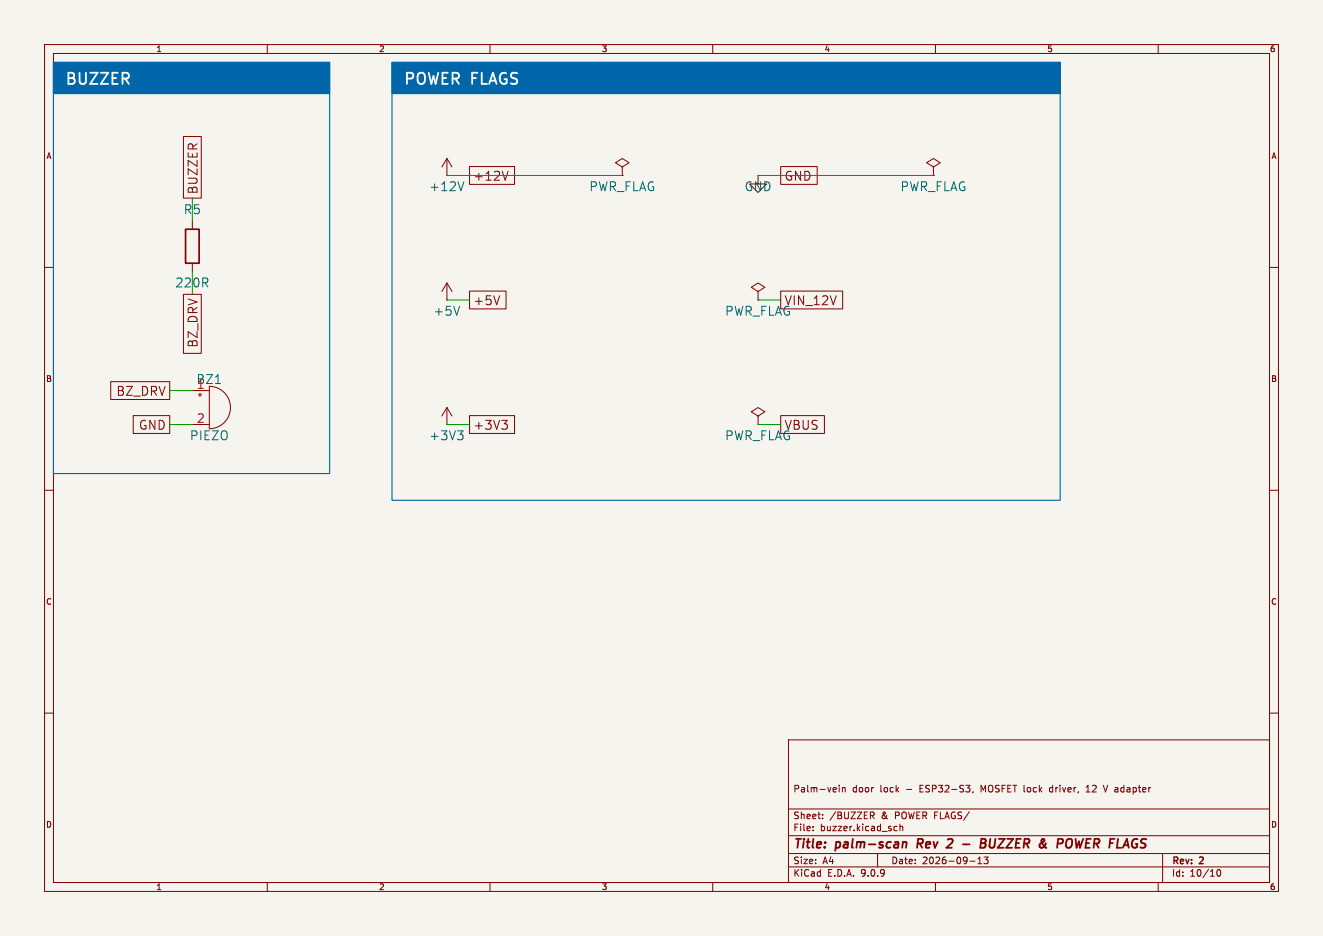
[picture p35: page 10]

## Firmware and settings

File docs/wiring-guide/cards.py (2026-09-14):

"""Per-connection illustrations, the power-flow picture and the scan timeline.

Each `card_*` returns an SVG string sized to its own content. All pin numbers and
net names come from docs/NETLIST.md.
"""

from parts import *  # noqa: F401,F403

PIN_DY = 24          # vertical spacing between pins in a pin block


def pin_block(x, y, pins, title, kind="header", wire_from_x=None, wire_colors=None, plain=True):
    """A zoomed connector: body with numbered pins, net name and plain-words job per pin.

    pins: list of (number, net, plain_words) — plain_words may be "".
    wire_from_x: if given, a coloured wire is drawn from that x into each pin.
    """
    n = len(pins)
    body_h = n * PIN_DY + 14
    o = ""
    # connector body
    if kind == "screw":
        o += rrect(x, y, 44, body_h, r=4, fill=TERMINAL_GREEN, stroke="#1d5f33", sw=1.2)
    elif kind == "picoblade":
        o += rrect(x, y, 44, body_h, r=3, fill="#f4f1e8", stroke="#9a9484", sw=1.2)
    elif kind == "barrel":
        o += rrect(x, y, 44, body_h, r=4, fill="url(#gPlastic)", stroke="#000", sw=1.2)
    elif kind == "usb":
        o += rrect(x, y, 44, body_h, r=8, fill="url(#gMetal)", stroke="#4d5257", sw=1.2)
    else:
        o += rrect(x, y, 44, body_h, r=3, fill="url(#gPlastic)", stroke="#000", sw=1.2)
    o += text(x + 22, y - 8, title, size=11, weight=700, anchor="middle")
    for i, (num, net, words) in enumerate(pins):
        cy = y + 7 + PIN_DY / 2 + i * PIN_DY
        if wire_from_x is not None and wire_colors is not None and wire_colors[i]:
            o += wire(f"M{wire_from_x},{cy} L{x - 2},{cy}", wire_colors[i], width=4.5)
        # pin contact
        if kind == "screw":
            o += circle(x + 22, cy, 7, fill="url(#gMetal)", stroke="#555", sw=0.9)
            o += line(x + 17.5, cy, x + 26.5, cy, stroke="#444", sw=1.6)
            o += rrect(x - 8, cy - 5.5, 8, 11, r=1, fill="#0f3d1f", stroke="#0a2a15", sw=0.6)
        elif kind == "picoblade":
            o += rrect(x + 14, cy - 4, 16, 8, r=1, fill="url(#gCopper)", stroke="#8a6a1e", sw=0.6)
        elif kind == "usb":
            o += rrect(x + 10, cy - 3.5, 24, 7, r=2, fill="#111", stroke="none")
        elif kind == "barrel":
            if i == 0:
                o += circle(x + 22, cy, 8, fill="#0d0d0d", stroke="#666", sw=1)
                o += circle(x + 22, cy, 3, fill="url(#gMetal)", stroke="#333", sw=0.6)
            else:
                o += rrect(x + 8, cy - 4, 28, 8, r=2, fill="url(#gMetal)", stroke="#555", sw=0.8)
        else:
            o += rrect(x + 16, cy - 4, 12, 8, r=1, fill="url(#gCopper)", stroke="#8a6a1e", sw=0.6)
        o += mono(x + 22, cy + 3.5, str(num), size=9, fill="#ffffff" if kind not in ("picoblade", "usb") else INK,
                  anchor="middle", weight=700)
        # labels to the right
        o += mono(x + 56, cy + 4, net, size=11, weight=700)
        if words:
            o += text(x + 150, cy + 4, words, size=10.5, fill=LABEL)
    return o, body_h


def frame(w, h, inner):
    return (f'<svg xmlns="http://www.w3.org/2000/svg" viewBox="0 0 {w} {h}" width="100%" '
            f'style="font-family:{SANS}">' + defs() +
            f'<rect width="{w}" height="{h}" fill="{PAPER}"/>' + inner + "</svg>")


# ------------------------------------------------------------------ 4.1 power in
def card_power() -> str:
    o = wall_adapter(30, 50)
    o += wire("M184,97 C230,97 250,103 300,103", "#2b2b2b", width=6)
    o += barrel_plug(302, 103, facing="right")
    o += text(105, 170, "12 V ⎓ 2 A, plug 5.5 × 2.1 mm, centre ⊕", size=10.5, fill=LABEL, anchor="middle")
    # J8 zoom
    blk, h = pin_block(400, 60, [("◎", "VIN_12V", "centre pin — 12 V positive (+)"),
                                  ("○", "GND", "outer sleeve — ground (−)")],
                       "J8  barrel jack", kind="barrel")
    o += blk
    # J1 alternative
    blk2, h2 = pin_block(400, 172, [("1", "VIN_12V", "bare wire, + (red)"),
                                    ("2", "GND", "bare wire, − (black)")],
                         "J1  screw terminal (alternative)", kind="screw", wire_from_x=330,
                         wire_colors=[WIRE["12V"], WIRE["GND"]])
    o += blk2
    o += text(330, 244, "Use J8 or J1 — never both.", size=10.5, weight=700, fill="#a33", anchor="end")
    return frame(780, 262, o)


# ------------------------------------------------------------------ 4.2 sensor
def card_sensor() -> str:
    o = sensor_module(30, 70, conn_side="right")
    cols = [WIRE["GND"], WIRE["YEL"], WIRE["GRN"], WIRE["12V"]]
    pins = [("1", "GND", "black — ground, the shared return"),
            ("2", "SEN_RX", "yellow — board talks → sensor listens"),
            ("3", "SEN_TX", "green — sensor talks → board listens"),
            ("4", "+5V", "red — 5 V power for the sensor")]
    # sheath from the sensor connector, then fan out
    o += wire("M216,103 C260,103 270,110 300,110", "#8a8f94", width=11)
    blk, h = pin_block(400, 60, pins, "CN1  sensor socket", kind="picoblade")
    o += blk
    for i, c in enumerate(cols):
        cy = 60 + 7 + PIN_DY / 2 + i * PIN_DY
        o += wire(f"M300,110 C330,110 340,{cy} 398,{cy}", c, width=4)
    # direction arrows on the two data wires
    o += flow_arrow(560, 47, 620, 47, color=WIRE["YEL"], sw=3)
    o += text(628, 51, "questions go this way (yellow)", size=9.5, fill=MUTED)
    o += text(120, 190, "Cable comes fitted to the sensor.", size=10.5, fill=LABEL, anchor="middle")
    o += text(120, 206, "Only the plug goes on the board.", size=10.5, fill=LABEL, anchor="middle")
    return frame(780, 230, o)


# ------------------------------------------------------------------ 4.3 display
def card_display() -> str:
    pins = [("1", "+3V3", "power for the screen"),
            ("2", "GND", "ground"),
            ("3", "TFT_CS", "“I’m talking to the screen”"),
            ("4", "TFT_RST", "reset the screen"),
            ("5", "TFT_DC", "command or picture data?"),
            ("6", "SPI_MOSI", "picture data → screen"),
            ("7", "SPI_SCK", "the clock (metronome)"),
            ("8", "+3V3", "backlight power"),
            ("9", "—", "not connected (on purpose)"),
            ("10", "SPI_SCK", "the same clock, for touch"),
            ("11", "TOUCH_CS", "“I’m talking to the touch”"),
            ("12", "SPI_MOSI", "touch commands → touch chip"),
            ("13", "SPI_MISO", "touch position → board"),
            ("14", "TOUCH_IRQ", "“someone touched me”")]
    o = f'<g transform="translate(20,40) scale(1.1)">' + display_module(0, 0) + "</g>"
    # 14 straight gold pins into the header
    blk, h = pin_block(400, 40, pins, "J4  14-pin socket  (screen’s pins go straight in)")
    o += blk
    for i in range(14):
        cy = 40 + 7 + PIN_DY / 2 + i * PIN_DY
        o += line(268, cy, 398, cy, stroke=COPPER, sw=3)
        o += line(268, cy, 398, cy, stroke="#7a5a12", sw=0.7)
    o += text(140, 250, "Pin 1 on the screen must meet pin 1 on the board.", size=10.5, weight=700, anchor="middle")
    o += text(140, 266, "The board’s pin 1 has a square pad.", size=10.5, fill=LABEL, anchor="middle")
    return frame(780, 40 + h + 30, o)


# ------------------------------------------------------------------ 4.4 solenoid
def card_lock() -> str:
    o = f'<g transform="translate(30,120)">' + solenoid_lock(0, 0) + "</g>"
    pins = [("1", "+12V", "always 12 V (after fuse & valve)"),
            ("2", "LOCK_SW", "the board connects this to ground to fire the bolt")]
    blk, h = pin_block(400, 70, pins, "J3  lock terminal", kind="screw")
    o += blk
    p1, p2 = 70 + 7 + PIN_DY / 2, 70 + 7 + PIN_DY / 2 + PIN_DY
    o += wire(f"M70,134 V{p1} H398", WIRE["12V"], width=4.5)
    o += wire(f"M95,134 V{p2} H398", "#e8e8e8", width=4.5)
    o += text(30, 250, "Two wires, either way round. The board switches the − side (a “low-side switch”).",
              size=10.5, fill=LABEL)
    return frame(780, 270, o)


# ------------------------------------------------------------------ 4.5 exit button
def card_exit() -> str:
    o = push_button(110, 120)
    pins = [("1", "EXIT_SW", "goes to the brain through a 1 kΩ guard"),
            ("2", "GND", "ground")]
    blk, h = pin_block(400, 90, pins, "J5  exit-button terminal", kind="screw", wire_from_x=170,
                       wire_colors=["#e8e8e8", WIRE["GND"]])
    o += blk
    o += text(30, 190, "Any momentary push button.", size=10.5, fill=LABEL)
    o += text(30, 206, "Pressed = the two wires touch = the board sees it.", size=10.5, fill=LABEL)
    return frame(780, 230, o)


# ------------------------------------------------------------------ 4.6 panel LEDs
def card_leds() -> str:
    o = ""
    pins = [("1", "GND", "both short legs (−) join here"),
            ("2", "LED_OK_A", "green long leg (+) — “recognised”"),
            ("3", "LED_DENY_A", "red long leg (+) — “not recognised”")]
    blk, h = pin_block(400, 70, pins, "J7  panel LED header", kind="header")
    o += blk
    p1, p2, p3 = (70 + 7 + PIN_DY / 2 + i * PIN_DY for i in range(3))
    # LEDs lie on their side, legs pointing at the header: long leg (+) below, short leg (−) above
    gx, gy = 250, 104
    rx, ry = 130, 150
    o += f'<g transform="rotate(-90 {gx} {gy})">' + led_5mm(gx, gy, "#3aa655") + "</g>"
    o += f'<g transform="rotate(-90 {rx} {ry})">' + led_5mm(rx, ry, "#d62828") + "</g>"
    o += text(gx - 22, gy + 4, "green", size=10, fill=MUTED, anchor="end")
    o += text(rx - 22, ry + 4, "red", size=10, fill=MUTED, anchor="end")
    # green: short leg (−) tip (gx+24, gy-4) → pin 1 ; long leg (+) tip (gx+30, gy+4) → pin 2
    o += wire(f"M{gx+24},{gy-4} H300 V{p1} H398", WIRE["GND"], width=3.5)
    o += wire(f"M{gx+30},{gy+4} H320 V{p2} H398", WIRE["GRN"], width=3.5)
    # red: long leg (+) tip → pin 3 straight ; short leg (−) tip → up and over, joins the black at pin 1
    o += wire(f"M{rx+30},{ry+4} H340 V{p3} H398", "#d62828", width=3.5)
    o += wire(f"M{rx+24},{ry-4} H170 V40 H350 V{p1}", WIRE["GND"], width=3.5)
    o += circle(350, p1, 4, fill="#222", stroke="#fff", sw=1)
    o += text(260, 32, "the two − wires join into one", size=9, fill=MUTED, anchor="middle")
    o += text(30, 215, "Long leg = +. No resistor needed in the wire — the board already has them (150 Ω each).",
              size=10.5, fill=LABEL)
    return frame(780, 235, o)


# ------------------------------------------------------------------ 4.7 USB-C
def card_usb() -> str:
    o = laptop(30, 60)
    o += wire("M184,110 C230,110 250,118 300,118", WIRE["USB"], width=5.5)
    o += rrect(298, 112, 26, 12, r=5, fill="url(#gMetal)", stroke="#4d5257", sw=0.9)
    pins = [("A/B", "VBUS", "5 V from the laptop — sensed, not used as power"),
            ("A/B", "USB_D+ / D−", "the data pair, protected by D3"),
            ("A5/B5", "CC1 / CC2", "5.1 kΩ each — tells the laptop “I’m a device”"),
            ("—", "GND / shield", "ground")]
    blk, h = pin_block(400, 60, pins, "J2  USB-C socket", kind="usb")
    o += blk
    o += text(105, 190, "Either way up. Programming, logs, updates.", size=10.5, fill=LABEL, anchor="middle")
    return frame(780, 215, o)


# ------------------------------------------------------------------ 4.8 debug header
def card_debug() -> str:
    o = usb_serial_dongle(60, 100)
    pins = [("1", "+3V3", "reference only — do NOT feed power in here"),
            ("2", "TXD0", "board talks → dongle’s RX"),
            ("3", "RXD0", "dongle’s TX → board listens"),
            ("4", "GND", "ground")]
    blk, h = pin_block(400, 60, pins, "J6  debug header (optional)", kind="header", wire_from_x=140,
                       wire_colors=[WIRE["3V3"], WIRE["GRN"], "#e8e8e8", WIRE["GND"]])
    o += blk
    o += text(95, 160, "Only if USB ever stops working.", size=10.5, fill=LABEL, anchor="middle")
    o += text(95, 176, "Dongle must be a 3.3 V type.", size=10.5, weight=700, fill="#a33", anchor="middle")
    return frame(780, 200, o)


# ------------------------------------------------------------------ 6. power flow
def power_tree() -> str:
    W, H = 900, 420
    o = ""

    def node(x, y, w, h, title, sub, fill="#f5f5f5", stroke="#999"):
        s = rrect(x, y, w, h, r=8, fill=fill, stroke=stroke, sw=1.2)
        s += text(x + w / 2, y + 22, title, size=13, weight=700, anchor="middle")
        s += text(x + w / 2, y + 40, sub, size=10.5, fill=LABEL, anchor="middle")
        return s

    def pipe(x1, y1, x2, y2, color, width, label=""):
        s = wire(f"M{x1},{y1} L{x2},{y2}", color, width=width, outline=False)
        if label:
            s += text((x1 + x2) / 2, (y1 + y2) / 2 - 9, label, size=10.5, fill=MUTED, anchor="middle")
        return s

    # source
    o += node(20, 170, 130, 56, "Wall adapter", "12 V · up to 2 A", fill="#ffffff")
    o += pipe(150, 198, 190, 198, WIRE["12V"], 10, "≤ 1.5 A")
    o += node(190, 170, 90, 56, "F1", "fuse", fill="#fff3e0", stroke="#e0a040")
    o += pipe(280, 198, 310, 198, WIRE["12V"], 10)
    o += node(310, 170, 90, 56, "D1", "one-way valve", fill="#fff3e0", stroke="#e0a040")
    o += pipe(400, 198, 440, 198, WIRE["12V"], 10)
    # 12 V bus (vertical bar)
    o += rrect(440, 60, 14, 290, r=4, fill=WIRE["12V"], stroke="none")
    o += text(447, 48, "+12 V rail", size=10.5, weight=700, anchor="middle")
    o += pipe(440, 300, 400, 300, WIRE["12V"], 6)
    o += node(270, 272, 130, 56, "C1  470 µF tank", "smooths the rail", fill="#e8f4ff", stroke="#7aa7d9")
    o += pipe(440, 340, 260, 340, WIRE["12V"], 6)
    o += node(140, 312, 120, 56, "D7  surge clamp", "sits across the rail", fill="#fff3e0", stroke="#e0a040")
    # branches
    o += pipe(454, 90, 500, 90, WIRE["12V"], 8, "0.3 A")
    o += node(500, 62, 100, 56, "U2", "12 V → 3.3 V", fill="#e8f5e9", stroke="#4caf50")
    o += pipe(600, 90, 680, 90, WIRE["3V3"], 8, "0.15 – 0.5 A")
    o += node(680, 62, 200, 56, "3.3 V rail", "brain · screen · LEDs · beeper", fill="#fffbe6", stroke="#e9c46a")

    o += pipe(454, 170, 500, 170, WIRE["12V"], 8, "0.3 A")
    o += node(500, 142, 100, 56, "U3", "12 V → 5 V", fill="#e8f5e9", stroke="#4caf50")
    o += pipe(600, 170, 680, 170, WIRE["5V"], 8, "0.35 – 0.65 A")
    o += node(680, 142, 200, 56, "5 V rail", "palm sensor only", fill="#fff1e0", stroke="#f77f00")

    o += pipe(454, 240, 680, 240, WIRE["12V"], 8, "0.8 – 1 A, ≤ 5 s at a time")
    o += node(680, 212, 200, 56, "Solenoid", "through Q1, the electronic switch", fill="#f3f3f3", stroke="#999")

    o += text(20, 396, "Everything right of D1 is protected: reversed adapter → nothing flows; short on the board → F1 opens, then resets when cool.", size=10.5, fill=LABEL)
    o += text(20, 414, "At the adapter: ≈ 0.25 A idle, ≈ 1.2 A while the bolt is pulled — well inside a 2 A adapter.", size=10.5, fill=LABEL)
    return frame(W, H, o)


# ------------------------------------------------------------------ 7. scan timeline
def scan_timeline() -> str:
    W, H = 900, 300
    o = ""
    steps = [
        ("Power on", "yellow light on\nthe board; screen\nshows “starting”", "#f4c20d"),
        ("Sensor ready", "sensor sends READY\non the green wire", "#3aa655"),
        ("Waiting", "screen: “hold your\npalm” — sensor\nwatches for a hand", "#457b9d"),
        ("Palm seen", "board asks VERIFY\non the yellow wire", "#f4c20d"),
        ("Answer", "sensor replies:\nwho + score\n(about 1 second)", "#3aa655"),
        ("Match", "green LED · 1 beep\n“Welcome, <name>”\nbolt pulled for 5 s", "#2a9d8f"),
        ("No match", "red LED · 2 beeps\n“Not recognised”", "#d62828"),
    ]
    x0, y0, w, gap = 14, 52, 118, 8
    o += line(x0, y0 + 30, x0 + 7 * (w + gap) - gap, y0 + 30, stroke="#bbb", sw=2, extra='marker-end="url(#arrowMuted)"')
    for i, (title, sub, col) in enumerate(steps):
        x = x0 + i * (w + gap)
        o += circle(x + w / 2, y0 + 30, 9, fill=col, stroke="#fff", sw=2)
        o += rrect(x, y0 + 60, w, 104, r=8, fill="#fafafa", stroke="#ddd", sw=1)
        o += rrect(x, y0 + 60, w, 6, r=3, fill=col, stroke="none")
        o += text(x + w / 2, y0 + 88, title, size=12.5, weight=700, anchor="middle")
        for j, ln in enumerate(sub.split("\n")):
            o += text(x + w / 2, y0 + 110 + j * 15, ln, size=10.2, fill=LABEL, anchor="middle")
    o += path(f"M{x0 + 5 * (w + gap) + w / 2},{y0 + 164} v18", stroke="#2a9d8f", sw=2)
    o += path(f"M{x0 + 6 * (w + gap) + w / 2},{y0 + 164} v18", stroke="#d62828", sw=2)
    o += text(x0 + 5 * (w + gap) + w / 2, y0 + 196, "→ back to Waiting", size=10, fill=MUTED, anchor="middle")
    o += text(x0 + 6 * (w + gap) + w / 2, y0 + 196, "→ back to Waiting", size=10, fill=MUTED, anchor="middle")
    o += text(14, 28, "One scan, start to finish", size=14, weight=700)
    return frame(W, 262, o)


if __name__ == "__main__":
    import sys
    fn = sys.argv[1]
    sys.stdout.write(globals()[fn]())


# ------------------------------------------------------------------ 5. part icons
def icon(kind: str) -> str:
    """A small 'what it looks like' picture for the parts table (64×40 viewBox)."""
    o = ""
    if kind == "module":
        o += rrect(6, 4, 52, 32, r=2, fill="#cfd3d7", stroke="#6a6f74", sw=0.8)
        o += rrect(6, 4, 52, 8, r=2, fill="#0f3a25", stroke="none")
        o += path("M10,10 h4 v-3 h4 v3 h4 v-3 h4 v3 h4 v-3 h4 v3 h4 v-3 h4 v3 h4 v-3 h4 v3", stroke=COPPER, sw=1)
        o += rrect(10, 15, 44, 18, r=1, fill="url(#gMetal)", stroke="#5c6166", sw=0.6)
    elif kind == "regulator":
        o += rrect(14, 4, 36, 24, r=2, fill="#1b1b1b", stroke="#000", sw=0.7)
        o += mono(32, 19, "R-78E", size=7, fill="#fff", anchor="middle", weight=700)
        for i in range(3):
            o += rrect(21 + i * 10, 28, 3, 8, r=0.5, fill=METAL, stroke="none")
    elif kind == "fuse":
        o += rrect(14, 12, 36, 16, r=1.5, fill="#e8dcc0", stroke="#8a7a50", sw=0.7)
        o += rrect(14, 12, 7, 16, r=1, fill=METAL, stroke="none")
        o += rrect(43, 12, 7, 16, r=1, fill=METAL, stroke="none")
    elif kind == "diode":
        o += rrect(14, 12, 36, 16, r=1.5, fill="#151515", stroke="#000", sw=0.7)
        o += rrect(14, 12, 6, 16, r=1, fill=METAL, stroke="none")
        o += rrect(44, 12, 6, 16, r=1, fill=METAL, stroke="none")
        o += rrect(22, 12, 4, 16, r=0, fill="#eee", stroke="none")
    elif kind == "cap_big":
        o += electrolytic(32, 20, r=15, label="470µ")
    elif kind == "cap_small":
        o += electrolytic(32, 20, r=11, label="100µ")
    elif kind == "ceramics":
        for i, w in enumerate((10, 14, 18)):
            o += rrect(8 + i * 18, 20 - w / 4, w, w / 2, r=0.8, fill="#c8b48a", stroke="#7a6a45", sw=0.5)
    elif kind == "mosfet":
        o += rrect(20, 8, 24, 20, r=1.5, fill="#151515", stroke="#000", sw=0.7)
        for x in (24, 38):
            o += rrect(x, 28, 3, 6, r=0.4, fill=METAL, stroke="none")
        o += rrect(31, 2, 3, 6, r=0.4, fill=METAL, stroke="none")
    elif kind == "esd":
        o += rrect(20, 8, 24, 20, r=1.5, fill="#151515", stroke="#000", sw=0.7)
        for x in (23, 31, 39):
            o += rrect(x, 28, 3, 6, r=0.4, fill=METAL, stroke="none")
            o += rrect(x, 2, 3, 6, r=0.4, fill=METAL, stroke="none")
    elif kind == "resistor":
        o += rrect(16, 14, 32, 12, r=1, fill="#222", stroke="#000", sw=0.6)
        o += rrect(16, 14, 6, 12, r=0.8, fill=METAL, stroke="none")
        o += rrect(42, 14, 6, 12, r=0.8, fill=METAL, stroke="none")
        o += mono(32, 24, "103", size=7, fill="#ddd", anchor="middle")
    elif kind == "buzzer":
        o += buzzer(32, 20, r=16)
    elif kind == "buttons":
        o += tact_button(10, 10, size=18)
        o += tact_button(36, 10, size=18)
    elif kind == "led":
        o += led_0603(26, 16, "#f4c20d")
        o += circle(29, 18, 9, fill="#f4c20d", stroke="none", extra='fill-opacity="0.25"')
    return (f'<svg xmlns="http://www.w3.org/2000/svg" viewBox="0 0 64 40" width="64" height="40" '
            f'style="display:block">{defs()}{o}</svg>')

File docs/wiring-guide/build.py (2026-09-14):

#!/usr/bin/env python3
"""Build the palm-scan Wiring & Components Guide (HTML → PDF).

    python3 build.py            # writes wiring-guide.html and ../palm-scan-wiring-guide.pdf

Two render passes: the first finds which page each heading lands on, the second
fills those numbers into the contents page. Needs the Playwright Chromium that
lives in ~/.cache/ms-playwright (any recent Chrome/Chromium works: set CHROME=...).
"""

from __future__ import annotations

import html
import os
import re
import subprocess
from pathlib import Path

import cards
import master

HERE = Path(__file__).parent
OUT_HTML = HERE / "wiring-guide.html"
OUT_PDF = HERE.parent / "palm-scan-wiring-guide.pdf"
CHROME = os.environ.get("CHROME") or next(
    iter(sorted(Path.home().glob(".cache/ms-playwright/chromium-*/chrome-linux64/chrome"))), None)

DOC_TITLE = "palm-scan · Wiring & Components Guide"
REV = "Controller board Rev 2.4 · Guide rev A · 14 September 2026"

# ----------------------------------------------------------------------------- CSS
CSS = r"""
@page { size: A4 portrait; margin: 22mm 20mm 24mm 20mm;
  @top-left { content: "palm-scan · Wiring & Components Guide"; font-family: Lato; font-size: 8.5pt; color: #777; letter-spacing: .02em; }
  @top-right { content: "Rev 2.4"; font-family: Lato; font-size: 8.5pt; color: #777; }
  @bottom-center { content: counter(page); font-family: Lato; font-size: 9pt; color: #555; } }
@page cover { margin: 0; @top-left { content: none } @top-right { content: none } @bottom-center { content: none } }
@page wide  { size: A3 landscape; margin: 10mm 12mm 12mm 12mm;
  @top-left { content: "palm-scan · Wiring & Components Guide · Section 3 — complete wiring diagram"; font-family: Lato; font-size: 8.5pt; color: #777; }
  @top-right { content: "Rev 2.4"; font-family: Lato; font-size: 8.5pt; color: #777; } }

:root { --ink:#1c1c1c; --navy:#1f3a5f; --muted:#6b6b6b; --rule:#d9d9d9; --amber:#b7791f; --amberbg:#fff8e6; --eng:#f3f5f8; }
html { -webkit-print-color-adjust: exact; print-color-adjust: exact; }
body { font-family: P052, "TeX Gyre Pagella", Palatino, "Liberation Serif", serif; font-size: 10.2pt; line-height: 1.45; color: var(--ink); margin: 0; }
section.page { break-after: page; }
section.cover { page: cover; break-after: page; }
section.wide { page: wide; break-after: page; }

h1, h2, h3, h4, .sans { font-family: Lato, "Liberation Sans", sans-serif; }
h1 { font-size: 22pt; font-weight: 800; letter-spacing: -.01em; margin: 0 0 4mm; padding-bottom: 2mm; border-bottom: 1.5pt solid var(--navy); break-after: avoid; }
h1 .num { color: var(--navy); margin-right: 3mm; }
h2 { font-size: 14pt; font-weight: 700; margin: 6mm 0 2mm; break-after: avoid; }
h2 .num { color: var(--navy); margin-right: 2.5mm; }
h3 { font-size: 11pt; font-weight: 700; margin: 5mm 0 1.5mm; text-transform: uppercase; letter-spacing: .06em; color: #333; break-after: avoid; }
p { margin: 0 0 2.6mm; text-align: left; orphans: 3; widows: 3; }
p.lead { font-size: 12pt; line-height: 1.5; color: #222; }
ul, ol { margin: 0 0 3mm; padding-left: 6mm; }
li { margin-bottom: 1.2mm; }
strong { font-weight: 700; }
code, .mono { font-family: "Ubuntu Mono", "DejaVu Sans Mono", monospace; font-size: 9.6pt; background: #f2f2f2; padding: 0 .25em; border-radius: 2px; }
small, .small { font-size: 9pt; color: var(--muted); }

figure { margin: 2mm 0 3.5mm; break-inside: avoid; }
figure.card { width: 80%; margin-left: auto; margin-right: auto; }
figure svg { display: block; width: 100%; height: auto; }
figcaption { font-family: Lato; font-size: 8.8pt; color: var(--muted); margin-top: 1.5mm; line-height: 1.35; }
figcaption b { color: #333; font-weight: 700; }
figure.half { width: 62%; margin-left: auto; margin-right: auto; }
figure.w85 { width: 85%; margin-left: auto; margin-right: auto; }

table { border-collapse: collapse; width: 100%; font-family: Lato; font-size: 8.8pt; margin: 1.5mm 0 3mm; break-inside: auto; }
th { text-align: left; font-weight: 700; color: var(--navy); border-bottom: 1.2pt solid var(--navy); padding: 1.4mm 1.6mm; vertical-align: bottom; }
td { border-bottom: .5pt solid var(--rule); padding: 1.1mm 1.6mm; vertical-align: top; }
tr { break-inside: avoid; }
table.keep { break-inside: avoid; }
td.nw { white-space: nowrap; }
td.ic { width: 14mm; padding-top: 1mm; } td.ic svg { width: 14mm; height: auto; }
th.w-ref { width: 9mm; } th.w-ic { width: 14mm; } th.w-part { width: 24mm; }
table.dense { font-size: 8.3pt; } table.dense td { padding: .9mm 1.4mm; }
h2.newpage { break-before: page; margin-top: 0; }
td.c, th.c { text-align: center; }
td.m { font-family: "Ubuntu Mono", monospace; font-size: 9.2pt; white-space: nowrap; }
.sw { display: inline-block; width: 22px; height: 8px; border-radius: 4px; border: 1px solid #333; vertical-align: middle; margin-right: 4px; }

.eng { background: var(--eng); border-left: 3pt solid var(--navy); padding: 2mm 3.5mm 1.6mm; margin: 2.5mm 0 3mm; font-size: 9.2pt; line-height: 1.4; break-inside: avoid; }
.eng .tag, .warn .tag, .plain .tag { font-family: Lato; font-size: 7.6pt; font-weight: 700; letter-spacing: .12em; text-transform: uppercase; display: block; margin-bottom: 1mm; }
.eng .tag { color: var(--navy); }
.warn { background: var(--amberbg); border-left: 3pt solid var(--amber); padding: 2mm 3.5mm 1.6mm; margin: 2.5mm 0 3mm; font-size: 9.5pt; line-height: 1.4; break-inside: avoid; }
.warn ul, .eng ul { margin-bottom: 1mm; } .warn li { margin-bottom: .6mm; }
.warn .tag { color: var(--amber); }
.plain { border: .6pt solid var(--rule); border-radius: 2mm; padding: 2mm 3.5mm 1.6mm; margin: 2.5mm 0 3mm; break-inside: avoid; }
.plain .tag { color: #2f8f4e; }
.badge { display: inline-block; font-family: Lato; font-weight: 700; font-size: 8.5pt; color: #fff; background: var(--navy); border-radius: 50%; width: 5.2mm; height: 5.2mm; line-height: 5.2mm; text-align: center; margin-right: 1.5mm; vertical-align: middle; }
.cols2 { column-count: 2; column-gap: 8mm; }
.kv { display: grid; grid-template-columns: 34mm 1fr; gap: 1mm 4mm; font-size: 10pt; margin: 2mm 0 4mm; }
.kv b { font-family: Lato; font-size: 9pt; color: var(--navy); }
.check li { list-style: none; position: relative; padding-left: 7mm; }
.check li::before { content: ""; position: absolute; left: 0; top: 1.2mm; width: 3.6mm; height: 3.6mm; border: 1pt solid #333; border-radius: .6mm; }
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

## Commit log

2026-09-14 Schematic Rev 2.4: ESP32-S3 palm-vein door lock controller
    Hardware design phase complete. KiCad 9 project with 10 hierarchical
    sheets generated from gen_schematic.py, ERC 0/0, netlist cross-checked
    against docs/NETLIST.md (153/153 pins). Two design-review rounds
    applied (19 findings): lock moved behind reverse-protection diode,
    sensor on 5 V rail, display on 3.3 V, TVS + polyfuse on the 12 V input,
    ST7789 SDO left unconnected to avoid the MISO conflict with XPT2046.
    docs/ holds BOM, power budget, datasheet extracts and the review log.
    firmware/ and ml/ are placeholders for the next phases.
    Claude-Session: https://claude.ai/code/session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
    [buzzer.kicad_sch, display.kicad_sch, exit.kicad_sch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]
2026-09-14 README: frame as palm-vein scanning platform, door release is a demo app
    Claude-Session: https://claude.ai/code/session_01PASUS3ZjHN9rYEA7oxiDuL
2026-09-14 Add illustrated Wiring & Components Guide (PDF + generator)
    23-page A4 guide with an A3 fold-out master wiring diagram. Every
    connection drawn as the physical objects with real wire colours, one
    page per connection (pin table, plain-words explanation, engineering
    detail, pre-connection checks), a parts table with icons, the power
    tree, the scan timeline and a bring-up checklist. All pin numbers and
    net names come from docs/NETLIST.md.
    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
2026-09-14 Add ngspice simulation of the solenoid driver (Q1 + D2), with and without flyback
    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
